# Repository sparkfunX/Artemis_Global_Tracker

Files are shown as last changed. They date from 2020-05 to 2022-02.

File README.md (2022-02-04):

# Artemis Global Tracker

An open source global satellite tracker utilising the [SparkFun Artemis module](https://www.sparkfun.com/products/15484),
[Iridium 9603N satellite transceiver](https://www.iridium.com/products/iridium-9603/) and [u-blox ZOE-M8Q GNSS](https://www.u-blox.com/en/product/zoe-m8-series).

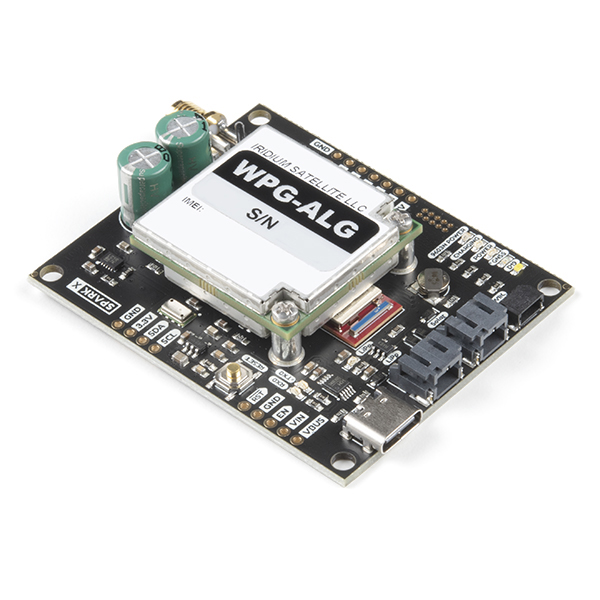
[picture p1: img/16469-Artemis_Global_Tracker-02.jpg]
SparkX Artemis Global Tracker (SPX-16469) (https://www.sparkfun.com/products/16469)


[*SparkX Artemis Global Tracker (SPX-16469)*](https://www.sparkfun.com/products/16469)

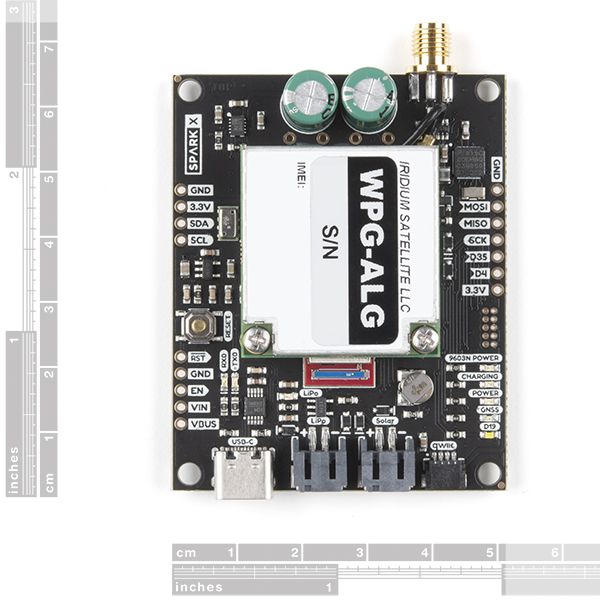
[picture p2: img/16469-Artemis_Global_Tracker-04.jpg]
SparkX Artemis Global Tracker (SPX-16469) (https://www.sparkfun.com/products/16469)


[*SparkX Artemis Global Tracker (SPX-16469)*](https://www.sparkfun.com/products/16469)

## Retired Product

The SparkX Artemis Global Tracker (SPX-16469) has been replaced by the [SparkFun Artemis Global Tracker (WRL-18712)](https://www.sparkfun.com/products/18712).

## Repository Contents

- **/Documentation** - Documentation for the hardware and the full GlobalTracker example
- **/Hardware** - Eagle PCB, SCH and LBR design files
- **/Software** - Arduino examples
- **/Tools** - Tools to help: configure the full GlobalTracker example via USB or remotely via Iridium messaging; and track and map its position
- **/binaries** - binary files for the examples which you can upload using the [Artemis Firmware Upload GUI](https://github.com/sparkfun/Artemis-Firmware-Upload-GUI) instead of the Arduino IDE
- **LICENSE.md** contains the licence information

## Documentation

- [Hardware overview](Documentation/Hardware_Overview/README.md): an overview of the hardware
- The Artemis pin allocation is summarised [here](Documentation/Hardware_Overview/ARTEMIS_PINS.md)
- [Message Format](Documentation/Message_Format/README.md): a definition of the message format and fields (both binary and text) for the full GlobalTracker example
- [GlobalTracker FAQs](Documentation/GlobalTracker_FAQs/README.md): information to help you operate and configure the AGT

## License Information

This product is _**open source**_!

Please review the LICENSE.md file for license information.

If you have any questions or concerns on licensing, please contact technical support on our [SparkFun forums](https://forum.sparkfun.com/viewforum.php?f=123).

Distributed as-is; no warranty is given.

- Your friends at SparkFun.

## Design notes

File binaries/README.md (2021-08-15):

# Artemis Global Tracker: Binaries

This folder contains the binary files for some of the AGT examples.

You can upload these to the AGT using the [Artemis Firmware Upload GUI](https://github.com/sparkfun/Artemis-Firmware-Upload-GUI) instead of the Arduino IDE.
Which is handy if you want to quickly update the firmware in the field, or are not familiar with the IDE.

To use:

* Download and extract the [AGT repo ZIP](https://github.com/sparkfun/Artemis_Global_Tracker/archive/main.zip)
* Download and extract the [AFU repo ZIP](https://github.com/sparkfun/Artemis-Firmware-Upload-GUI/archive/master.zip)
* Run the AFU artemis_firmware_uploader_gui executable for your platform
  * **/Windows** contains the Windows .exe
  * **/OSX** contains an executable for macOS X
  * **/Linux** contains an executable built on Ubuntu
  * **/Raspberry_Pi__Debian** contains an executable for Raspberry Pi 4 (Debian Buster)
* Select the AGT firmware file you'd like to upload (should end in *.bin*)
  * **Example1 - Blink** powers up the tracker and blinks the white LED (connected to D19).
  * **Example14 - Simple Tracker** is a simple tracker which: wakes up every INTERVAL minutes; gets a GNSS fix; reads the PHT sensor; and sends all the data in a SBD message.
  * **Example15 - Better Tracker** is a better tracker where the INTERVAL, RBDESTINATION and RBSOURCE are stored in 'EEPROM' (Flash) and can be configured via Iridium SBD messages.
  * **Example16 - Global Tracker** is the full Global Tracker. All of the settings can be configured via USB-C or remotely via an Iridium SBD message using the [Artemis Global Tracker Configuration Tool (AGTCT)](../Tools).
  * **Example19 - Serial Terminal** allows the AGT to be operated via a simple Serial Terminal interface. Open the Serial Monitor or a Terminal Emulator at 115200 baud to see the menu.
* Attach the AGT target board using USB
* Select the COM port (hit Refresh to refresh the list of USB devices)
* Press Upload

The GUI does take a few seconds to load and run. _**Don't Panic**_ if the GUI does not start right away.

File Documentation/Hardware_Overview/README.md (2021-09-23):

# Artemis Global Tracker: Hardware Overview

The Artemis Global Tracker is an open source satellite tracker utilising the [SparkFun Artemis module](https://www.sparkfun.com/products/15484),
[Iridium 9603N satellite transceiver](https://www.iridium.com/products/iridium-9603/) and [u-blox ZOE-M8Q GNSS
](https://www.u-blox.com/en/product/zoe-m8-series).

The hardware design is based extensively on the:
- [SparkFun Artemis module](https://www.sparkfun.com/products/15484)
- [SparkFun Thing Plus - Artemis](https://www.sparkfun.com/products/15574) battery charging circuit and USB-C interface
- [SparkFun Qwiic Iridium 9603N](https://www.sparkfun.com/products/16394) Iridium 9603N, LTC3225 supercapacitor charger and ADM4210 inrush current circuit
- [SparkFun GPS Breakout - ZOE-M8Q](https://www.sparkfun.com/products/15193) ZOE connections and backup battery circuit

The design also makes use of the:
- [Skyworks AS179-92LF GaAs RF Switch](https://www.skyworksinc.com/products/switches/as179-92lf)
- [Maxtena M1600HCT-P-SMA antenna](https://www.maxtena.com/products/f-gps/m1600hct-p-sma/) which is tuned for Iridium, GPS and GLONASS
  - [Available from SparkFun](https://www.sparkfun.com/products/16838)
- [TE / MEAS Switzerland MS8607](https://www.te.com/usa-en/product-CAT-BLPS0018.html) combined pressure, humidity and temperature sensor

The full schematic for the tracker can be found [here](../../Hardware/Schematic.pdf)

Additional information can be found in the [FAQs](../GlobalTracker_FAQs/README.md)

## The Artemis Module

The heart of the tracker is, of course, the most excellent Artemis module from SparkFun. The pad allocation is defined [here](../Hardware_Overview/ARTEMIS_PINS.md).

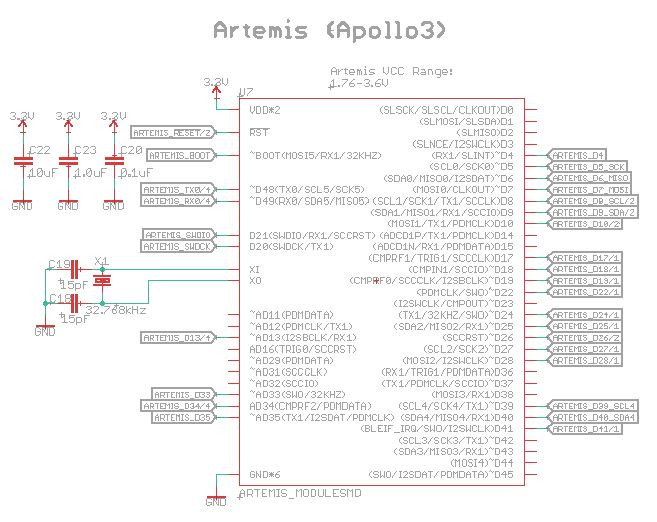
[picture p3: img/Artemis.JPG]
Artemis


## Power Options

The tracker can be powered from:
- the USB-C interface
- a LiPo battery (recharged via the USB-C interface)
- an external solar panel or battery pack (6V maximum)

3 x Energizer&trade; Ultimate Lithium AA or AAA cells are recommended as they will work down to -40C

Low-forward-voltage diodes isolate the power sources from each other. You can have the USB, LiPo and external cells connected simultaneously, it will do no harm.
The tracker will preferentially draw power from USB if it is connected.

If the USB is disconnected, the tracker will preferentially draw power from the external cells. If you have the external cells connected, you may as well disconnect the LiPo.

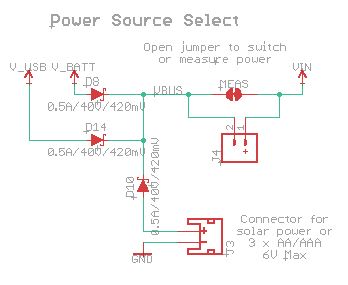
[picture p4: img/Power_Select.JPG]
Power_Select


J4 (VBUS -> VIN) can be used to measure the current draw or to connect a power switch after you open the MEAS split pad.

## USB Interface

The USB interface is taken directly from the [SparkFun Thing Plus - Artemis](https://www.sparkfun.com/products/15574).

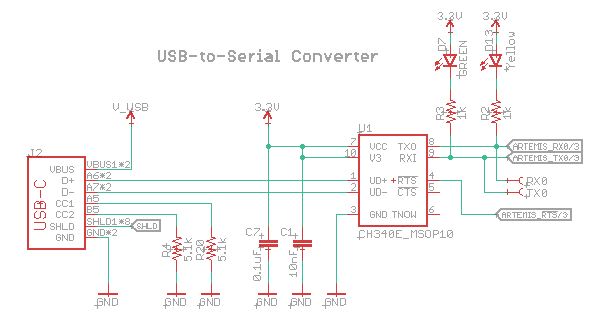
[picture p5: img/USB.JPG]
USB


## LiPo Charger

The LiPo charger circuit is taken directly from the [SparkFun Thing Plus - Artemis](https://www.sparkfun.com/products/15574).

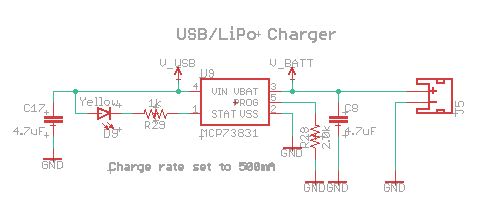
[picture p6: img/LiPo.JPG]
LiPo


## 3.3V Regulator

3.3V power for the tracker is regulated by an AP2112K regulator. Its 50uA quiescent current draw means it can be powered continuously without
depleting the batteries during sleep.

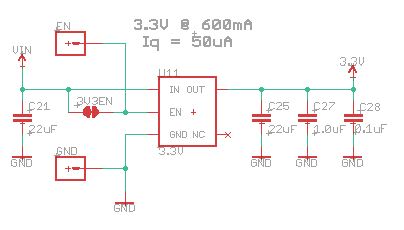
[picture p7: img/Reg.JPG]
Reg


If you want to completely disable the regulator to minimise the current draw, you can do so by opening the 3.3V_EN split pad. The EN pin can then be used to enable/disable the regulator.
Pull EN low to disable the regulator, pull it up to VIN to enable it. EN could also be driven by a logic signal from an external timer circuit.

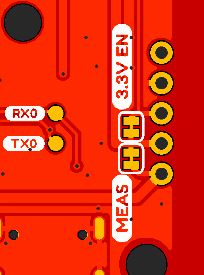
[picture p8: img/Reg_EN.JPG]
Reg_EN


## ZOE-M8Q

GNSS data is provided by the u-blox ZOE-M8Q as used on the [SparkFun GPS Breakout - ZOE-M8Q](https://www.sparkfun.com/products/15193).

Connection to the Artemis is via I2C port 1. The serial and safeboot pins are available on test pads to allow the ZOE firmware to be updated.

Geofence alerts from the ZOE can be produced on PIO14, which is connected to Artemis pin D10.

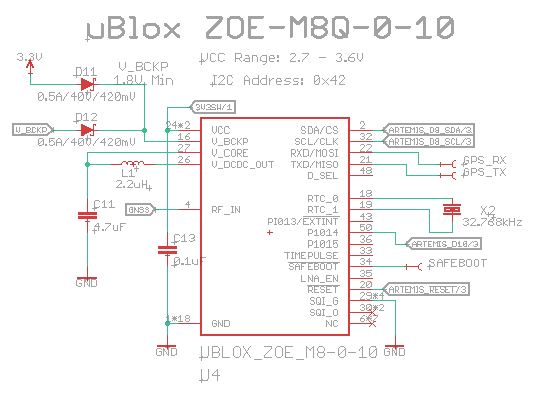
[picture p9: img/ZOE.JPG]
ZOE


Back-up power for the ZOE is drawn preferentially from the 3.3V rail, but there is a small back-up battery too to keep the ZOE's clock running
when all other power sources have been disconnected. The battery recharges only when USB power is connected (to help minimise the 3.3V current
draw during sleep).

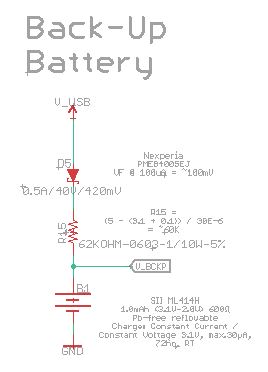
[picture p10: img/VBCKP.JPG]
VBCKP


3.3V power for the ZOE is switched via a FET. The same switched power also feeds the antenna switch when the GNSS is in use.

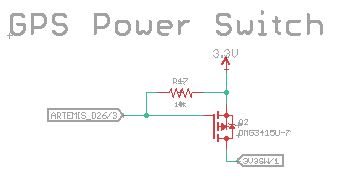
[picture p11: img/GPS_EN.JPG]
GPS_EN


## Iridium 9603N

The tracker uses the same Iridium 9603N transceiver as the [SparkFun Qwiic Iridium 9603N](https://www.sparkfun.com/products/16394).

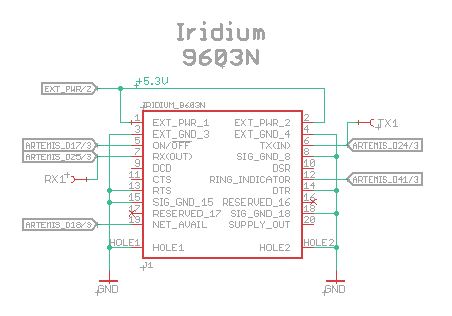
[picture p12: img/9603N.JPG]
9603N


Power for the 9603N is provided by the same LTC3225 supercapacitor charger and ADM4210 in-rush current limit circuit as used by the Qwiic Iridium.

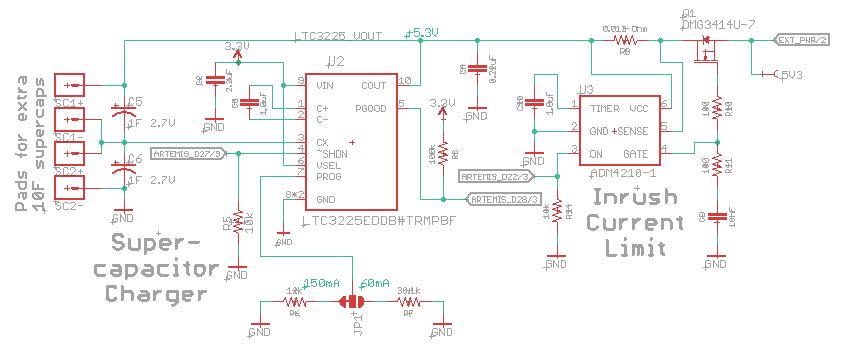
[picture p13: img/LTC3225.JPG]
LTC3225


The LTC3225 charge current is adjustable up to a maximum of 150mA. When set to the full 150mA, the LTC3225 can match the 145mA average current
drawn by the 9603N during transmit. This means that 1 Farad supercapacitors are adequate as they only need to hold enough charge to meet the
9603N's 1.3A peak current draw during the very brief (8.3ms) transmit bursts.

If you want to power the Global Tracker from a low current source, e.g. solar panels, the charge current can be reduced to 60mA by
changing the **Charge Current** jumper link. The 60mA charge current is enough to offset the 9603N's 39mA average current draw during receive,
but bigger supercapacitors are needed to deliver the average current draw during a complete receive/transmit cycle.
So, if you do change the charge current to 60mA, you will also need to solder additional 10 Farad supercapacitors on to
the rear of the PCB using the solder pads provided.

## Antenna Switch

The ZOE and Iridium 9603N share the antenna via a [Skyworks AS179-92LF GaAs RF Switch](https://www.skyworksinc.com/products/switches/as179-92lf).

Care needs to be taken that the 3.3V GNSS and 5.3V 9603N are not powered up simultaneously as _bad things might happen to the AS179_.

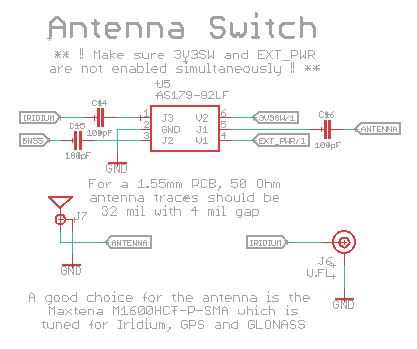
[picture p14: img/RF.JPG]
RF


## Pressure, Humidity and Temperature Sensor

Pressure, humidity and temperature readings are provided by a [TE / MEAS Switzerland MS8607](https://www.te.com/usa-en/product-CAT-BLPS0018.html) combined sensor.
The MS8607 shares I2C port 1 with the ZOE.

The sensor will provide pressure readings as low as 10mbar which is equivalent to an altitude of approximately 31,000m.

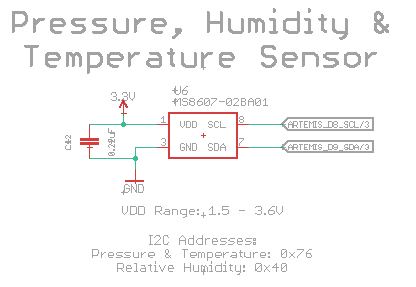
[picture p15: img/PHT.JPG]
PHT


## I/O Pins

The Artemis' SPI and I2C (port 1) pins are broken out on pin headers so the user can connect external peripherals.

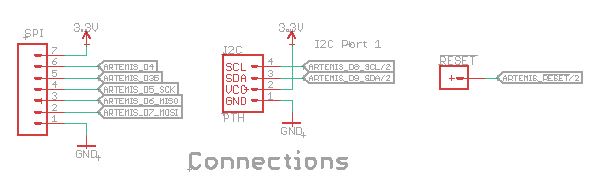
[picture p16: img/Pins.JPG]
Pins


I2C port 4 is broken out on a standard SparkFun Qwiic connector.

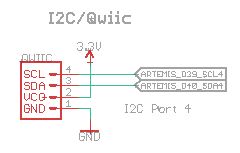
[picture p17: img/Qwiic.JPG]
Qwiic


## Bus Voltage

The bus voltage (from the USB, LiPo or external cells) can be measured via the Artemis pin AD13. A simple two resistor divider divides the bus voltage by three.
Power to the resistor divider is switched by an N-FET so the power draw can be minimised during sleep.

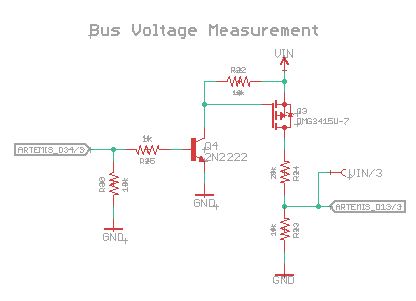
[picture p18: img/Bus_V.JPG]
Bus_V


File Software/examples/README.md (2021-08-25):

# Artemis Global Tracker Examples

These examples demonstrate how to use the Artemis Global Tracker. There are examples showing: how to communicate with the MS8607 PHT sensor;
how to get a fix from the ZOE-M8Q GNSS; how to set up a geofence and how to wake up the Artemis when the geofence status changes;
how to send Iridium Short Burst Data (SBD) messages and monitor the ring channel for new messages. Example16 contains the code
for the full GlobalTracker.

If you don't want to use the Arduino IDE, you can upload the examples using the [Artemis Firmware Upload GUI](https://github.com/sparkfun/Artemis-Firmware-Upload-GUI) instead.
You will find the binary files in the [binaries folder](../../binaries).

**Example1 - Blink** powers up the tracker and blinks the white LED (connected to D19).

**Example2 - Bus Voltage** demonstrates how to read: the battery (bus) voltage; the internal VCC voltage; the Artemis internal temperature; the VSS (ground) voltage.

**Example3 - PHT** demonstrates how to read the pressure, humidity and temperature from the on-board MS8607 sensor.

**Example4 - External PHT** demonstrates how to read the pressure, humidity and temperature from an [external MS8607 sensor](https://www.sparkfun.com/products/16298) connected to the Qwiic port.

**Example5 - GNSS** demonstrates how to read the tracker's position from the ZOE-M8Q GNSS.

**Example6 - Geofence** demonstrates how to set four geofences around the tracker's current position. The white LED will go out if the tracker is moved outside the largest geofenced area.

**Example7 - Get IMEI** demonstrates how to read the IMEI identifier from the Iridium 9603N modem. You do not need message credits to run this example.

**Example8 - Check CSQ** demonstrates how to read the signal quality from the Iridium 9603N modem. You do not need message credits to run this example.

**Example9 - Get Time** demonstrates how to read the time from the Iridium network. You do not need message credits to run this example.

**Example10 - Basic Send** demonstrates how to send a simple "Hello, world!" message via Iridium. This example will use one message credit each time you run it.

**Example11 - Ring** demonstrates how to monitor the Iridium ring channel and download new messages sent to the tracker. This example will use one or more credits each time
a message is downloaded (depending on the length of the message).

**Example12 - Test Low Power** demonstrates how to put the Artemis into deep sleep and wake it up again every INTERVAL seconds.

**Example13 - Geofence Alert** demonstrates how to set a geofence around the tracker's current position. The Artemis will then go into deep sleep and will be woken up again by the ZOE-M8Q
if the geofence status changes. The ZOE is put into power save mode to help reduce the current draw (to approximately 9mA).

**Example14 - Simple Tracker** is a simple tracker which: wakes up every INTERVAL minutes; gets a GNSS fix; reads the PHT sensor; and sends all the data in a SBD message.
The message is transmitted as text and has the format:
- DateTime,Latitude,Longitude,Altitude,Speed,Course,PDOP,Satellites,Pressure,Temperature,Battery,Count

This example will use two message credits each time a message is sent due to the length of the message.

**Example15 - Better Tracker** is a better tracker where the INTERVAL, RBDESTINATION and RBSOURCE are stored in 'EEPROM' (Flash) and can be configured via Iridium SBD messages.

The message transmit interval can be configured by sending a plain text message to the tracker via the RockBLOCK Gateway using the format _[INTERVAL=nnn]_
where _nnn_ is the new message interval in _minutes_. The interval will be updated the next time the beacon wakes up for a transmit cycle.

If you want to enable message forwarding via the RockBLOCK Gateway, you can do this by including the text _[RBDESTINATION=nnnnn]_ in the message
where _nnnnn_ is the RockBLOCK serial number of the tracker or RockBLOCK you want the messages to be forwarded to. You can disable message forwarding
again by sending a message containing _[RBDESTINATION=0]_. You can change the source serial number which is included in the messages by including the text
_[RBSOURCE=nnnnn]_ in the RockBLOCK message where _nnnnn_ is the serial number of the RockBLOCK 9603N on the tracker. You can concatenate the configuration messages.
Send the following to set all three settings in one go: _[INTERVAL=5][RBDESTINATION=12345][RBSOURCE=54321]_

If message forwarding is enabled, the message format will be (using the above example):
- RB0012345,DateTime,Latitude,Longitude,Altitude,Speed,Course,PDOP,Satellites,Pressure,Temperature,Battery,Count,RB0054321

If message forwarding is enabled, you will be charged twice for each message: once to send it, and once to receive it.

**Example16 - Global Tracker** is the full Global Tracker which has many settings that can be configured and stored in EEPROM. The GlobalTracker can be configured to transmit:
on a GeoFence alert; or when Pressure, Temperature or Humidity limits are exceeded; or if the battery voltage is low. All of the settings can be configured via USB-C
or remotely via a binary format Iridium SBD message.

Messages can be sent in text format (human-readable) or binary format (to save messages credits). You can configure which message fields are included in the message so you only send the data you need.
The [Artemis Global Tracker Configuration Tool (AGTCT)](../../Tools) will generate the configuration messages for you.

You can trigger user-defined functions e.g. to operate an [external relay](https://www.sparkfun.com/products/15093).

You can also include readings from additional external sensors.

You can have the Iridium 9603N monitor the ring channel continuously for new Mobile Terminated messages so it can respond to them immediately,
but this will increase the current draw considerably. This is not recommended for battery-powered applications.

Please refer to the [GlobalTracker FAQs](../../Documentation/GlobalTracker_FAQs/README.md) for more information.

**Example17 - Production Test** is code used to test the Artemis Global Tracker during production. You will need an AGT Test Header to allow this code to run.

**Example18 - Production Test 2** is code used to test the Artemis Global Tracker during production. You will need an AGT Test Header to allow this code to run.

**Example19 - Serial Terminal** allows the AGT to be operated via a simple Serial Terminal interface. Open the Serial Monitor or a Terminal Emulator at 115200 baud to see the menu. You can:
- Read the temperature and pressure from the MS8607
- Read position, velocity and time data from the ZOE-M8Q GNSS
- Check for new Iridium messages
- Send and receive text and binary Iridium messages
- Flush the Iridium Mobile Terminated message queue

**Example20 - GNSS Module Info** reads the module information from the ZOE-M8Q GNSS, allowing you to see what software version it is running

**Example21 - Iridium Serial and Power Test** tests the work-around for v2.1 of the Apollo3 core (where the Iridium modem pulling the Serial1 RX pin low can cause the Artemis to hang)

<br/>

To run the examples, you will need to install **v2.1.0** of the SparkFun Apollo3 core and then set the board to the "**RedBoard Artemis ATP**":
- At the time of writing, v2.1.1 of the core contains a feature which makes communication with the u-blox GNSS problematic. Be sure to use **v2.1.0**
- https://learn.sparkfun.com/tutorials/artemis-development-with-the-arduino-ide
 
You will need to install [this version of the Iridium SBD library](https://github.com/sparkfun/SparkFun_IridiumSBD_I2C_Arduino_Library)
- (Available through the Arduino Library Manager: search for IridiumSBDi2c)

You will also need to install the [Qwiic_PHT_MS8607_Library](https://github.com/sparkfun/SparkFun_PHT_MS8607_Arduino_Library)
- (Available through the Arduino Library Manager: search for SparkFun MS8607)

You also need the [SparkFun u-blox GNSS library](https://github.com/sparkfun/SparkFun_u-blox_GNSS_Arduino_Library)
- (Available through the Arduino Library Manager: search for SparkFun u-blox GNSS)

Basic information on how to install an Arduino library is available [here](https://learn.sparkfun.com/tutorials/installing-an-arduino-library)

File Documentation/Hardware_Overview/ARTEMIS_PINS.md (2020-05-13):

# Artemis Global Tracker: Artemis Pad Allocation

| Module Pad No. | Name | Pin | Allocation |
|---|---|---|---|
| 1 | GND | | Power Ground |
| 2 | GPIO20 | SWDCK | JTAG single wire clock |
| 3 | GPIO49 | RX0 | Bootload RX pin for serial bootloading |
| 4 | GPIO39 | ~D39 | Qwiic SCL |
| 5 | GPIO40 | D40 | Qwiic SDA |
| 6 | GPIO9 | D9 | ZOE-M8Q SDA |
| 7 | BOOT | | Bootload. Hold pin high during reset to initiate bootloader |
| 8 | GPIO10 | D10 | ZOE-M8Q PIO14 (Geofence Alert) |
| 9 | GPIO48 | TX0 | Bootload TX pin for serial bootloading |
| 10 | GPIO21 | SWDIO | JTAG single wire I/O |
| 11 | GPIO8 | D8 | ZOE-M8Q SCL |
| 12 | GPIO5 | ~D5 | SPI SCK or GPIO |
| 13 | GPIO7 | ~D7 | SPI MOSI or GPIO |
| 14 | GPIO35 | ~AD35 | SPI CS(1) or GPIO |
| 15 | GPIO4 | ~D4 | SPI CS(2) or GPIO |
| 16 | GPIO24 | ~D24 | Iridium 9603N TX(In) |
| 17 | GPIO22 | ~D22 | AD4210 ON |
| 18 | GPIO23 | ~D23 | N/C |
| 19 | GPIO27 | ~D27 | LTC3225 SHDN |
| 20 | GPIO14 | D14 | N/C |
| 21 | GPIO28 | ~D28 | LTC3225 PGOOD |
| 22 | GND | | Power |
| 23 | GPIO6 | ~D6 | SPI MISO or GPIO |
| 24 | GPIO32 | ~AD32 | N/C |
| 25 | GPIO25 | ~D25 | Iridium 9603N RX(Out) |
| 26 | GPIO12 | ~AD12 | N/C |
| 27 | GPIO26 | ~D26 | GPS_EN |
| 28 | GPIO13 | ~AD13 | Bus Voltage Measure |
| 29 | GPIO15 | D15 | N/C |
| 30 | GPIO33 | ~AD33/SWO | JTAG SWO |
| 31 | GPIO34 | AD34 | Bus Voltage Measure Enable |
| 32 | GPIO11 | ~AD11 | N/C |
| 33 | GPIO29 | ~AD29 | N/C |
| 34 | XO | | 32kHz Xtal Connection for external 32.768kHz RTC crystal |
| 35 | XI | | 32kHz Xtal Connection for external 32.768kHz RTC crystal |
| 36 | VDD | | Power |
| 37 | VDD | | Power |
| 38 | GND | | Power |
| 39 | GND | | Power |
| 40 | GPIO19 | ~D19 | White LED |
| 41 | GPIO18 | ~D18 | Iridium 9603N Network Available |
| 42 | GPIO16 | AD16 | N/C |
| 43 | GPIO17 | D17 | Iridium 9603N ON/OFF |
| 44 | GPIO31 | ~AD31 | N/C |
| 45 | GPIO41 | D41 | Iridium 9603N Ring Indicator |
| 46 | GPIO45 | ~D45 | N/C |
| 47 | GND | | Power |
| 48 | GPIO2 | D2 | N/C |
| 49 | GPIO1 | D1 | N/C |
| 50 | nRESET | | System Reset Pull pin low to reset system |
| 51 | GPIO0 | D0 | N/C |
| 52 | GPIO43 | ~D43 | N/C |
| 53 | GPIO42 | ~D42 | N/C |
| 54 | GPIO3 | D3 | N/C |
| 55 | GPIO36 | D36 | N/C |
| 56 | GPIO38 | D38 | N/C |
| 57 | GPIO37 | ~D37 | N/C |
| 58 | GPIO44 | ~D44 | N/C |
| 59 | GND | | Power |

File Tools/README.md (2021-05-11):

# Artemis Global Tracker: Tools

Tools to help: configure the full GlobalTracker example via USB or remotely via Iridium messaging; and track and map its position

## /Artemis_Global_Tracker_Configuration_Tool

A Python3 PyQt5 tool to configure the full GlobalTracker example via USB or remotely via Iridium messaging.

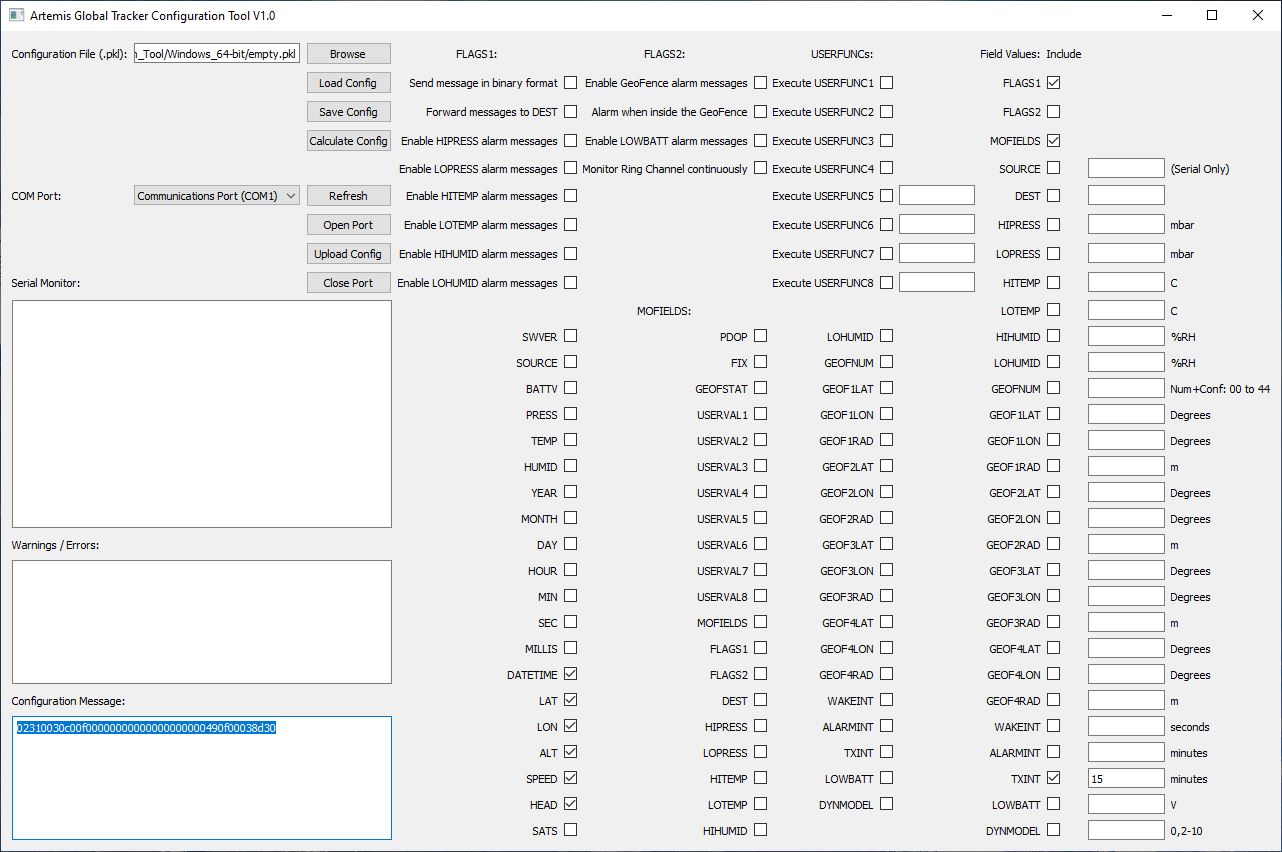
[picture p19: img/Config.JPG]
Config


Please refer to the [GlobalTracker FAQs](../Documentation/GlobalTracker_FAQs/README.md) for full instructions.

### Quickstart:

First select the message fields (MOFIELDS) that you want the tracker to send. If you are going to use the Mapper (see below)
to track the tracker, you need to select **DATETIME**, **LAT**, **LON**, **ALT**, **SPEED** and **HEAD**. Tick the _Include_ checkbox for **MOFIELDS** too
otherwise the settings will not be updated. The Mapper expects text messages, while the Message Translator can translate binary messages.
Depending on which program you want to use, either tick the FLAGS1 _Send message in binary format_ box or ensure it is not ticked.
Tick the **FLAGS1** _Include_ checkbox too to make sure FLAGS1 is updated. Click _Calculate Config_ to generate the configuration message.

You can upload the configuration to a tracker locally by:
  - Connecting the tracker via a USB-C cable
  - Click the _Refresh_ button and select the COM port
  - Click _Open Port_ and you should see a welcome message from the tracker
  - Click _Upload Config_ to send the configuration message to the tracker
  - Check the _Serial Terminal_ to see if the configuration worked
  - Click _Close Port_ and then disconnect the tracker

You can update a tracker remotely by:
  - Right-clicking in the _Configuration Message_ window and select _Select All_
  - Right-click again and select _Copy_
  - Log in to [Rock7 Operations](https://rockblock.rock7.com/Operations)
  - Click on the _Send a Message_ tab
  - Select _Mode Hex_ and paste the configuration message into the _Hex String_ window
  - Tick the RockBLOCK serial number for the tracker(s) you want to update and click _Send Message_
  - The tracker settings will be updated and stored the next time the tracker sends a message

## /Artemis_Global_Tracker_Mapping_Tools

A set of Python tools which will allow you to: download messages from the tracker via a GMail account; stitch the messages together into a single .csv file;
convert the .csv file into .kml files for Google Earth; and display the real-time paths and locations of up to eight trackers using the Google Maps Static API.

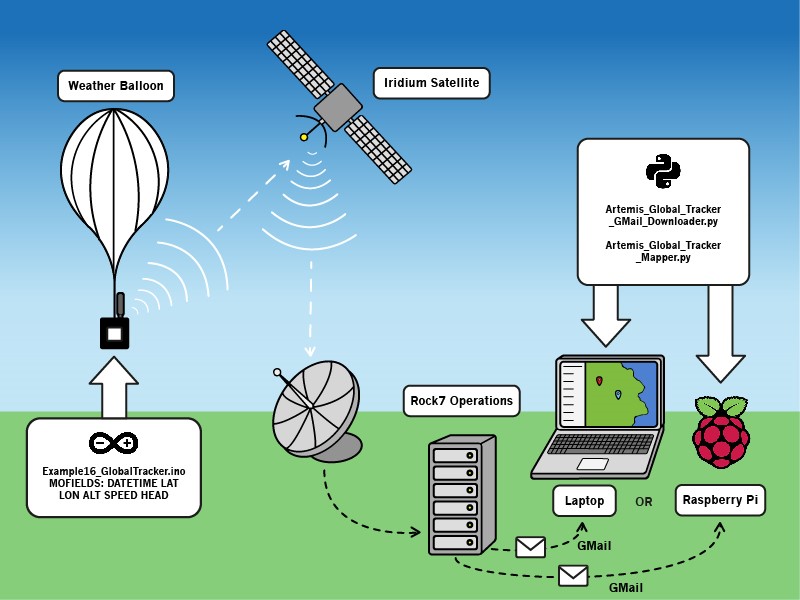
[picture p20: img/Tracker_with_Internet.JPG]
Tracker with Internet


The tools are:
- **Artemis_Global_Tracker_GMail_Downloader.py:** a Python3 tool which uses the GMail API to download messages from the tracker from your GMail account.
- **Artemis_Global_Tracker_Message_Translator.py:** a Python 3 tool to translate binary SBD messages. It can read messages from local files or an IMAP server and optionally create a GPX file from all read messages.
- **Artemis_Global_Tracker_Mapper.py:** a Python3 PyQt5 tool which will read the tracker messages downloaded by the Downloader and display the location and routes of up to eight trackers on Google Maps Static images.
- **Artemis_Global_Tracker_Stitcher.py:** this tool will stitch the individual tracker messages downloaded by the Downloader together into combined .csv files. Each tracker gets its own .csv file.
- **Artemis_Global_Tracker_CSV_DateTime.py:** this tool will convert the first column of the stitched .csv files from YYYYMMDDHHMMSS DateTime format into a more friendly DD/MM/YY,HH:MM:SS format.
- **Artemis_Global_Tracker_DateTime_CSV_to_KML.py:** this tool will convert the .csv files produced by the CSV_DateTime tool into .kml files that can be viewed in Google Earth. The path of the tracker can be shown as: a 2D (course over ground) or 3D (course and altitude) linestring; points (labelled with message sequence numbers); and arrows (indicating the heading of the tracker).
- **Flight_Simulator.py:** this tool generates simulated messages from up to eight virtual trackers. These messages can be used to test the other tools, including the Mapper.

### Artemis_Global_Tracker_GMail_Downloader.py:

Artemis_Global_Tracker_GMail_Downloader.py is a Python3 tool which uses the GMail API to download messages from the tracker from your GMail account.

Create yourself a GMail account. You can then add that email address to the _Delivery Group_ for your tracker in [Rock7 Operations](https://rockblock.rock7.com/Operations). Choose _EMAIL_ROCKBLOCK_ as the message format.

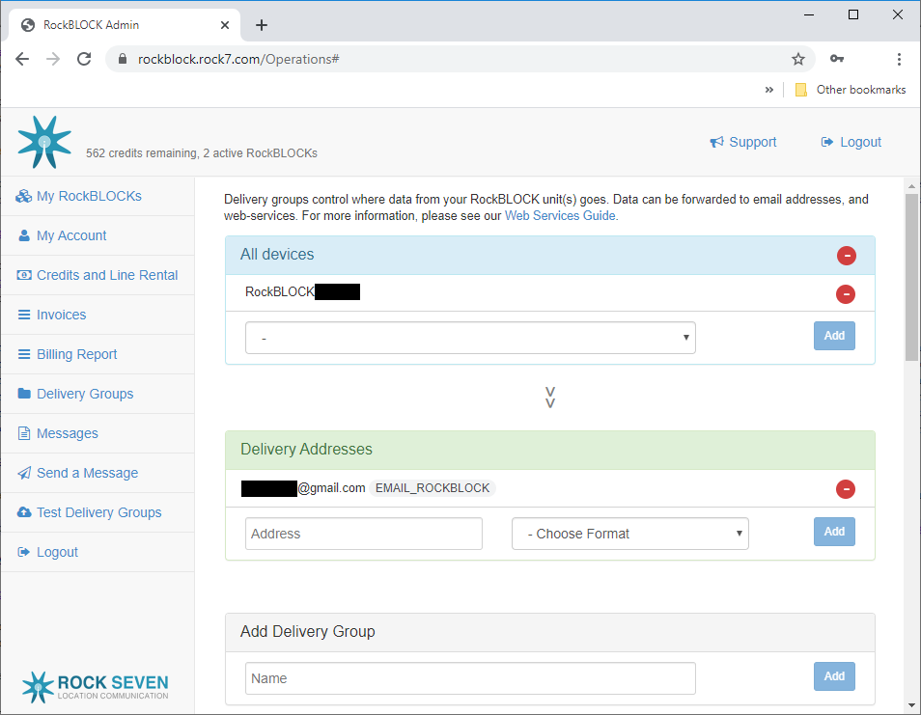
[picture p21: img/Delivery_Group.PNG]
Delivery Group


Log in to your GMail account in a web browser and create a 'label' (folder) called _SBD_. You can do this by: selecting an email in your inbox; then click on the _Move to_ icon
(the folder icon with the right arrow); select _Create new_; enter _SBD_ as the new label name; leave the Nest box empty; click _Create_. Your tracker messages will be automatically
moved to this label by the Downloader to avoid clogging up your inbox.

The Downloader requires access to your GMail credentials. Follow [these instructions](https://developers.google.com/gmail/api/quickstart/python)
to create your credentials and enable access for Python. After you have run the quickstart.py you will need to delete your token.pickle file as the
Downloader needs _modify_ permissions and quickstart.py only requests _readonly_ permissions. A new token.pickle will be created when you run the
Downloader.

You may see a warning message in your browser when you log in to authenticate the new token.pickle. This is normal. Follow the _Advanced_ link; then _Go to Quickstart (unsafe)_;
then click _Allow_; then click _Allow_ again. If the credentials were created successfully, you should see the message _The authentication flow has completed. You may close this window._

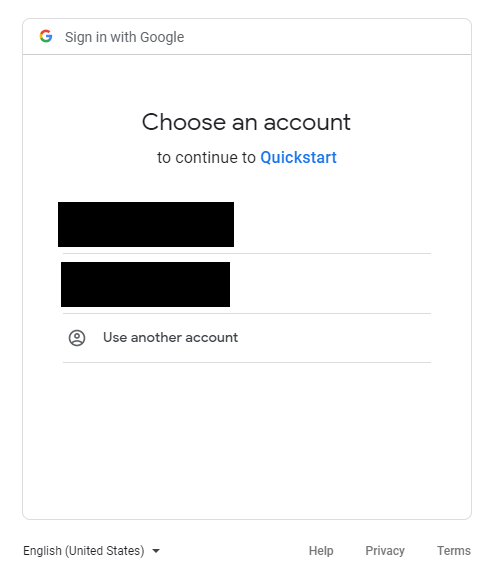
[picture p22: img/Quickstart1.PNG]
Quickstart1

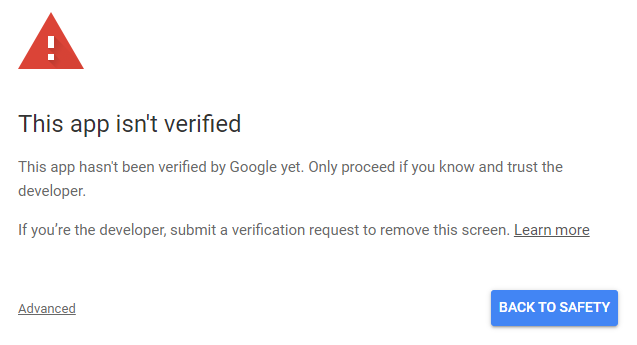
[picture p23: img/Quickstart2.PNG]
Quickstart2

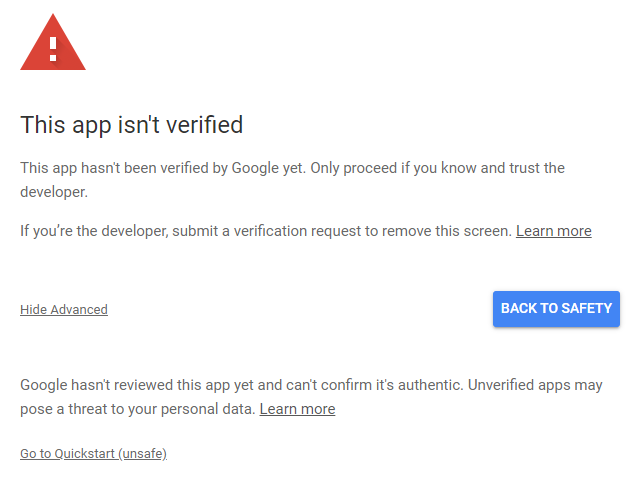
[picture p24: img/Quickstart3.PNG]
Quickstart3

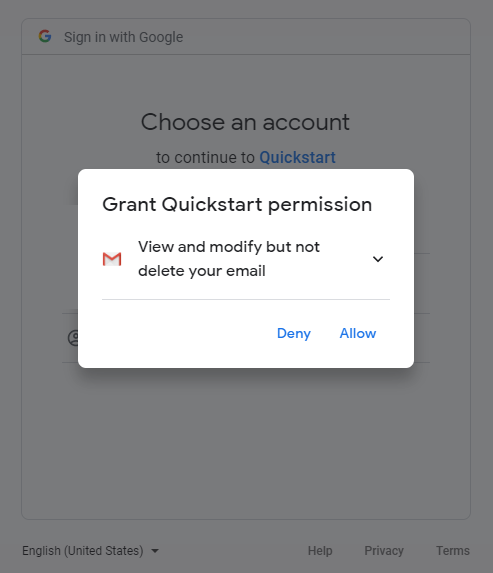
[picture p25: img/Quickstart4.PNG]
Quickstart4

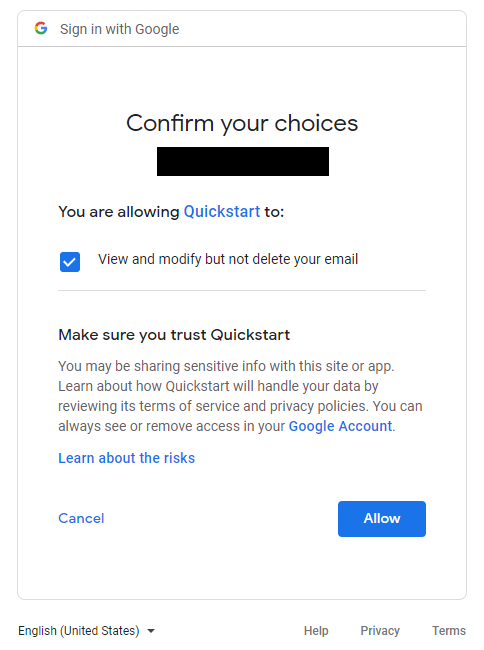
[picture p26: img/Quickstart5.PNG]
Quickstart5


When you run the Downloader, it will automatically check your GMail inbox every 15 seconds for new tracker messages. When it finds one, it will download the SBD .bin attachment to to your computer,
mark the message as seen (read) and 'move' it to a folder called SBD by changing the message labels. This avoids clogging up your inbox. All of the messages are in SBD if you need to download the
attachments again.

### Artemis_Global_Tracker_Message_Translator.py:

A command-line script to translate binary SBD messages. Give the files to translate as argument, e.g. `*.bin`. To write coordinates into a GPX track, use the `-o` option combined with an output filename.
Example:
```
python3 Artemis_Global_Tracker_Message_Translator.py *.bin -o track.gpx
```

Alternatively, messages can be read from email attachments from an IMAP server with the `-i` option. In this case, give the name of an ini file with the server details as argument. The ini file should
look as follows:
```
[email]
host = imap.mymailserver.com
user = myusername
password = mypassword
from = 300123456789012@rockblock.rock7.com
```
Adjust the entries according to your configuration. The `from` entry filters messages according to sender and is handy to select messages from a specific device. Write just `@rockblock.rock7.com`
to process all messages from RockBLOCK. By default, the script only retrieves new messages. Use the `-a` option to retrieve all messages. Example for invoking the script:
```
python3 Artemis_Global_Tracker_Message_Translator.py -i imap_settings.ini -a -o track.gpx
```

### Artemis_Global_Tracker_Mapper.py:

Mapper

Artemis_Global_Tracker_Mapper.py uses the Google Maps Static API to display the location and paths of up to eight trackers. The code will check
for the arrival of new .bin SBD messages, downloaded by the Downloader, every 15 seconds. When it finds one, it will display the location and path
of the tracker on a Google Maps Static API image.

If you are going to use the _Mapper_, run that first and tell it to ignore any existing .bin messages (if you want to).
Then start the _Downloader_. The downloader will download any new messages received by your GMail account from Rock7.
The Mapper will then pick them up and display your tracker's location.

You can find more details about the Maps Static API [here](https://developers.google.com/maps/documentation/maps-static/intro). Sadly, the API is not free.
You can find details of the pricing and plans [here](https://developers.google.com/maps/documentation/maps-static/usage-and-billing).

Follow [these instructions](https://developers.google.com/maps/documentation/maps-static/get-api-key)
to get your own key and copy and paste it into a file called _Google_Static_Maps_API_Key.txt_ so the mapper can read it.

You will need to download _map_image_blank.png_ too. This is displayed until a .bin file is processed or whenever the GUI isn't able to download map images from the API.

The displayed map is automatically centered on the position of a new tracker. The center position can be changed by left-clicking in the image. The zoom level defaults to '15'
but can be changed using the zoom buttons.

Each tracker gets its own colored button which matches the color of its map icon. Clicking on a tracker button will center the map on its location.

Each tracker's path is displayed as a coloured line on the map. The Maps Static API can only accept requests up to 8K bytes in length. When tracking multiple trackers it is
easy to exceed this and so the start of each tracker's route is automatically truncated if required.

You can change the Mapper's _Update Interval_ using the drop down menu. Selecting a longer interval will reduce the number of Maps Static API requests.

The GUI uses 640x480 pixel map images. Higher resolution images are available if you have a premium plan with Google.

### Artemis_Global_Tracker_Stitcher.py:

Artemis_Global_Tracker_Stitcher.py will stitch the .bin SBD attachments downloaded by Artemis_Global_Tracker_GMail_Downloader.py together into a single .csv (Comma Separated Value)
file which can be opened by (e.g.) Microsoft Excel or LibreOffice Calc. Each tracker gets its own .csv file.

### Artemis_Global_Tracker_CSV_DateTime.py:

Artemis_Global_Tracker_CSV_DateTime.py will convert the first column of the stitched .csv file from YYYYMMDDHHMMSS format into DD/MM/YY,HH:MM:SS format, making the message
timing easier to interpret using Excel or Calc.

### Artemis_Global_Tracker_DateTime_CSV_to_KML.py:

Artemis_Global_Tracker_DateTime_CSV_to_KML.py will convert the .csv file produced by Artemis_Global_Tracker_CSV_DateTime.py into .kml files which can be opened in Google Earth.
The complete path of the tracker can be shown as: a 2D (course over ground) or 3D (course and altitude) linestring; points (labelled with message sequence numbers);
and arrows (indicating the heading of the tracker).

You will need to install simplekml to allow the code to run:
- pip install simplekml

### Flight_Simulator.py:

Also included is a _Flight Simulator_ tool which will generate fake .bin SBD messages for eight virtual trackers travelling from
St. James' Park (Newcastle, UK) to The Stadium of Light (Sunderland, UK) and reaching an altitude of 30km along the way.
You can use this tool to test both the Mapper and the Stitcher / CSV / KML converters.

Google_Earth

You can edit the code to create your own UK flight paths. The code uses Hannah Fry's Latitude and Longitude to OSGB coordinate converter.

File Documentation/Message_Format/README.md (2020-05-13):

# Artemis Global Tracker: Message Format and Fields

This document defines the message format used by the full GlobalTracker example.

The Iridium 9603N and the RockBLOCK Gateway support messaging in both text and binary format. Text is human-readable; binary is more compact and will use fewer message credits.

- Mobile Originated (MO) messages are messages sent _by_ the tracker.
- The maximum MO message length is **340** bytes.

- Mobile Terminated (MT) messages are messages sent _to_ the tracker.
- The maximum MT message length is **270** bytes.

Messages can be sent in both formats in both directions. However, for the Artemis Tracker we define that:

- MO messages can be sent in binary or text format.
- MT messages are only used to configure the tracker (remotely) and so should be sent in binary format only.

The [Tools](../../Tools) folder contains a tool which will generate a configuration message in ASCII-encoded Hex format,
which you can then send to the tracker via the _Send a Message_ function in Rock7 Operations. You can of course configure the tracker via USB-C too.

## The message formats:

### Text

This section defines the format of MO _text_ messages sent by the tracker.

The general format is:

| Header | , | Field 1 | , | Field 2 | , | ... | , | Field n |
|---|---|---|---|---|---|---|---|---|

- Gateway Header: **OPTIONAL** - 9 characters - [see below](#gateway-header) - followed by a comma (to make it easy to split the message string)
- Message Fields: sent as ASCII text in Comma Separated Value (CSV) format

MOFIELDS defines which message fields are to be or are being sent. The fields are sent in ascending ID order.

The length of each field will vary depending on the value it contains.

---
### Binary

This section defines the format of MO and MT _binary_ messages sent by or to the tracker.

The general format is:

| Header | STX | ID 1 | Data | ID 2 | Data | ... | ID n | Data | ETX | CS_A | CS_B
|---|---|---|---|---|---|---|---|---|---|---|---|

- Gateway Header: **OPTIONAL** - 5 bytes - [see below](#gateway-header)
- STX: 0x02
- Message fields: sent as a single unsigned byte (uint8_t) field ID followed by the correct number of data bytes for that field
- ETX: 0x03
- Checksum A: a single unsigned byte (uint8_t) containing the modulo-256 checksum of all bytes between the STX and ETX bytes (STX and ETX are included in the checksum but the gateway header is excluded)
- Checksum B: a single unsigned byte (uint8_t) modulo-256 cumulative sum of the checksum bytes

The checksum bytes are as defined in the 8-Bit Fletcher Algorithm, used by the TCP standard (RFC 1145), and are the same as those used by u-blox UBX format messages.

```
CS_A = 0, CS_B = 0
For(I=0;I<N;I++)
{
  CS_A = CS_A + Buffer[I]
  CS_B = CS_B + CS_A
}
```

---
### Gateway Header:

The Rock7 RockBLOCK Gateway allows you to automatically forward messages from one RockBLOCK (Iridium transceiver) to another, so long as they are
both registered to the same account. This is a powerful feature as it means you can send messages between trackers, anywhere, without needing an internet connection.

For text messages: the message is prefixed by the letters "RB" plus the RockBLOCK serial number of the destination transceiver padded out to seven digits. E.g. if
the RockBLOCK serial number of the transceiver you want to send the message to is _12345_ then the message would be prefixed with _RB0012345_

For binary messages: the message is still prefixed with ASCII "RB" (0x5242 in Hex) but the serial number is converted to unsigned 24-bit (3-byte) **big-endian** format.
Using the same example, 12345 is 0x003039 in Hex so the message would be prefixed by _0x5242003039_

Please follow [this link](https://docs.rockblock.rock7.com/docs/messaging-between-rockblocks) for further details.

---
### Message Fields

This table defines the Artemis Global Tracker message fields:
- ID: is the _uint8_t_ ID code for the message field
- Abv.: the abreviated field name
- Type: is the data type used to store the field in the tracker code
- Bin_Len: is the length of the data when sent as a binary message (excluding the preceding ID byte)
- Txt_Len: is the _maximum_ field length when sent as a text message (excluding the trailing comma)
- MO: can this field be sent in a Mobile Originated message?
- MT: can this field be set remotely by a Mobile Terminated message?
- USB: can this field be configured via the USB-C serial interface?
- EEPROM: is the data for this field stored in EEPROM?
- Desc.: a brief description of this field

Follow the ID links for a full definition and examples for each field.

If the number of IDs is expanded beyond 0x5f, MOFIELDS will need to be redefined accordingly.

| ID | Abv. | Type | Bin_Len | Txt_Len | MO | MT | USB | EEPROM | Desc. |
|---|---|---|---|---|---|---|---|---|---|
| 0x00 | RESV | | | | | | | | **Reserved - do not use** |
| 0x01 | RESV | | | | | | | | **Reserved - do not use** |
| [0x02](#stx-0x02) | STX | | | | | | | Yes | ASCII STX - used to indicate the start of a binary message |
| [0x03](#etx-0x03) | ETX | | | | | | | Yes | ASCII ETX - used to indicate the end of a binary message |
| [0x04](#swver-0x04) | SWVER | byte | 1 | 5 | Yes | No | No | Yes | The tracker software version |
| 0x05 | RESV | | | | | | | | **Reserved - do not use** |
| 0x06 | RESV | | | | | | | | **Reserved - do not use** |
| 0x07 | RESV | | | | | | | | **Reserved - do not use** |
| [0x08](#source-0x08) | SOURCE | uint32_t | 4 | 7 | Yes | No | Yes | Yes | The source address = the tracker's RockBLOCK serial number |
| [0x09](#battv-0x09) | BATTV | uint16_t | 2 | 4 | Yes | No | No | No | The battery voltage (actually the bus voltage) |
| [0x0a](#press-0x0a) | PRESS | uint16_t | 2 | 4 | Yes | No | No | No | The atmospheric pressure in mbar |
| [0x0b](#temp-0x0b) | TEMP | int16_t | 2 | 6 | Yes | No | No | No | The atmospheric temperature in Centigrade |
| [0x0c](#humid-0x0c) | HUMID | uint16_t | 2 | 6 | Yes | No | No | No | The atmospheric humidity in %RH |
| [0x0d](#year-0x0d) | YEAR | uint16_t | 2 | 4 | Yes | No | No | No | UTC year |
| [0x0e](#month-0x0e) | MONTH | byte | 1 | 2 | Yes | No | No | No | UTC month |
| [0x0f](#day-0x0f) | DAY | byte | 1 | 2 | Yes | No | No | No | UTC day |
| [0x10](#hour-0x10) | HOUR | byte | 1 | 2 | Yes | No | No | No | UTC hour |
| [0x11](#min-0x11) | MIN | byte | 1 | 2 | Yes | No | No | No | UTC minute |
| [0x12](#sec-0x12) | SEC | byte | 1 | 2 | Yes | No | No | No | UTC second |
| [0x13](#millis-0x13) | MILLIS | uint16_t | 2 | 3 | Yes | No | No | No | UTC milliseconds |
| [0x14](#datetime-0x14) | DATETIME | | 7 | 14 | Yes | No | No | No | Concatenated UTC Date & Time |
| [0x15](#lat-0x15) | LAT | int32_t | 4 | 11 | Yes | No | No | No | The latitude in degrees |
| [0x16](#lon-0x16) | LON | int32_t | 4 | 12 | Yes | No | No | No | The longitude in degrees |
| [0x17](#alt-0x17) | ALT | int32_t | 4 | 9 | Yes | No | No | No | The altitude above MSL |
| [0x18](#speed-0x18) | SPEED | int32_t | 4 | 7 | Yes | No | No | No | The ground speed |
| [0x19](#head-0x19) | HEAD | int32_t | 4 | 6 | Yes | No | No | No | The course (heading) in degrees |
| [0x1a](#sats-0x1a) | SATS | byte | 1 | 2 | Yes | No | No | No | The number of satellites (space vehicles) used in the solution |
| [0x1b](#pdop-0x1b) | PDOP | uint16_t | 2 | 6 | Yes | No | No | No | The positional dilution of precision |
| [0x1c](#fix-0x1c) | FIX | byte | 1 | 1 | Yes | No | No | No | The GNSS fix type |
| [0x1d](#geofstat-0x1d) | GEOFSTAT | 3 x byte | 3 | 6 | Yes | No | No | No | The geofence status |
| 0x1e - 0x1f | | | | | | | | | **Currently undefined - do not use** |
| [0x20](#userval1-0x20) | USERVAL1 | byte | 1 | 3 | Yes | No | No | No | User value 1 (e.g. from an external sensor) |
| [0x21](#userval2-0x21) | USERVAL2 | byte | 1 | 3 |Yes | No | No | No | User value 2 |
| [0x22](#userval3-0x22) | USERVAL3 | uint16_t | 2 | 5 |Yes | No | No | No | User value 3 |
| [0x23](#userval4-0x23) | USERVAL4 | uint16_t | 2 | 5 |Yes | No | No | No | User value 4 |
| [0x24](#userval5-0x24) | USERVAL5 | uint32_t | 4 | 10 |Yes | No | No | No | User value 5 |
| [0x25](#userval6-0x25) | USERVAL6 | uint32_t | 4 | 10 |Yes | No | No | No | User value 6 |
| [0x26](#userval7-0x26) | USERVAL7 | float | 4 | 14 |Yes | No | No | No | User value 7 |
| [0x27](#userval8-0x27) | USERVAL8 | float | 4 | 14 |Yes | No | No | No | User value 8 |
| 0x28 - 0x2f | | | | | | | | | **Currently undefined - do not use** |
| [0x30](#mofields-0x30) | MOFIELDS | 3 x uint32_t | 12 | 24 | Yes | Yes | Yes | Yes | Defines which fields are included in MO messages |
| [0x31](#flags1-0x31) | FLAGS1 | byte | 1 | 2 | Yes | Yes | Yes | Yes | Defines various message options - see below for the full definition |
| [0x32](#flags2-0x32) | FLAGS2 | byte | 1 | 2 | Yes | Yes | Yes | Yes | Defines various message options - see below for the full definition |
| [0x33](#dest-0x33) | DEST | uint32_t | 4 | 7 | Yes | Yes | Yes | Yes | The destination RockBLOCK serial number for message forwarding |
| [0x34](#hipress-0x34) | HIPRESS | uint16_t | 2 | 4 | Yes | Yes | Yes | Yes | The high pressure alarm limit |
| [0x35](#lopress-0x35) | LOPRESS | uint16_t | 2 | 4 | Yes | Yes | Yes | Yes | The low pressure alarm limit |
| [0x36](#hitemp-0x36) | HITEMP | int16_t | 2 | 6 | Yes | Yes | Yes | Yes | The high temperature alarm limit |
| [0x37](#lotemp-0x37) | LOTEMP | int16_t | 2 | 6 | Yes | Yes | Yes | Yes | The low temperature alarm limit |
| [0x38](#hihumid-0x38) | HIHUMID | uint16_t | 2 | 6 | Yes | Yes | Yes | Yes | The high humidity alarm limit |
| [0x39](#lohumid-0x39) | LOHUMID | uint16_t | 2 | 6 | Yes | Yes | Yes | Yes | The low humidity alarm limit |
| [0x3a](#geofnum-0x3a) | GEOFNUM | byte | 1 | 2 | Yes | Yes | Yes | Yes | The number of geofences (0-4) and confidence level (0-4) |
| [0x3b](#geof1lat-0x3b) | GEOF1LAT | int32_t | 4 | 11 | Yes | Yes | Yes | Yes | The latitude of the center of geofence circle 1 |
| [0x3c](#geof1lon-0x3c) | GEOF1LON | int32_t | 4 | 12 | Yes | Yes | Yes | Yes | The longitude of the center of geofence circle 1 |
| [0x3d](#geof1rad-0x3d) | GEOF1RAD | uint32_t | 4 | 9 | Yes | Yes | Yes | Yes | The radius of geofence circle 1 |
| [0x3e](#geof2lat-0x3e) | GEOF2LAT | int32_t | 4 | 11 | Yes | Yes | Yes | Yes | The latitude of the center of geofence circle 2 |
| [0x3f](#geof2lon-0x3f) | GEOF2LON | int32_t | 4 | 12 | Yes | Yes | Yes | Yes | The longitude of the center of geofence circle 2 |
| [0x40](#geof2rad-0x40) | GEOF2RAD | uint32_t | 4 | 9 | Yes | Yes | Yes | Yes | The radius of geofence circle 2 |
| [0x41](#geof3lat-0x41) | GEOF3LAT | int32_t | 4 | 11 | Yes | Yes | Yes | Yes | The latitude of the center of geofence circle 3 |
| [0x42](#geof3lon-0x42) | GEOF3LON | int32_t | 4 | 12 | Yes | Yes | Yes | Yes | The longitude of the center of geofence circle 3 |
| [0x43](#geof3rad-0x43) | GEOF3RAD | uint32_t | 4 | 9 | Yes | Yes | Yes | Yes | The radius of geofence circle 3 |
| [0x44](#geof4lat-0x44) | GEOF4LAT | int32_t | 4 | 11 | Yes | Yes | Yes | Yes | The latitude of the center of geofence circle 4 |
| [0x45](#geof4lon-0x45) | GEOF4LON | int32_t | 4 | 12 | Yes | Yes | Yes | Yes | The longitude of the center of geofence circle 4 |
| [0x46](#geof4rad-0x46) | GEOF4RAD | uint32_t | 4 | 9 | Yes | Yes | Yes | Yes | The radius of geofence circle 4 |
| [0x47](#wakeint-0x47) | WAKEINT | uint32_t | 4 | 5 | Yes | Yes | Yes | Yes | Defines the tracker's wake-up interval (seconds)  |
| [0x48](#alarmint-0x48) | ALARMINT | uint16_t | 2 | 4 | Yes | Yes | Yes | Yes | Defines the tracker's transmission interval during an alarm (minutes)  |
| [0x49](#txint-0x49) | TXINT | uint16_t | 2 | 4 | Yes | Yes | Yes | Yes | Defines the tracker's normal transmission interval (minutes)  |
| [0x4a](#lowbatt-0x4a) | LOWBATT | uint16_t | 2 | 4 | Yes | Yes | Yes | Yes | The low battery limit |
| [0x4b](#dynmodel-0x4b) | DYNMODEL | byte | 1 | 2 | Yes | Yes | Yes | Yes | The GNSS dynamic platform model |
| 0x4c - 0x51 | | | | | | | | | **Currently undefined - do not use** |
| 0x52 | RBHEAD | | 4 | | | | | | **ASCII "R" - Reserved for the RockBLOCK gateway header (message forwarding)** |
| 0x53 - 0x57 | | | | | | | | | **Currently undefined - do not use** |
| [0x58](#userfunc1-0x58) | USERFUNC1 | N/A | 0 | N/A | No | Yes | Yes | N/A | Instructs the tracker to execute user function 1 |
| [0x59](#userfunc2-0x59) | USERFUNC2 | N/A | 0 | N/A | No | Yes | Yes | N/A | Instructs the tracker to execute user function 2 |
| [0x5a](#userfunc3-0x5a) | USERFUNC3 | N/A | 0 | N/A | No | Yes | Yes | N/A | Instructs the tracker to execute user function 3 |
| [0x5b](#userfunc4-0x5b) | USERFUNC4 | N/A | 0 | N/A | No | Yes | Yes | N/A | Instructs the tracker to execute user function 4 |
| [0x5c](#userfunc5-0x5c) | USERFUNC5 | uint16_t | 2 | N/A | No | Yes | Yes | N/A | Instructs the tracker to execute user function 5 |
| [0x5d](#userfunc6-0x5d) | USERFUNC6 | uint16_t | 2 | N/A | No | Yes | Yes | N/A | Instructs the tracker to execute user function 6 |
| [0x5e](#userfunc7-0x5e) | USERFUNC7 | uint32_t | 4 | N/A | No | Yes | Yes | N/A | Instructs the tracker to execute user function 7 |
| [0x5f](#userfunc8-0x5f) | USERFUNC8 | uint32_t | 4 | N/A | No | Yes | Yes | N/A | Instructs the tracker to execute user function 8 |

---
### Field Definition

The uint16_t, uint32_t and float examples are calculated using:
- https://www.binaryconvert.com/convert_signed_short.html
- https://www.binaryconvert.com/convert_signed_int.html
- https://www.binaryconvert.com/convert_float.html

---
STX (0x02)
---

| Description: | ASCII STX - used to indicate the start of a binary message (not used in text messages) |
|---|---|

---
ETX (0x03)
---

| Description: | ASCII ETX - used to indicate the end of a binary message (not used in text messages) |
|---|---|

---
SWVER (0x04)
---

| []() | |
|---|---|
| Description: | The tracker software version. |
| Binary: | byte, the 4 most significant bits indicate the major software version, the 4 least significant bits indicate the minor software version. |
| Text: | Sent in the format m.m in the range 0.0 to 15.15 |
| Example value: | Major version 1, minor version 3 |
| Binary example: | 0x0413 |
| Text example: | 1.3 |

---
SOURCE (0x08)
---

| []() | |
|---|---|
| Description: | The source address = the tracker's RockBLOCK serial number. |
| Binary: | uint32_t, 4 bytes, little endian. |
| Text: | Sent in the format nnnnn in the range 0 to 9999999 |
| Example value: | 12345 |
| Binary example: | 0x0839300000 (12345 is 0x00003039) |
| Text example: | 12345 |

---
BATTV (0x09)
---

| []() | |
|---|---|
| Description: | The battery voltage (actually the bus voltage; the battery voltage minus a small diode voltage drop). |
| Binary: | uint16_t, 2 bytes, little endian, in Volts * 10^-2. |
| Text: | Sent in the format v.v with 1 or 2 decimal places in the range 0.0 to 9.99 |
| Example value: | 3.60V |
| Binary example: | 0x096801 (360 is 0x0168) |
| Text example: | 3.6 |

---
PRESS (0x0a)
---

| []() | |
|---|---|
| Description: | The atmospheric pressure in mbar. |
| Binary: | uint16_t, 2 bytes, little endian, in mbar. |
| Text: | Sent in the format nnnn in the range 0 to 1084 (approx.) |
| Example value: | 998 |
| Binary example: | 0x0ae603 (998 is 0x03e6) |
| Text example: | 998 |

---
TEMP (0x0b)
---

| []() | |
|---|---|
| Description: | The atmospheric temperature in Centigrade. |
| Binary: | int16_t (signed), 2 bytes, little endian, in Centigrade * 10^-2. |
| Text: | Sent in the format n.n with 1 or 2 decimal places, signed, in the range -40.0 to 85.0 (approx.) |
| Example value: | -12.34C |
| Binary example: | 0x0b2efb (-1234 is 0xfb2e) |
| Text example: | -12.34 |

---
HUMID (0x0c)
---

| []() | |
|---|---|
| Description: | The atmospheric humidity in %RH. |
| Binary: | uint16_t, 2 bytes, little endian, in %RH * 10^-2. |
| Text: | Sent in the format n.n with 1 or 2 decimal places in the range 0.0 to 100.0 (approx.) |
| Example value: | 12.34%RH |
| Binary example: | 0x0cd204 (1234 is 0x04d2) |
| Text example: | 12.34 |

---
YEAR (0x0d)
---

| []() | |
|---|---|
| Description: | UTC year. |
| Binary: | uint16_t, 2 bytes, little endian. |
| Text: | Sent in the format YYYY |
| Example value: | 2019 |
| Binary example: | 0x0de307 (2019 is 0x07e3) |
| Text example: | 2019 |

---
MONTH (0x0e)
---

| []() | |
|---|---|
| Description: | UTC month. |
| Binary: | byte. |
| Text: | Sent in the format MM _without a preceding zero_ |
| Example value: | 7 |
| Binary example: | 0x0e07 (7 is 0x07) |
| Text example: | 7 |

---
DAY (0x0f)
---

| []() | |
|---|---|
| Description: | UTC day. |
| Binary: | byte. |
| Text: | Sent in the format DD _without a preceding zero_ |
| Example value: | 16 |
| Binary example: | 0x0f10 (16 is 0x10) |
| Text example: | 16 |

---
HOUR (0x10)
---

| []() | |
|---|---|
| Description: | UTC hour. |
| Binary: | byte. |
| Text: | Sent in 24 hour format HH _without a preceding zero_ |
| Example value: | 23 |
| Binary example: | 0x1017 (23 is 0x17) |
| Text example: | 23 |

---
MIN (0x11)
---

| []() | |
|---|---|
| Description: | UTC minute. |
| Binary: | byte. |
| Text: | Sent in the format MM _without a preceding zero_ |
| Example value: | 7 |
| Binary example: | 0x1107 (7 is 0x07) |
| Text example: | 7 |

---
SEC (0x12)
---

| []() | |
|---|---|
| Description: | UTC seconds. |
| Binary: | byte. |
| Text: | Sent in the format SS _without a preceding zero_ |
| Example value: | 23 |
| Binary example: | 0x1217 (23 is 0x17) |
| Text example: | 23 |

---
MILLIS (0x13)
---

| []() | |
|---|---|
| Description: | UTC milliseconds. |
| Binary: | uint16_t, 2 bytes, little endian. |
| Text: | Sent in the format MMM _without preceding zeroes_ |
| Example value: | 470 |
| Binary example: | 0x13d601 (470 is 0x01d6) |
| Text example: | 470 |

---
DATETIME (0x14)
---

| []() | |
|---|---|
| Description: | Concatenated UTC date and time. |
| Binary: | 7 bytes, YYMDHMS, year is little endian. |
| Text: | Sent in the format YYYYMMDDHHMMSS **with preceding zeroes as required** |
| Example value: | 2019/7/16 23:07:23 |
| Binary example: | 0x14e3070710170717 |
| Text example: | 20190716230723 |

---
LAT (0x15)
---

| []() | |
|---|---|
| Description: | The latitude in degrees. |
| Binary: | int32_t (signed), 4 bytes, little endian, in degrees * 10^-7. |
| Text: | Sent in the format -d.d with up to 7 decimal places in the range -90.0 to 90.0 _without preceding or trailing zeroes_ |
| Example value: | 40 degrees South |
| Binary example: | 0x15007c28e8 (-400000000 is 0xe8287c00) |
| Text example: | -40.0 |

---
LON (0x16)
---

| []() | |
|---|---|
| Description: | The longitude in degrees. |
| Binary: | int32_t (signed), 4 bytes, little endian, in degrees * 10^-7. |
| Text: | Sent in the format -d.d with up to 7 decimal places in the range -180.0 to 179.9999999 _without preceding or trailing zeroes_ |
| Example value: | 170 degrees West |
| Binary example: | 0x16000fac9a (-1700000000 is 0x9aac0f00) |
| Text example: | -170.0 |

---
ALT (0x17)
---

| []() | |
|---|---|
| Description: | The altitude above MSL. |
| Binary: | int32_t (signed), 4 bytes, little endian, in **mm** above MSL. |
| Text: | Sent as **m** above MSL, with mm resolution, in the format -m.m with up to 3 decimal places in the range -420.0 to 50000.0 _without preceding or trailing zeroes_ |
| Example value: | 123m above MSL |
| Binary example: | 0x1778e00100 (123000 is 0x0001e078) |
| Text example: | 123.0 |

---
SPEED (0x18)
---

| []() | |
|---|---|
| Description: | The ground speed. |
| Binary: | int32_t (signed), 4 bytes, little endian, in **mm/s**. |
| Text: | Sent as **m/s**, with mm/s resolution, in the format s.s with up to 3 decimal places in the range 0.0 to 500.0 _without preceding or trailing zeroes_ |
| Example value: | 10 m/s |
| Binary example: | 0x1810270000 (10000 is 0x00002710) |
| Text example: | 10.0 |

---
HEAD (0x19)
---

| []() | |
|---|---|
| Description: | The heading in degrees. |
| Binary: | int32_t (signed), 4 bytes, little endian, in degrees * 10^-7. |
| Text: | Sent in the format -d.d with **1** decimal place _without preceding zeroes_ |
| Example value: | 45 degrees |
| Binary example: | 0x198074d21a (450000000 is 0x1ad27480) |
| Text example: | 45.0 |

---
SATS (0x1a)
---

| []() | |
|---|---|
| Description: | The number of satellites (space vehicles) used in the position solution. |
| Binary: | byte. |
| Text: | Sent in the format nn _without a preceding zero_ |
| Example value: | 14 |
| Binary example: | 0x1a0e (14 is 0x0e) |
| Text example: | 14 |

---
PDOP (0x1b)
---

| []() | |
|---|---|
| Description: | The positional dilution of precision. |
| Binary: | uint16_t, 2 bytes, little endian, in **cm**. |
| Text: | Sent as **m**, with cm resolution, in the format m.m with 1 or 2 decimal places _without preceding or trailing zeroes_ |
| Example value: | 1.02m |
| Binary example: | 0x1b6600 (102 is 0x0066) |
| Text example: | 1.02 |

---
FIX (0x1c)
---

| []() | |
|---|---|
| Description: | The GNSS fix type as defined in the u-blox PVT message: 0=no fix, 1=dead reckoning, 2=2D, 3=3D, 4=GNSS, 5=Time fix |
| Binary: | byte. |
| Text: | Sent in the format n in the range 0 to 5 |
| Example value: | 3 |
| Binary example: | 0x1c03 (3 is 0x03) |
| Text example: | 3 |

---
GEOFSTAT (0x1d)
---

| []() | |
|---|---|
| Description: | The geofence status as defined in the u-blox UBX-NAV-GEOFENCE message |
| Binary: | 3 x byte: |
| | Byte 0 Bits 7-4: status: 0x0 - Geofencing not available or not reliable; 0x1 - Geofencing active |
| | Byte 0 Bits 3-0: combState: combined (logical OR) state of all geofences: 0x0 - Unknown; 0x1 - Inside; 0x2 - Outside |
| | Byte 1 Bits 7-4: geofence 1 state: 0x0 - Unknown; 0x1 - Inside; 0x2 - Outside |
| | Byte 1 Bits 3-0: geofence 2 state: 0x0 - Unknown; 0x1 - Inside; 0x2 - Outside |
| | Byte 2 Bits 7-4: geofence 3 state: 0x0 - Unknown; 0x1 - Inside; 0x2 - Outside |
| | Byte 2 Bits 3-0: geofence 4 state: 0x0 - Unknown; 0x1 - Inside; 0x2 - Outside |
| Text: | Sent as six ASCII digits: 000000 to 122222 |
| Example value: | Geofencing is active and the tracker is inside all four geofences |
| Binary example: | 0x1d111111 |
| Text example: | 111111 |

---
USERVAL1 (0x20)
---

| []() | |
|---|---|
| Description: | A value defined by the user (e.g. the reading from an external sensor) |
| Binary: | byte. |
| Text: | Sent in the format n in the range 0 to 255 |
| Example value: | 3 |
| Binary example: | 0x2003 (3 is 0x03) |
| Text example: | 3 |

---
USERVAL2 (0x21)
---

See USERVAL1

---
USERVAL3 (0x22)
---

| []() | |
|---|---|
| Description: | A value defined by the user (e.g. the reading from an external sensor) |
| Binary: | uint16_t, 2 bytes, little endian. |
| Text: | Sent in the format n in the range 0 to 65535 |
| Example value: | 3 |
| Binary example: | 0x220300 (3 is 0x0003) |
| Text example: | 3 |

---
USERVAL4 (0x23)
---

See USERVAL3

---
USERVAL5 (0x24)
---

| []() | |
|---|---|
| Description: | A value defined by the user (e.g. the reading from an external sensor) |
| Binary: | uint32_t, 4 bytes, little endian. |
| Text: | Sent in the format n in the range 0 to 4294967295 |
| Example value: | 3 |
| Binary example: | 0x2403000000 (3 is 0x00000003) |
| Text example: | 3 |

---
USERVAL6 (0x25)
---

See USERVAL5

---
USERVAL7 (0x26)
---

| []() | |
|---|---|
| Description: | A value defined by the user (e.g. the reading from an external sensor) |
| Binary: | float, 4 bytes, little endian. |
| Text: | Sent in the format n in the range 3.4028235E+38 to -3.4028235E+38 |
| Example value: | 3.0 |
| Binary example: | 0x2600004040 (3.0 is 0x40400000 (3.0E0)) |
| Text example: | 3.0 |

---
USERVAL8 (0x27)
---

See USERVAL7

---
MOFIELDS (0x30)
---

| []() | |
|---|---|
| Description: | Defines or shows which fields are included in MO messages. |
| Binary: | 3 x uint32_t, **little endian**. The most significant bit of the first uint32_t defines if the field 0x00 will be sent. The least significant bit of the third uint32_t defines if field 0x5f will be sent. |
| Text: | Sent as ASCII-encoded Hex (**little endian**) in the range 000000000000000000000000 to ffffffffffffffffffffffff |
| Example value: | To send (only) DATETIME (0x14), LAT (0x15), LON (0x16) and ALT (0x17) |
| Binary example: | 0x30000f00000000000000000000 |
| Text example: | 000f00000000000000000000 |
| Default value: | 0x000f00000000000000000000 |

**Notes:**

Although MOFIELDS has a bit for every field ID, some are of course reserved / undefined or invalid for MO messages. Each field will only be included if valid for MO messages.

---
FLAGS1 (0x31)
---

| []() | |
|---|---|
| Description: | Defines various message options. |
| Binary: | byte. |
| []() | |
| Bit 7 (MSB): | Set to 1 if binary messages are to be sent / are being sent. Set to 0 for text messages (default). |
| Bit 6: | When set to 1, message forwarding via the RockBLOCK gateway is enabled. Message will be forwarded automatically to RB DEST. |
| Bit 5: | When set to 1, a message will be sent when PRESS > HIPRESS. PRESS is checked every WAKEINT seconds. Messages will be sent every ALARMINT minutes until PRESS is < HIPRESS. |
| Bit 4: | When set to 1, a message will be sent when PRESS < LOPRESS. PRESS is checked every WAKEINT seconds. Messages will be sent every ALARMINT minutes until PRESS is > LOPRESS. |
| Bit 3: | When set to 1, a message will be sent when TEMP > HITEMP. TEMP is checked every WAKEINT seconds. Messages will be sent every ALARMINT minutes until TEMP is < HITEMP. |
| Bit 2: | When set to 1, a message will be sent when TEMP < LOTEMP. TEMP is checked every WAKEINT seconds. Messages will be sent every ALARMINT minutes until TEMP is > LOTEMP. |
| Bit 1: | When set to 1, a message will be sent when HUMID > HIHUMID. HUMID is checked every WAKEINT seconds. Messages will be sent every ALARMINT minutes until HUMID is < HIHUMID. |
| Bit 0 (LSB): | When set to 1, a message will be sent when HUMID < LOHUMID. HUMID is checked every WAKEINT seconds. Messages will be sent every ALARMINT minutes until HUMID is > LOHUMID. |
| []() | |
| Text: | Sent as ASCII-encoded Hex in the range 00 to ff |
| Example value: | To send binary messages, without forwarding, and alarm when TEMP is > HITEMP |
| Binary example: | 0x3188 (B10001000 is 0x88) |
| Text example: | 88 |
| Default value: | 0x00 |

---
FLAGS2 (0x32)
---

| []() | |
|---|---|
| Description: | Defines various message options. |
| Binary: | byte. |
| []() | |
| Bit 7 (MSB): | When set to 1, geofence alerts are enabled. |
| Bit 6: | When set to 1, geofence alerts will be sent every ALARMINT minutes when the tracker _is inside_ a geofenced area. When clear, geofence alerts will be sent when the tracker _is outside_ all geofenced areas (default). |
| Bit 5: | When set to 1, messages will be sent every ALARMINT minutes when the battery (bus) voltage falls below LOWBATT. |
| Bit 4: | When set to 1, the tracker will stay powered up and will monitor the Iridium ring channel continuously for new MT messages. |
| Bit 3: | Undefined. |
| Bit 2: | Undefined. |
| Bit 1: | Undefined. |
| Bit 0 (LSB): | Undefined. |
| []() | |
| Text: | Sent as ASCII-encoded Hex in the range 00 to ff |
| Example value: | To enable geofence alerts when the tracker leaves the geofenced area(s) |
| Binary example: | 0x3280 (B10000000 is 0x80) |
| Text example: | 80 |
| Default value: | 0x00 |

**Notes:**

The geofence alert is generated by the ZOE-M8Q. It will automatically wake the tracker so an alert message can be sent.
Battery consumption will increase when geofence alerts are enabled as the ZOE-M8Q will be powered continuously.
WAKEINT should be set to the same interval as ALARMINT if geofence alerts are enabled.

Power consumption will increase dramatically if the tracker is configured to monitor the Iridium ring channel. This is not recommended for battery-powered applications.
WAKEINT should be set to the same interval as ALARMINT and TXINT if the ring channel is being monitored.

---
DEST (0x33)
---

| []() | |
|---|---|
| Description: | The destination RockBLOCK serial number for message forwarding. |
| Binary: | uint32_t, 4 bytes, little endian. |
| Text: | Sent in the format nnnnn in the range 0 to 9999999 |
| Example value: | 12345 |
| Binary example: | 0x3339300000 (12345 is 0x00003039) |
| Text example: | 12345 |
| Default value: | 0 |

---
HIPRESS (0x34)
---

| []() | |
|---|---|
| Description: | The high atmospheric pressure alarm limit. |
| Binary: | uint16_t, 2 bytes, little endian, in mbar. |
| Text: | Sent in the format nnnn in the range 0 to 1084 (approx.) |
| Example value: | 998 |
| Binary example: | 0x34e603 (998 is 0x03e6) |
| Text example: | 998 |
| Default value: | 1084 |

---
LOPRESS (0x35)
---

| []() | |
|---|---|
| Description: | The low atmospheric pressure alarm limit. |
| Binary: | uint16_t, 2 bytes, little endian, in mbar. |
| Text: | Sent in the format nnnn in the range 0 to 1084 (approx.) |
| Example value: | 998 |
| Binary example: | 0x34e603 (998 is 0x03e6) |
| Text example: | 998 |
| Default value: | 0 |

---
HITEMP (0x36)
---

| []() | |
|---|---|
| Description: | The high atmospheric temperature alarm limit. |
| Binary: | int16_t (signed), 2 bytes, little endian, in Centigrade * 10^-2. |
| Text: | Sent in the format n.n with 1 or 2 decimal places, signed, in the range -40.0 to 85.0 (approx.) |
| Example value: | -12.34C |
| Binary example: | 0x362efb (-1234 is 0xfb2e) |
| Text example: | -12.34 |
| Default value: | 85 |

---
LOTEMP (0x37)
---

| []() | |
|---|---|
| Description: | The low atmospheric temperature alarm limit. |
| Binary: | int16_t (signed), 2 bytes, little endian, in Centigrade * 10^-2. |
| Text: | Sent in the format n.n with 1 or 2 decimal places, signed, in the range -40.0 to 85.0 (approx.) |
| Example value: | -12.34C |
| Binary example: | 0x372efb (-1234 is 0xfb2e) |
| Text example: | -12.34 |
| Default value: | -40 |

---
HIHUMID (0x38)
---

| []() | |
|---|---|
| Description: | The high atmospheric humidity alarm limit. |
| Binary: | uint16_t, 2 bytes, little endian, in %RH * 10^-2. |
| Text: | Sent in the format n.n with 1 or 2 decimal places in the range 0.0 to 100.0 (approx.) |
| Example value: | 12.34%RH |
| Binary example: | 0x38d204 (1234 is 0x04d2) |
| Text example: | 12.34 |
| Default value: | 100 |

---
LOHUMID (0x39)
---

| []() | |
|---|---|
| Description: | The low atmospheric humidity alarm limit. |
| Binary: | uint16_t, 2 bytes, little endian, in %RH * 10^-2. |
| Text: | Sent in the format n.n with 1 or 2 decimal places in the range 0.0 to 100.0 (approx.) |
| Example value: | 12.34%RH |
| Binary example: | 0x39d204 (1234 is 0x04d2) |
| Text example: | 12.34 |
| Default value: | 0 |

---
GEOFNUM (0x3a)
---

| []() | |
|---|---|
| Description: | The number of geofences in use (0-4) and the confidence level: 0 = no confidence, 1 = 68%, 2 = 95%, 3 = 99.7%, 4 = 99.99%. |
| Binary: | byte, the 4 most significant bits indicate the number of geofences in use, the 4 least significant bits indicate the confidence level. |
| Text: | Sent in the format n.c in the range 0.0 to 4.4 |
| Example value: | 1 geofence, 99.7% confidence (level 3) |
| Binary example: | 0x3a13 |
| Text example: | 1.3 |
| Default value: | 00 |

---
GEOF1LAT (0x3b)
---

| []() | |
|---|---|
| Description: | The latitude of the center of geofence circle 1. |
| Binary: | int32_t (signed), 4 bytes, little endian, in degrees * 10^-7. |
| Text: | Sent in the format -d.d with up to 7 decimal places in the range -90.0 to 90.0 _without preceding or trailing zeroes_ |
| Example value: | 40 degrees South |
| Binary example: | 0x3b007c28e8 (-400000000 is 0xe8287c00) |
| Text example: | -40.0 |
| Default value: | 0.0 |

---
GEOF1LON (0x3c)
---

| []() | |
|---|---|
| Description: | The longitude of the center of geofence circle 1. |
| Binary: | int32_t (signed), 4 bytes, little endian, in degrees * 10^-7. |
| Text: | Sent in the format -d.d with up to 7 decimal places in the range -180.0 to 179.9999999 _without preceding or trailing zeroes_ |
| Example value: | 170 degrees West |
| Binary example: | 0x3c000fac9a (-1700000000 is 0x9aac0f00) |
| Text example: | -170.0 |
| Default value: | 0.0 |

---
GEOF1RAD (0x3d)
---

| []() | |
|---|---|
| Description: | The longitude of the center of geofence circle 1. |
| Binary: | uint32_t, 4 bytes, little endian, in **cm**. |
| Text: | Sent as **m**, with cm resolution, in the format m.m with 1 or 2 decimal places _without preceding or trailing zeroes_ |
| Example value: | 100m |
| Binary example: | 0x3d10270000 (10000 is 0x00002710) |
| Text example: | 100.0 |
| Default value: | 0.0 |

---
GEOF2LAT (0x3e)
---

See GEOF1LAT

---
GEOF2LON (0x3f)
---

See GEOF1LON

---
GEOF2RAD (0x40)
---

See GEOF1RAD

---
GEOF3LAT (0x41)
---

See GEOF1LAT

---
GEOF3LON (0x42)
---

See GEOF1LON

---
GEOF3RAD (0x43)
---

See GEOF1RAD

---
GEOF4LAT (0x44)
---

See GEOF1LAT

---
GEOF4LON (0x45)
---

See GEOF1LON

---
GEOF4RAD (0x46)
---

See GEOF1RAD

---
WAKEINT (0x47)
---

| []() | |
|---|---|
| Description: | The tracker's wake-up interval (seconds). The tracker will wake up every WAKEINT seconds and check the PHT values. |
| Binary: | uint32_t, 4 bytes, little endian, in seconds. |
| Text: | Sent in the format nnnnn _without preceding zeroes_ |
| Example value: | 10 seconds |
| Binary example: | 0x470a000000 (10 is 0x0000000a) |
| Text example: | 10 |
| Default value: | 60 |

**Notes:**

The maximum value is 86400 seconds (= 24 hours)

---
ALARMINT (0x48)
---

| []() | |
|---|---|
| Description: | The tracker's alarm interval (minutes). The tracker will send a message every ALARMINT minutes while an alarm is present. |
| Binary: | uint16_t, 2 bytes, little endian, in minutes. |
| Text: | Sent in the format nnnn _without preceding zeroes_ |
| Example value: | 10 minutes |
| Binary example: | 0x480a00 (10 is 0x000a) |
| Text example: | 10 |
| Default value: | 5 |

**Notes:**

The maximum value is 1440 minutes (= 24 hours)

---
TXINT (0x49)
---

| []() | |
|---|---|
| Description: | The tracker's transmission interval (minutes). The tracker will send a routine message every TXINT minutes. |
| Binary: | uint16_t, 2 bytes, little endian, in minutes. |
| Text: | Sent in the format nnnn _without preceding zeroes_ |
| Example value: | 10 minutes |
| Binary example: | 0x490a00 (10 is 0x000a) |
| Text example: | 10 |
| Default value: | 5 |

**Notes:**

The maximum value is 1440 minutes (= 24 hours)

---
LOWBATT (0x4a)
---

| []() | |
|---|---|
| Description: | The low battery limit. |
| Binary: | uint16_t, 2 bytes, little endian, in Volts * 10^-2. |
| Text: | Sent in the format v.v with 1 or 2 decimal places in the range 0.0 to 9.99 |
| Example value: | 3.60V |
| Binary example: | 0x096801 (360 is 0x0168) |
| Text example: | 3.6 |
| Default value: | 3.2 |

---
DYNMODEL (0x4b)
---

| []() | |
|---|---|
| Description: | The GNSS dynamic platform model: |
| |	0 = PORTABLE : Applications with low acceleration, e.g. portable devices. Suitable for most situations. |
| |	2 = STATIONARY : Used in timing applications (antenna must be stationary) or other stationary applications. Velocity restricted to 0 m/s. Zero dynamics assumed. |
| | 3 = PEDESTRIAN : Applications with low acceleration and speed, e.g. how a pedestrian would move. Low acceleration assumed. |
| |	4 = AUTOMOTIVE : Used for applications with equivalent dynamics to those of a passenger car. Low vertical acceleration assumed. |
| |	5 = SEA : Recommended for applications at sea, with zero vertical velocity. Zero vertical velocity assumed. Sea level assumed. |
| |	6 = AIRBORNE1g : Airborne <1g acceleration. Used for applications with a higher dynamic range and greater vertical acceleration than a passenger car. No 2D position fixes supported. |
| |	7 = AIRBORNE2g : Airborne <2g acceleration. Recommended for typical airborne environments. No 2D position fixes supported. |
| |	8 = AIRBORNE4g: Airborne <4g acceleration. Only recommended for extremely dynamic environments. No 2D position fixes supported. |
| |	9 = WRIST : Not supported in protocol versions less than 18. Only recommended for wrist worn applications. Receiver will filter out arm motion. |
| |	10 = BIKE : Supported in protocol versions 19.2 |
| Binary: | byte. |
| Text: | Sent in the format n in the range 0 to 10 |
| Example value: | 3 |
| Binary example: | 0x4b03 (3 is 0x03) |
| Text example: | 3 |
| Default value: | 0 |

---
USERFUNC1 (0x58)
---

Upon receiving this field in an MT message, the tracker will execute user function 1 at the end of the SBD message cycle.

This could trigger a Qwiic-connected relay for example.

The field ID is followed by _zero_ data bytes.

---
USERFUNC2 (0x59)
---

See USERFUNC1

---
USERFUNC3 (0x5a)
---

See USERFUNC1

---
USERFUNC4 (0x5b)
---

See USERFUNC1

---
USERFUNC5 (0x5c)
---

Upon receiving this field in an MT message, the tracker will execute user function 5 at the end of the SBD message cycle.

The field ID is followed by _two_ data bytes (uint16_t, little endian). The uint16_t is passed as a parameter to the user function.

---
USERFUNC6 (0x5d)
---

See USERFUNC5

---
USERFUNC7 (0x5e)
---

Upon receiving this field in an MT message, the tracker will execute user function 7 at the end of the SBD message cycle.

The field ID is followed by _four_ data bytes (uint32_t, little endian). The uint32_t is passed as a parameter to the user function.

---
USERFUNC8 (0x5f)
---

See USERFUNC7

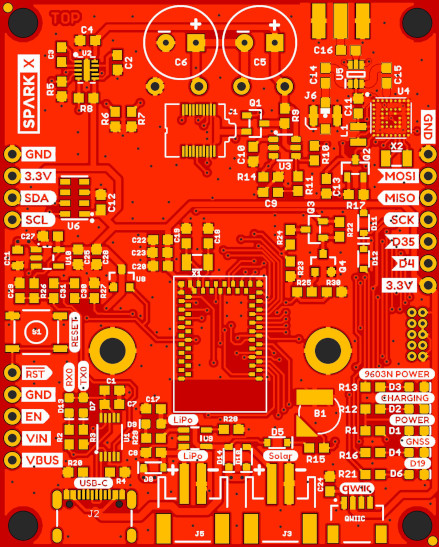
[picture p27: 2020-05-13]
img/Top.JPG

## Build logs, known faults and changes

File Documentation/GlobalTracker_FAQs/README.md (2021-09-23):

# Artemis Global Tracker: GlobalTracker FAQs

These FAQs assume you are running the [full Global Tracker (Example16)](../../Software/examples/Example16_GlobalTracker)

## Contents:
- [Do I need the extra 10F supercapacitors?](#Do-I-need-the-extra-10F-supercapacitors)
- [What voltage does the AGT need?](#What-voltage-does-the-AGT-need)
- [How much current does the AGT draw?](#How-much-current-does-the-AGT-draw)
- [Which antenna should I use?](#Which-antenna-should-I-use)
- [Can I use an active antenna?](#Can-I-use-an-active-antenna)
- [How do I configure the messages sent by the tracker?](#How-do-I-configure-the-messages-sent-by-the-tracker)
- [How do I send binary messages?](#How-do-I-send-binary-messages)
- [How do I enable RockBLOCK message forwarding?](#How-do-I-enable-RockBLOCK-message-forwarding)
- [How do I enable Pressure, Humidity and Temperature alarms?](#How-do-I-enable-Pressure-Humidity-and-Temperature-alarms)
- [How do I enable Geofence alarms?](#How-do-I-enable-Geofence-alarms)
- [How do I monitor the ring channel continuously for new MT messages?](#How-do-I-monitor-the-ring-channel-continuously-for-new-MT-messages)
- [How do I define and trigger a user function?](#How-do-I-define-and-trigger-a-user-function)
- [How do I send a user value?](#How-do-I-send-a-user-value)
- [How can I see the location of my trackers on a map?](#How-can-I-see-the-location-of-my-trackers-on-a-map)

## Do I need the extra 10F supercapacitors?

The AGT comes with 1F supercapacitors installed. You only need to add the additional 10F capacitors on the bottom of the board if you decide to
change the supercapacitor charge current from 150mA to 60mA.

Background:

The LTC3225 supercapacitor charger charge current is adjustable up to a maximum of 150mA. When set to the full 150mA, the LTC3225 can match the 145mA average current
drawn by the 9603N during transmit. This means that 1 Farad supercapacitors are adequate as they only need to hold enough charge to meet the
9603N's 1.3A peak current draw during the very brief (8.3ms) transmit bursts.

If you want to power the Global Tracker from a low current source, e.g. solar panels, the charge current can be reduced to 60mA by
changing the **Charge Current** jumper link. The 60mA charge current is enough to offset the 9603N's 39mA average current draw during receive,
but bigger supercapacitors are needed to deliver the average current draw during a complete receive/transmit cycle.
So, if you do change the charge current to 60mA, you will also need to solder additional 10 Farad supercapacitors on to
the rear of the PCB using the solder pads provided.

## What voltage does the AGT need?

Please refer to the [Power Options](../Hardware_Overview#power-options) in the Hardware Overview.

**Important Note:** We recommend that you power the AGT using the USB, Lipo battery and/or "Solar" power connectors.
If you choose to power the AGT via the VBUS breakout pin, there will be no reverse-polarity protection and _bad things could happen_
when connecting another power source.

Via the VBUS breakout pin:
- Maximum: 6.0V
- Recommended Minimum: 3.4V
  - The AP2112K 3.3V regulator has a dropout voltage of 100mV at 250mA at 25°C
- Actual Minimum: 3.2V (Approx.)
  - The LTC3225 supercapacitor charger requires a minimum of 2.8V and is powered by the AP2112K
  - The Artemis and ZOE GNSS have lower minimum voltages

Via the USB, Lipo battery or "Solar" (external power) connectors:
- Maximum: 6.0V
- Minimum: add approximately 350mV to the above figures
  - The PMEG4005 reverse-protection diode has a forward voltage of approx. 350mV at 300mA at 25°C

## How much current does the AGT draw?

In deep sleep, with the Power LED disconnected, the AGT draws a current of approximately 220µA.

The maximum current draw is dictated by the LTC3225 supercapacitor charge current:
- The LTC3225 has an efficiency of approximately 80% at 3.3V V<sub>IN</sub> at 100mA charge current
- Using the maximum charge current of 150mA, the LTC3225 will draw approximately 200mA
- The typical total current draw during supercapacitor charging is 250mA

## Which antenna should I use?

We recommend [this one](https://www.sparkfun.com/products/16838). It is optimized for Iridium and GNSS (GPS and GLONASS).

## Can I use an active antenna?

No. Two reasons:
- The [antenna switch circuit](../Hardware_Overview#antenna-switch) includes a DC-blocking capacitor
- The Iridium transmit would almost certainly damage an active preamplifier

## How do I configure the messages sent by the tracker?

The messages sent by the Global Tracker contain one or more **MOFIELDS** (Mobile Originated message FIELDS).

By default, Example16_GlobalTracker sends a _text_ message, every 5 minutes, containing the following MOFIELDS:
- **DATETIME** : the GNSS date and time in _YYYYMMDDHHMMSS_ format
- **LAT** : the GNSS latitude in degrees
- **LON** : the GNSS longitude in degrees
- **ALT** : the GNSS altitude above mean sea level in meters

For a full definition of the message fields, please see the [message format documentation](../Message_Format).

Let's say you also want to include the **SPEED** (ground speed) and **HEAD** (heading) MOFIELDS:

You will find the Configuration Tool in the [Tools folder](../../Tools/Artemis_Global_Tracker_Configuration_Tool).
If you are familiar with Python and are able to install PyQt5 and all the other required modules, you can run _AGTCT.py_.
If you are less familiar with Python, you will find a 64-bit Windows executable (.exe) version in [this folder](../../Tools/Artemis_Global_Tracker_Configuration_Tool/Windows_64-bit).

When you run the configuration tool, the [PyQt5 user interface](#AGTCT1) will appear.
If you are using the 64-bit Windows executable (.exe) version: don't panic! It takes a few seconds for the user interface to appear.

It just so happens that **DATETIME** + **LAT** + **LON** + **ALT** + **SPEED** + **HEAD** are the MOFIELDS expected by the [Mapper](../../Tools/Artemis_Global_Tracker_Mapping_Tools)
and there is a pickle (.pkl) file containing those settings that you can load:
- Click on the _Browse_ button
- Click on _mapper.pkl_ and then click _Open_
- Click on the _Load Config_ button

The user interface should now look like [this](#AGTCT2). You will notice that:
- The **DATETIME**, **LAT**, **LON**, **ALT**, **SPEED** and **HEAD** MOFIELDS checkboxes are ticked. This tells the tracker to send (only) these MOFIELDS.
- The **MOFIELDS** _Include_ checkbox is ticked. This must be ticked otherwise the MOFIELDS will not be included in the configuration message. You will get a warning message if you forget.
- None of the _FLAGS1_ checkboxes are ticked. This ensures the message is sent in _text_ format, not _binary_.
- The **FLAGS1** _Include_ checkbox is ticked. This must be ticked otherwise FLAGS1 will not be included in the configuration message.
- The **TXINT** _Include_ checkbox is ticked and the value box contains _15_. This will change the message transmit interval to 15 minutes. The default is 5 minutes.

Now click on the _Calculate Config_ button and you should see the [configuration message](#AGTCT3)
_02310030c00f00000000000000000000490f00038d30_ in the _Configuration Message_ window.

You now have a choice to make. You can either update the tracker settings [via a USB cable](#Updating-the-configuration-via-USB),
or remotely [via an Iridium message](#Updating-the-configuration-via-Iridium).

If you want to restore the default settings, you can repeat the tracker configuration using the _default.pkl_ pickle file.

Loading the _empty.pkl_ is a quick way to clear all of the checkboxes and values.

### Updating the configuration via USB
- Connect the tracker to your computer using a standard USB-C cable. If you are using Windows, you should hear the usual bing-bong connection sound.
- Click on the _Refresh_ button and select the tracker's COM port from the drop-down box.
- Click on _Open Port_ and you should see a [welcome message from the tracker](#AGTCT4) in the _Serial Monitor_ window.
- Click on _Upload Config_ and you should see [these messages in the _Serial Monitor_](#AGTCT5):

```
*** Tracker Configuration ***
Waiting for data...
Data received! Checking if it is valid...
Data is valid! Parsing it...
Parsing complete. Updating values in EEPROM.
Done!
```

You can now disconnect the tracker and close the configuration tool. The tracker will use the new settings from now on.

### Updating the configuration via Iridium
- Right-click in the _Configuration Message_ window and click on _Select All_.
- Right-click in the _Configuration Message_ window again and click on _Copy_.
- Log in to [Rock7 Operations](https://rockblock.rock7.com/Operations).
- Click on the _Send a Message_ tab.
- Tick the RockBLOCK serial number of the tracker you want to update.
- Select _Hex_ from the Mode drop-down.
- Right-click in the _Hex String_ window and click _Paste_.
- Click _Send Message_ to send the configuration message.

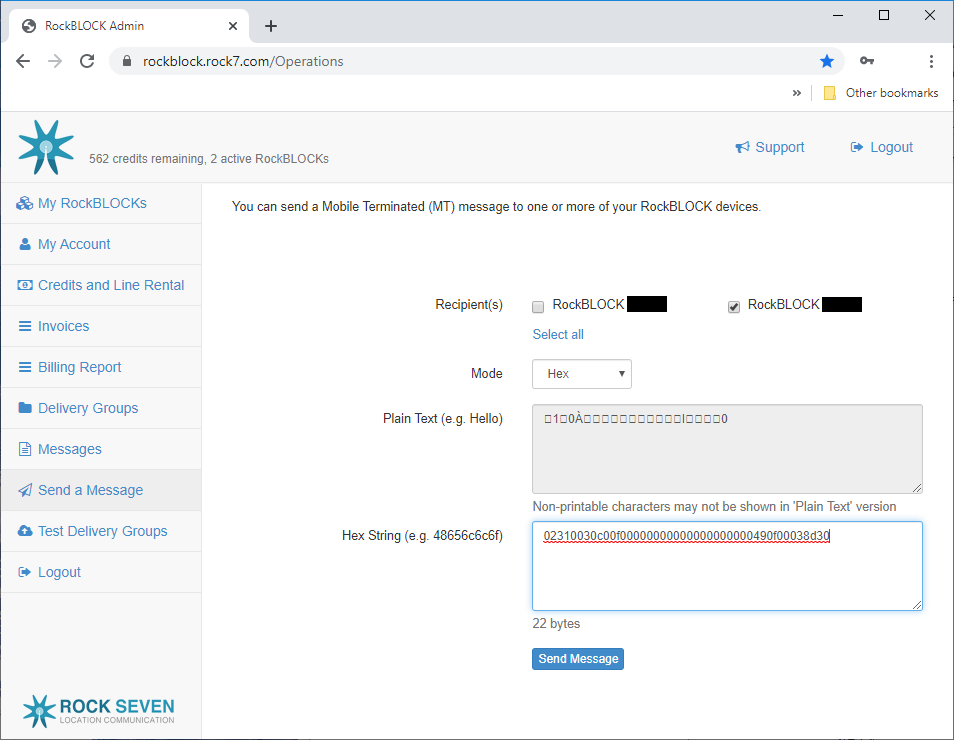
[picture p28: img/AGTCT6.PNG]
AGTCT6


The tracker settings will be updated the next time the tracker transmits.

## How do I send binary messages?

Sending messages in _binary_ format is a good way to save message credits. The message length will be approximately half compared to text, and you are charged one message
credit for every 50 bytes sent (or part thereof). The only downside is that binary messages are not human-readable.

- Open the configuration tool as shown above.
- Make sure all of the checkboxes and values are clear. Loading _empty.pkl_ is a quick way to do this.
- Tick the **FLAGS1** _Send message in binary format_ checkbox.
- Tick the **FLAGS1** _Include_ checkbox.
- Click on _Calculate Config_.

The configuration tool should look like [this](#AGTCT7). Now update the tracker settings
as shown above.

If you want to change the MOFIELDS, you can do that in the [same message](#AGTCT8).

## How do I enable RockBLOCK message forwarding?

The Rock7 RockBLOCK gateway has a powerful feature that allows you to automatically forward messages from one RockBLOCK device to another.
See [this link](https://docs.rockblock.rock7.com/docs/messaging-between-rockblocks) for further details.

E.g.
- if the RockBLOCK serial number of your tracker is 54321
- and you want to forward messages to RockBLOCK 12345

Do the following:
- Open the configuration tool as shown above.
- Make sure all of the checkboxes and values are clear. Loading _empty.pkl_ is a quick way to do this.
- Tick the **FLAGS1** _Forward messages to DEST_ checkbox.
- Tick the **FLAGS1** _Include_ checkbox.
- Tick the **DEST** _Include_ checkbox.
- Enter _12345_ in the DEST value box.
- Tick the **SOURCE** _Include_ checkbox.
- Enter _54321_ in the SOURCE value box.
- Tick the MOFIELDS checkboxes for the message fields you want to send, including the **SOURCE** MOFIELD so the destination RockBLOCK knows which tracker sent the message
- Tick the **MOFIELDS** _Include_ checkbox.
- Click on _Calculate Config_.

The configuration tool should look like [this](#AGTCT9). Now update the tracker settings
as shown above.

Notes:
- Including the **SOURCE** MOFIELD is optional, but is useful as it lets the destination RockBLOCK know which tracker sent the message.
- The tracker's SOURCE serial number can only be changed via USB, to avoid it being changed accidentally. Remember to set this before you deploy your tracker.
- You will be charged twice for each message: once when the source sends it and again when the destination receives it.

## How do I enable Pressure, Humidity and Temperature alarms?

The tracker can be configured to wake up every **WAKEINT** _seconds_. When it wakes, it will check the pressure, humidity and temperature readings from the on-board MS8607 PHT sensor.
If pressure, temperature or humidity alarms are enabled, a message will be sent every **ALARMINT** _minutes_ if any of the limits are exceeded.

E.g.
- If you want to use the tracker to monitor the temperature and humidity in your greenhouse once per minute;
- you want to send alarm messages every 15 minutes if the temperature goes above 40C;
- or if the humidity falls below 30% RH.
- If things are normal, you want to send a message once per day.

You would do the following:
- Open the configuration tool as shown above.
- Make sure all of the checkboxes and values are clear. Loading _empty.pkl_ is a quick way to do this.
- Tick the **FLAGS1** _Enable HITEMP alarm messages_ and _Enable LOHUMID_ checkboxes.
- Tick the **FLAGS1** _Include_ checkbox.
- Tick the MOFIELDS checkboxes for the message fields you want to send, e.g. **PRESS**, **TEMP**, **HUMID** and **DATETIME**
- Tick the **MOFIELDS** _Include_ checkbox.
- Tick the **WAKEINT** _Include_ checkbox.
- Enter _60_ in the WAKEINT value box. This sets the wake interval to 60 seconds.
- Tick the **ALARMINT** _Include_ checkbox.
- Enter _15_ in the ALARMINT value box. This sets the alarm transmit interval to 15 minutes.
- Tick the **TXINT** _Include_ checkbox.
- Enter _1440_ in the TXINT value box. This sets the normal transmit interval to 1440 minutes (every 24 hours).
- Tick the **HITEMP** _Include_ checkbox.
- Enter _40.0_ in the HITEMP value box. This sets the high temperature alarm limit to 40.0C.
- Tick the **LOHUMID** _Include_ checkbox.
- Enter _30.0_ in the LOHUMID value box. This sets the low humidity alarm limit to 30.0% RH.
- Click on _Calculate Config_.

The configuration tool should look like [this](#AGTCT10). Now update the tracker settings
as shown above.

## How do I enable Geofence alarms?

The tracker can be configured to leave the ZOE-M8Q GNSS powered on continuously so it can generate geofence alarms.

**Note: enabling geofence alerts will substantially increase the current draw and shorten the battery life as the ZOE will be powered continuously.**

E.g.
- If you want to set a geofence around latitude 55.0 degrees north, longitude 1 degree west, with a radius of 100m.
- You want to use a position confidence level of 95%.
- You want alarm messages to be generated when the tracker leaves the geofenced area.
- You want to send alarm messages every 5 minutes.
- If things are normal, you want to send a message once per day.

You would do the following:
- Open the configuration tool as shown above.
- Make sure all of the checkboxes and values are clear. Loading _empty.pkl_ is a quick way to do this.
- Tick the **FLAGS2** _Enable GeoFence alarm messages_ checkbox.
- Tick the **FLAGS2** _Include_ checkbox.
- Tick the MOFIELDS checkboxes for the message fields you want to send, e.g. **LAT**, **LON**, **SPEED** and **HEAD**
- Tick the **MOFIELDS** _Include_ checkbox.
- Tick the **WAKEINT** _Include_ checkbox.
- Enter _300_ in the WAKEINT value box. This sets the wake interval to 300 seconds (5 minutes).
- Tick the **ALARMINT** _Include_ checkbox.
- Enter _5_ in the ALARMINT value box. This sets the alarm transmit interval to 5 minutes.
- Tick the **TXINT** _Include_ checkbox.
- Enter _1440_ in the TXINT value box. This sets the normal transmit interval to 1440 minutes (every 24 hours).
- Tick the **GEOFNUM** _Include_ checkbox.
- Enter _12_ in the GEOFNUM value box. This sets the number of geofences to 1 and the confidence level to 2 (95%). See the [GEOFNUM definition](../Message_Format#geofnum-0x3a) for more details.
- Tick the **GEOF1LAT** _Include_ checkbox.
- Enter _55.0_ in the GEOF1LAT value box. This sets the geofence latitude to 55 degrees north.
- Tick the **GEOF1LON** _Include_ checkbox.
- Enter _-1.0_ in the GEOF1LON value box. This sets the geofence longitude to 1 degree west (western longitudes are negative).
- Tick the **GEOF1RAD** _Include_ checkbox.
- Enter _100.0_ in the GEOF1RAD value box. This sets the geofence radius to 100m.
- Click on _Calculate Config_.

The configuration tool should look like [this](#AGTCT11). Now update the tracker settings
as shown above.

Notes:
- Enabling geofence alerts will substantially increase the current draw and shorten battery life as the ZOE will be powered continuously.
- WAKEINT and ALARMINT need to be set to the same value.
- If you want the alarm messages to be generated when entering a geofenced area, tick the **FLAGS2** _Alarm when inside the GeoFence_ checkbox.

## How do I monitor the ring channel continuously for new MT messages?

The tracker can be configured to leave the Iridium 9603N powered on continuously so it can monitor the ring channel and respond to new Mobile Terminated messages immediately.

**Note: monitoring the ring channel will substantially increase the current draw as the Iridium 9603N will be powered continuously.**
**This is not recommended for battery-powered applications.**

E.g.
- You want to monitor the ring channel continuously so you can respond quickly to new MT messages.
- If things are normal, you want to send a message once per day.

You would do the following:
- Open the configuration tool as shown above.
- Make sure all of the checkboxes and values are clear. Loading _empty.pkl_ is a quick way to do this.
- Tick the **FLAGS2** _Monitor Ring Channel continuously_ checkbox.
- Tick the **FLAGS2** _Include_ checkbox.
- Tick the **WAKEINT** _Include_ checkbox.
- Enter _86400_ in the WAKEINT value box. This sets the wake interval to 86400 seconds (24 hours).
- Tick the **ALARMINT** _Include_ checkbox.
- Enter _1440_ in the ALARMINT value box. This sets the alarm transmit interval to 1440 minutes (every 24 hours).
- Tick the **TXINT** _Include_ checkbox.
- Enter _1440_ in the TXINT value box. This sets the normal transmit interval to 1440 minutes (every 24 hours).
- Click on _Calculate Config_.

The configuration tool should look like [this](#AGTCT12). Now update the tracker settings
as shown above.

Notes:
- Monitoring the ring channel will substantially increase the current draw as the Iridium 9603N will be powered continuously. This is not recommended for battery-powered applications.
- WAKEINT should be set to the same value as ALARMINT and TXINT.
- Iridium ring alerts are only sent if the network knows your approximate location. You need to send at least one message per day in order to receive ring alerts.

## How do I define and trigger a user function?

The tracker supports eight different user functions. Each function is triggered when the corresponding field ID is received via a Mobile Terminated message.

The user functions are defined in [Tracker_User_Functions.ino](../../Software/examples/Example16_GlobalTracker/Tracker_User_Functions.ino).

E.g.
- You have a [Qwiic Relay](https://www.sparkfun.com/products/15093) connected to the tracker via the Qwiic connector.
- You want the relay to switch on when USERFUNC1 (field ID 0x58) is received.
- You want the relay to switch off again when USERFUNC2 (field ID 0x59) is received.

You will need to install the _SparkFun Qwiic Relay Arduino Library_ first, through the Arduino Library Manager. Search for _Qwiic Relay_.

Example code for the Qwiic (Single) Relay is available [here](https://github.com/sparkfun/SparkFun_Qwiic_Relay_Arduino_Library/blob/master/Examples/Example1_Single_Relay_Basics/Example1_Single_Relay_Basics.ino).

We need to add these lines to the start of Tracker_User_Functions.ino:

```
#include "SparkFun_Qwiic_Relay.h"
#define RELAY_ADDR 0x18 // Alternate address 0x19
Qwiic_Relay relay(RELAY_ADDR);
TwoWire myWire(4); //Will use Artemis pads 39/40
```

Then we need to add these lines to USER_FUNC_1:

```
  myWire.begin(); // Begin I2C communication to the relay
  if(relay.begin(myWire)) // Try to begin the relay
  {
    relay.turnRelayOn(); // If relay.begin was successful, turn the relay on
  }
  myWire.end(); // End I2C communication
```

And we need to add these lines to USER_FUNC_2:

```
  myWire.begin(); // Begin I2C communication to the relay
  if(relay.begin(myWire)) // Try to begin the relay
  {
    relay.turnRelayOff(); // If relay.begin was successful, turn the relay off
  }
  myWire.end(); // End I2C communication
```

The start of Tracker_User_Functions.ino should now look like this:

```
// Artemis Global Tracker: User Functions

// Add your own code to these functions to return USERVAL's or execute USERFUNC's

#include "SparkFun_Qwiic_Relay.h"
#define RELAY_ADDR 0x18 // Alternate address 0x19
Qwiic_Relay relay(RELAY_ADDR);
TwoWire myWire(4); //Will use Artemis pads 39/40

void USER_FUNC_1()
{
  debugPrintln("Executing USERFUNC1...");
  // Add your own code here - it will be executed when the Tracker receives a "USERFUNC1" (0x58) message field

  myWire.begin(); // Begin I2C communication to the relay
  if(relay.begin(myWire)) // Try to begin the relay
  {
    relay.turnRelayOn(); // If relay.begin was successful, turn the relay on
  }
  myWire.end(); // End I2C communication
}

void USER_FUNC_2()
{
  debugPrintln("Executing USERFUNC2...");
  // Add your own code here - it will be executed when the Tracker receives a "USERFUNC2" (0x59) message field

  myWire.begin(); // Begin I2C communication to the relay
  if(relay.begin(myWire)) // Try to begin the relay
  {
    relay.turnRelayOff(); // If relay.begin was successful, turn the relay off
  }
  myWire.end(); // End I2C communication
}
```

To trigger each user function, you need to send a configuration message to the tracker containing the appropriate field ID. E.g. to trigger USERFUNC1 you would do the following:
- Open the configuration tool as shown above.
- Make sure all of the checkboxes and values are clear. Loading _empty.pkl_ is a quick way to do this.
- Tick the **USERFUNCs** _Execute USERFUNC1_ checkbox.
- Click on _Calculate Config_.

The configuration tool should look like [this](#AGTCT13).
Now send the configuration message _0258035db9_ to the tracker through Rock7 Operations as shown above.

The configuration message for USERFUNC2 is _0259035ebb_

Notes:
- The Qwiic Relay will draw extra current while it is energised. This will shorten your battery life.
- USERFUNCs 5 and 6 allow a 16-bit uint16_t to be passed to the user function.
- USERFUNCs 7 and 8 allow a 32-bit uint32_t to be passed to the user function.

## How do I send a user value?

[Tracker_User_Functions.ino](../../Software/examples/Example16_GlobalTracker/Tracker_User_Functions.ino#L53-L114) also contains
eight functions which can be used to include user-defined data in the tracker messages.
- USER_VAL_1 and USER_VAL_2 allow _byte_ values to be included.
- USER_VAL_3 and USER_VAL_4 allow _uint16_t_ values to be included.
- USER_VAL_5 and USER_VAL_6 allow _uint32_t_ values to be included.
- USER_VAL_7 and USER_VAL_8 allow _float_ values to be included.

Let's say you have connected a sensor to the tracker which returns a _float_ reading. You would include the code to read your sensor inside USER_VAL7() or USER_VAL_8(); you would load
your sensor reading into _retVal_.

To include USERVAL7 in the messages from the tracker, you would:
- Open the configuration tool as shown above.
- Make sure all of the checkboxes and values are clear. Loading _empty.pkl_ is a quick way to do this.
- Tick the MOFIELDS checkboxes for any standard message fields you want to send, e.g. **DATETIME**.
- Tick the **USERVAL7** MOFIELDS checkbox.
- Tick the **MOFIELDS** _Include_ checkbox.
- Click on _Calculate Config_.

The configuration tool should look like [this](#AGTCT14). Now update the tracker settings
as shown above.

## How can I see the location of my trackers on a map?

The [Tools Folder](../../Tools#artemis_global_tracker_mapping_tools) contains a set of mapping tools which will display
the location and routes of up to eight trackers on a Google Maps Static image in a PyQt5 user interface. The tools have all been tried and tested on both Linux and Windows.
The tools are straight forward to use, but you do need to be familiar with Python3.

## AGTCT Screenshots

### AGTCT1
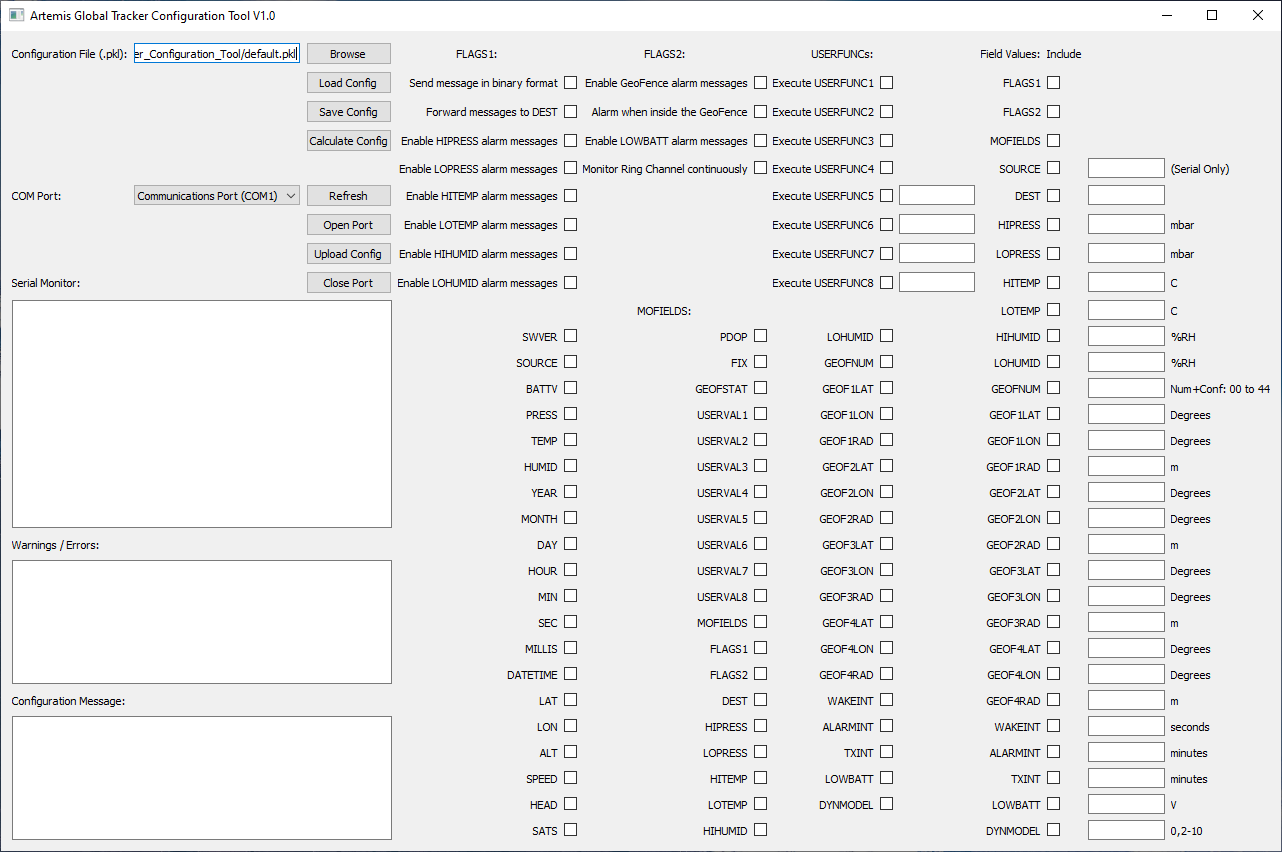
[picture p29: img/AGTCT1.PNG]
AGTCT1


[BACK](#How-do-I-configure-the-messages-sent-by-the-tracker)

### AGTCT2
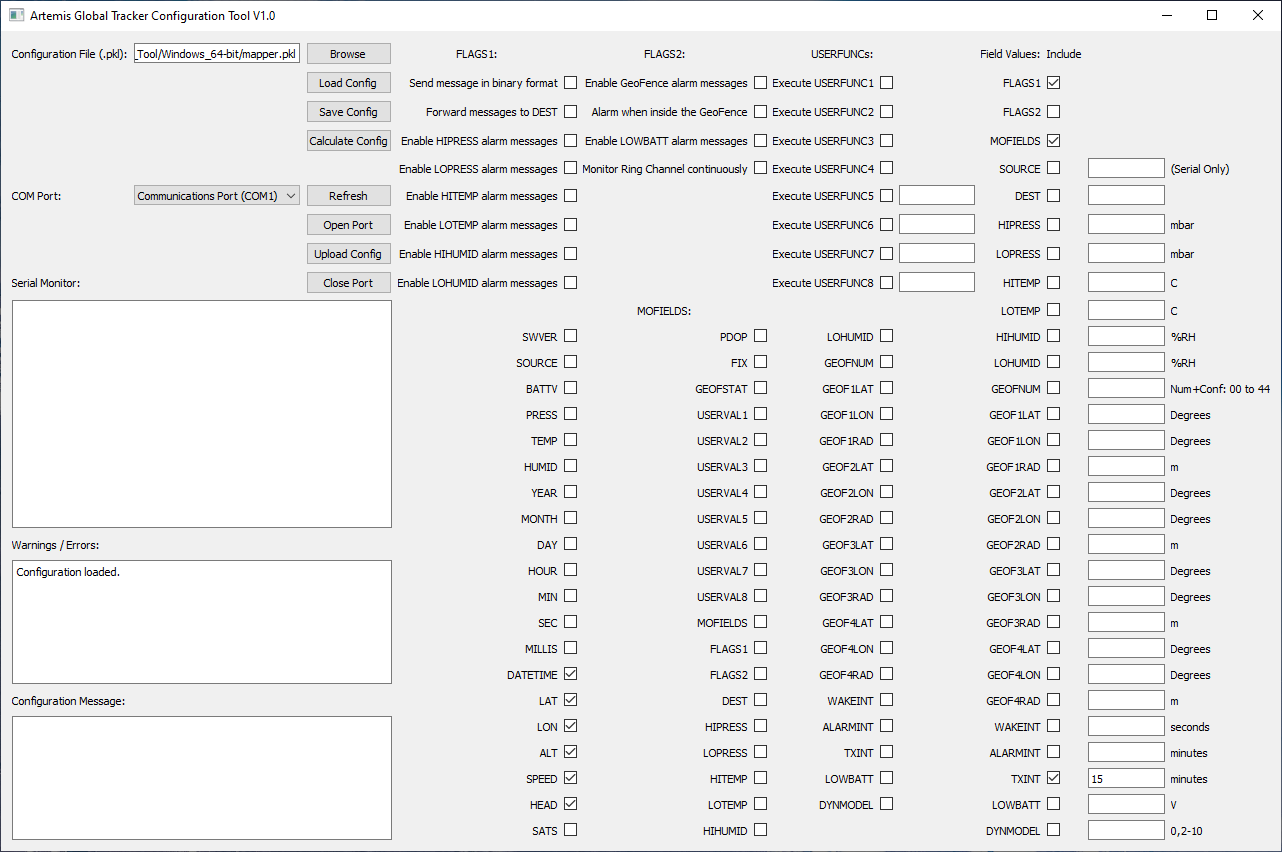
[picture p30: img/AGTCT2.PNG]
AGTCT2


[BACK](#How-do-I-configure-the-messages-sent-by-the-tracker)

### AGTCT3
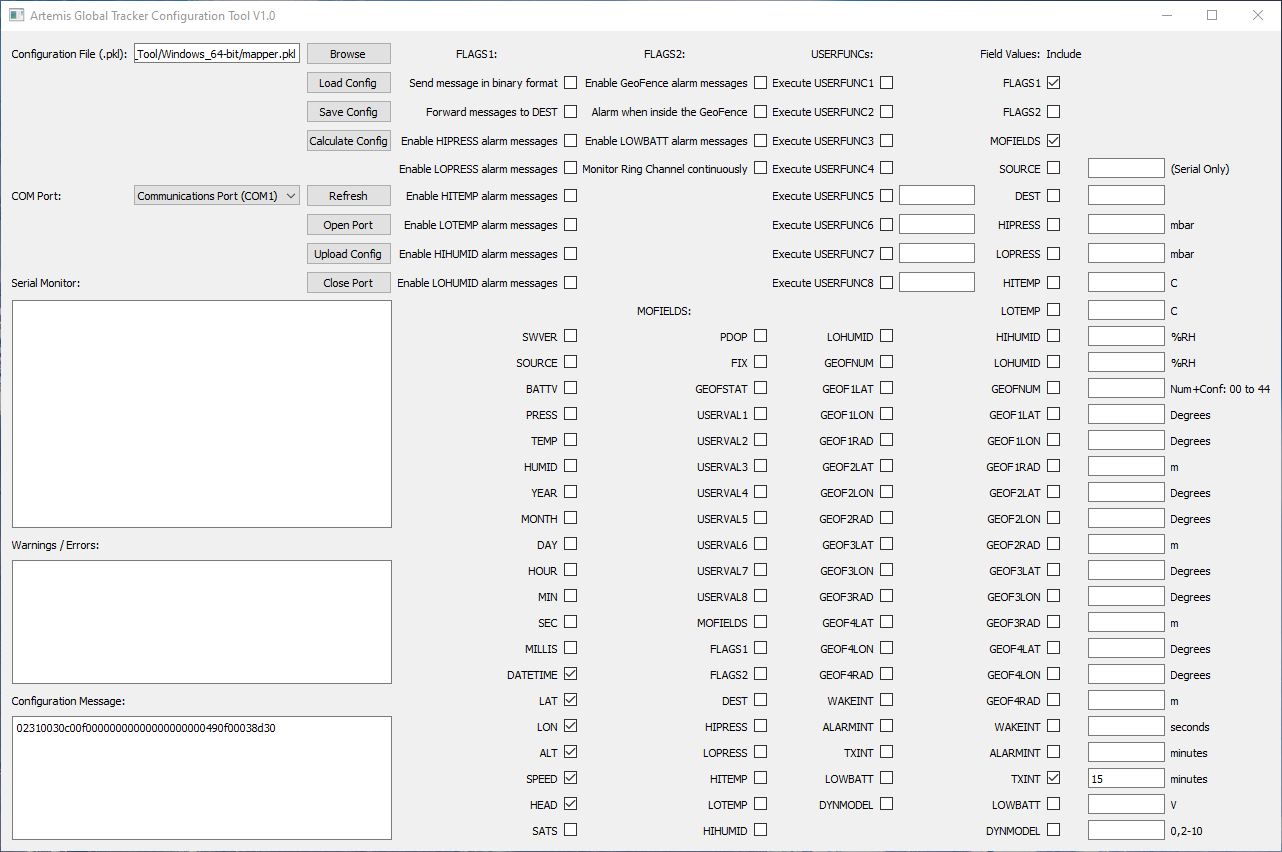
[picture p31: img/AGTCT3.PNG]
AGTCT3


[BACK](#How-do-I-configure-the-messages-sent-by-the-tracker)

### AGTCT4
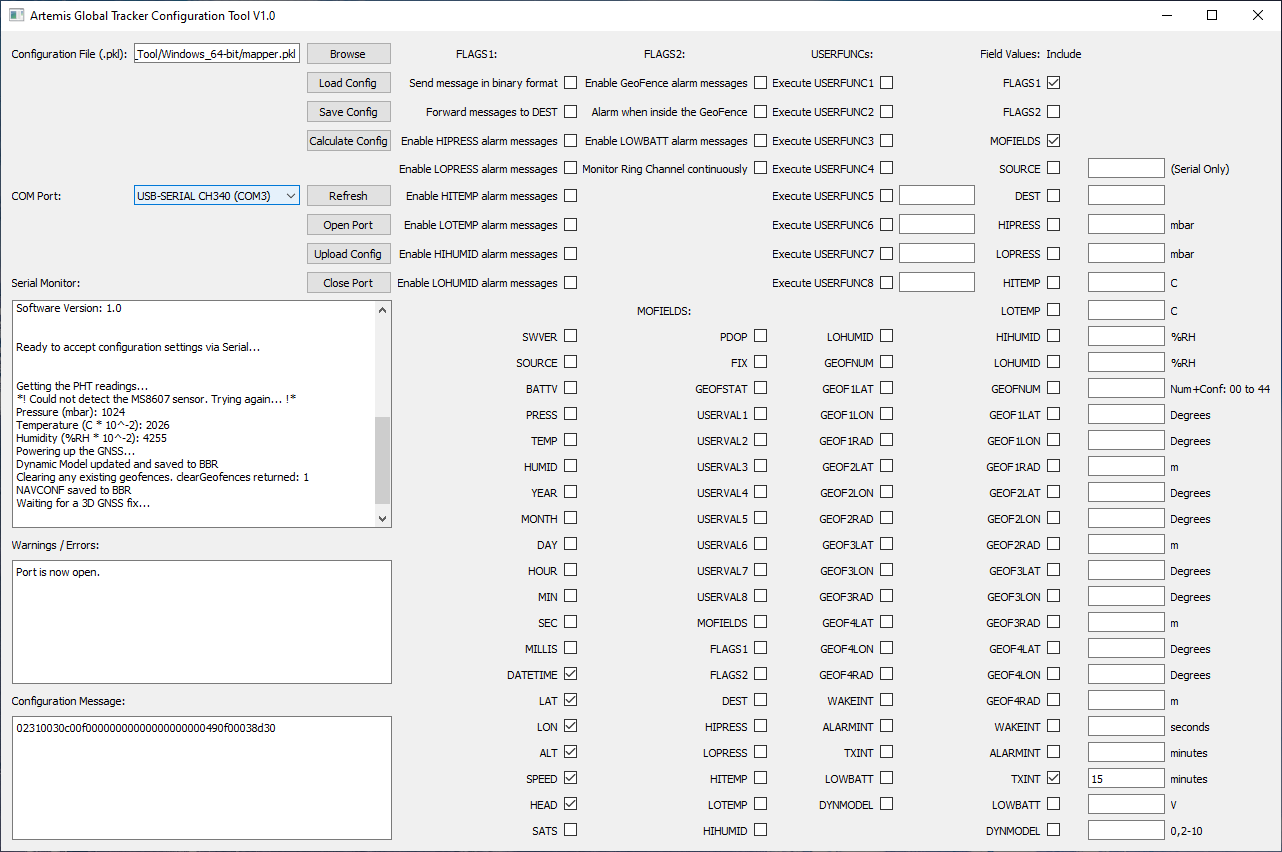
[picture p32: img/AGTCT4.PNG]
AGTCT4


[BACK](#Updating-the-configuration-via-USB)

### AGTCT5
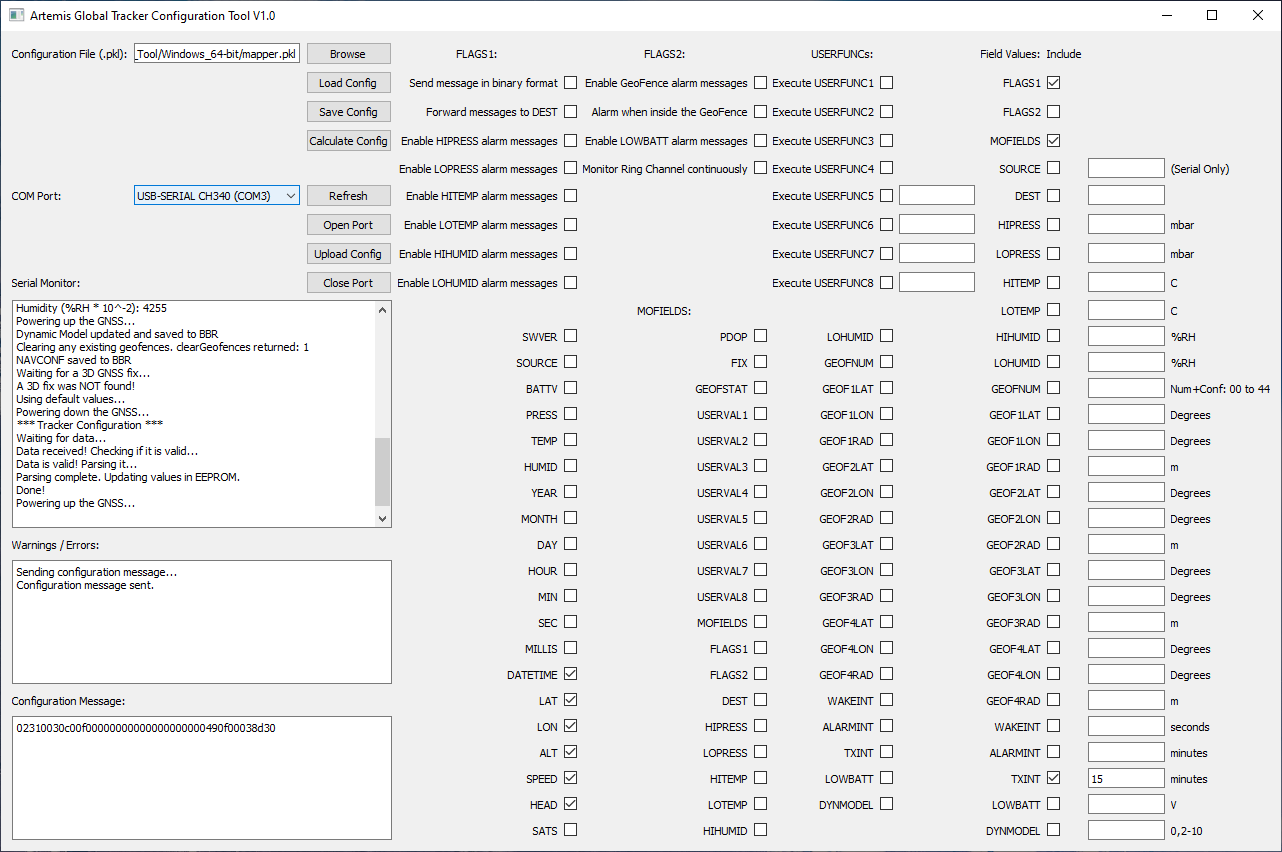
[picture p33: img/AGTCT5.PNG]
AGTCT5


[BACK](#Updating-the-configuration-via-USB)

### AGTCT6
AGTCT6

[BACK](#Updating-the-configuration-via-Iridium)

### AGTCT7
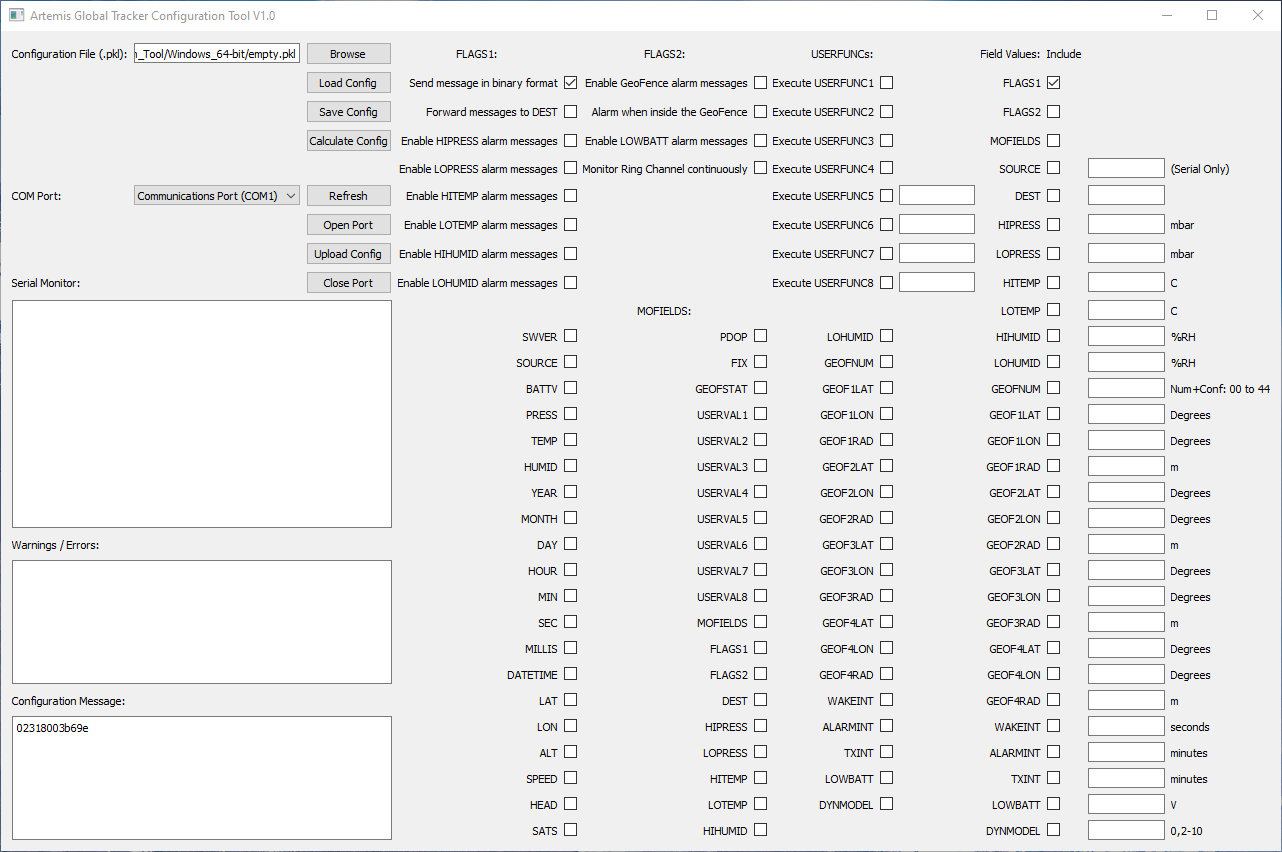
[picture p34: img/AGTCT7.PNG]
AGTCT7


[BACK](#How-do-I-send-binary-messages)

### AGTCT8
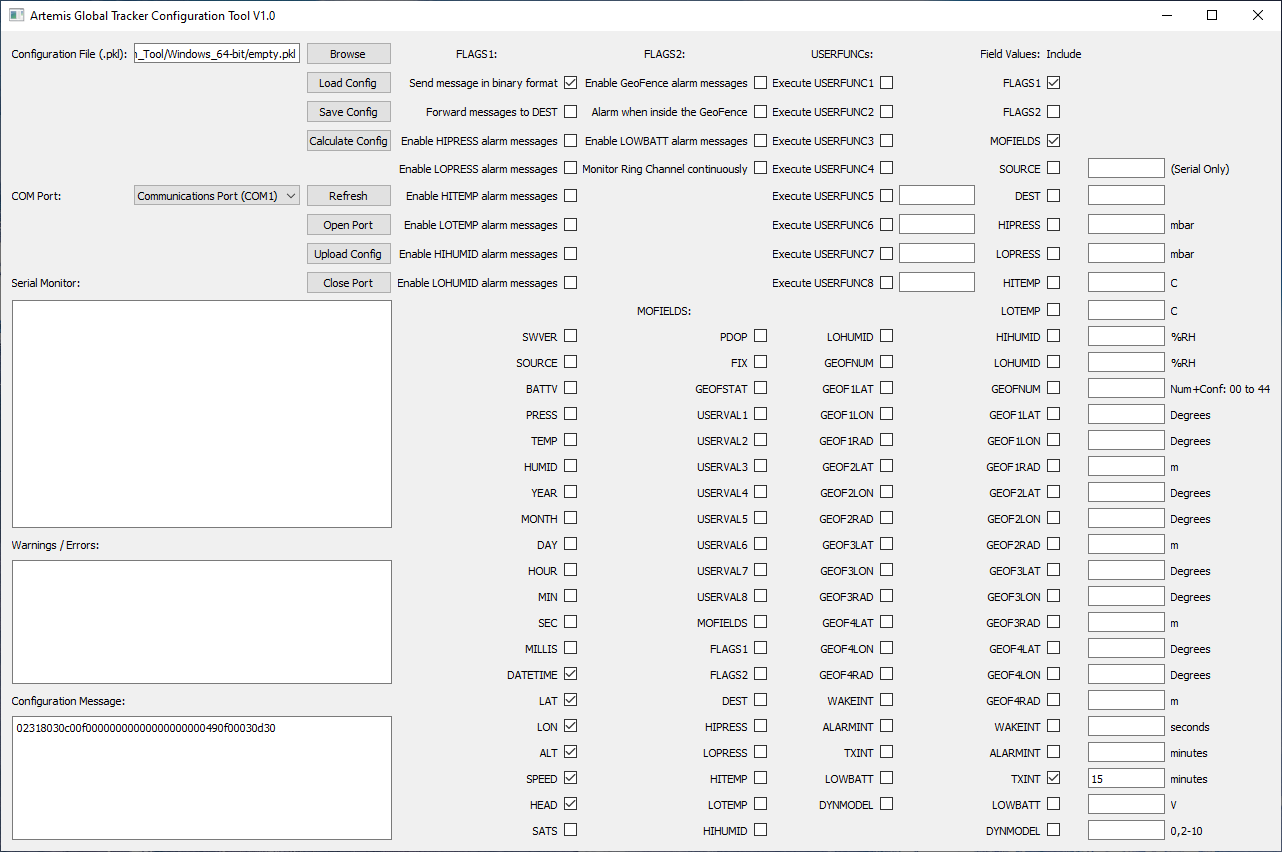
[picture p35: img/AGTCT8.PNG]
AGTCT8


[BACK](#How-do-I-send-binary-messages)

### AGTCT9
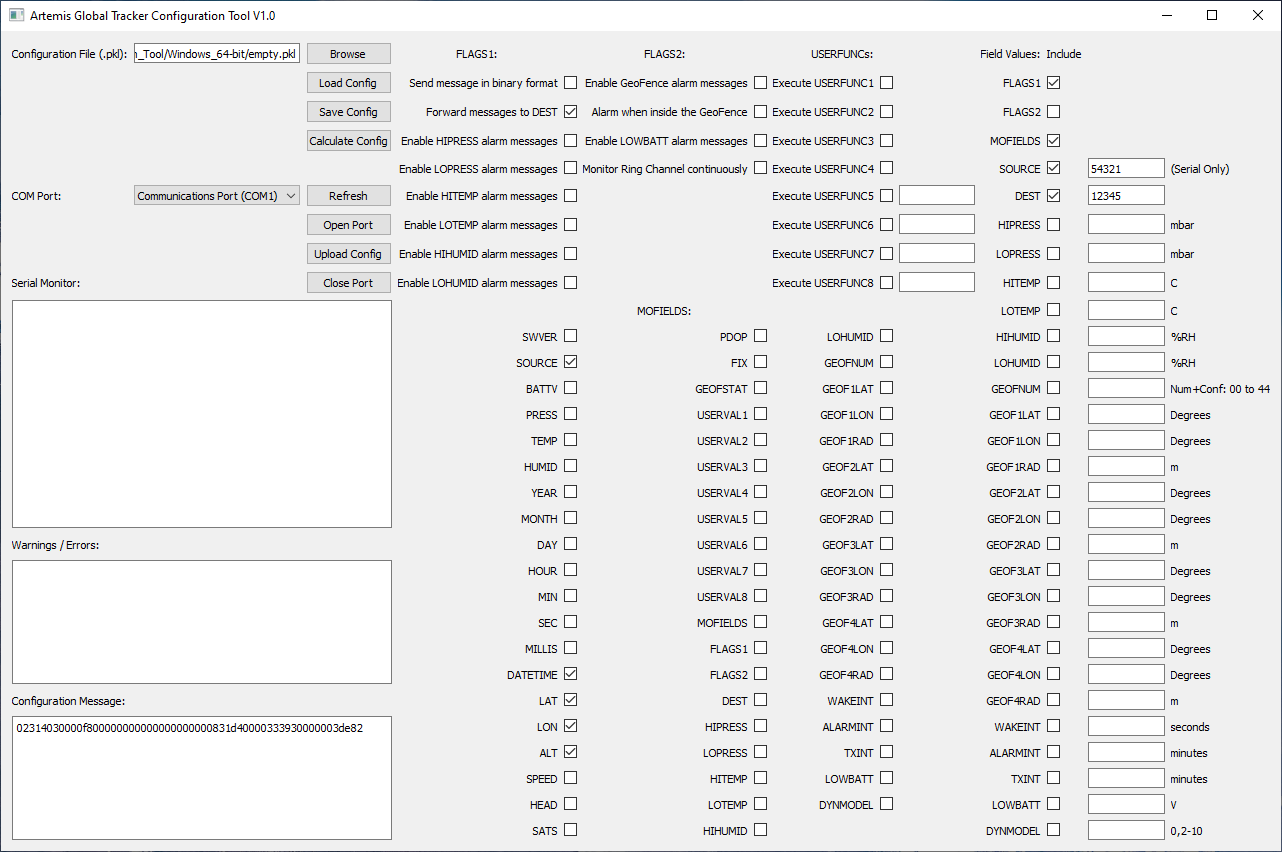
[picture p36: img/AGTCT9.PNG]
AGTCT9


[BACK](#How-do-I-enable-RockBLOCK-message-forwarding)

### AGTCT10
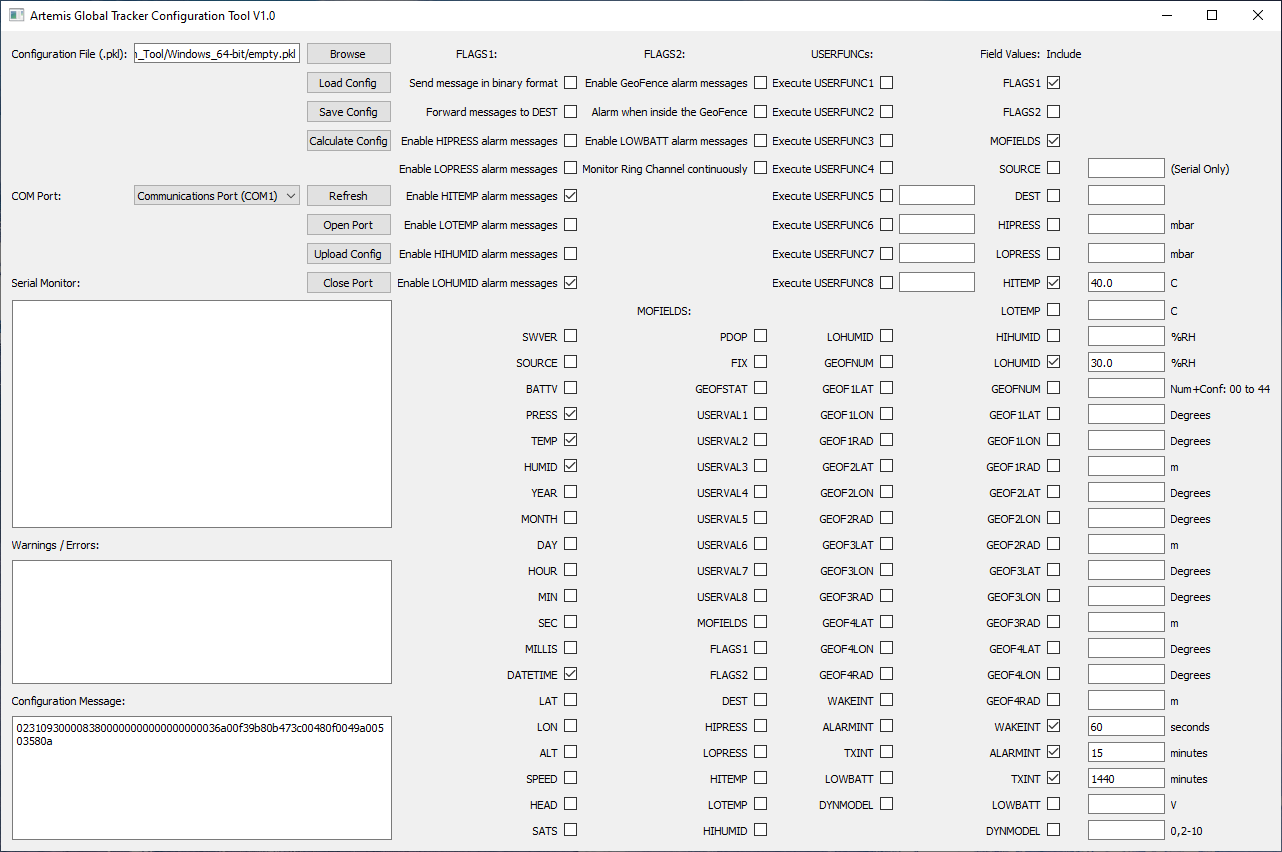
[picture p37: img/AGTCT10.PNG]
AGTCT10


[BACK](#How-do-I-enable-Pressure-Humidity-and-Temperature-alarms)

### AGTCT11
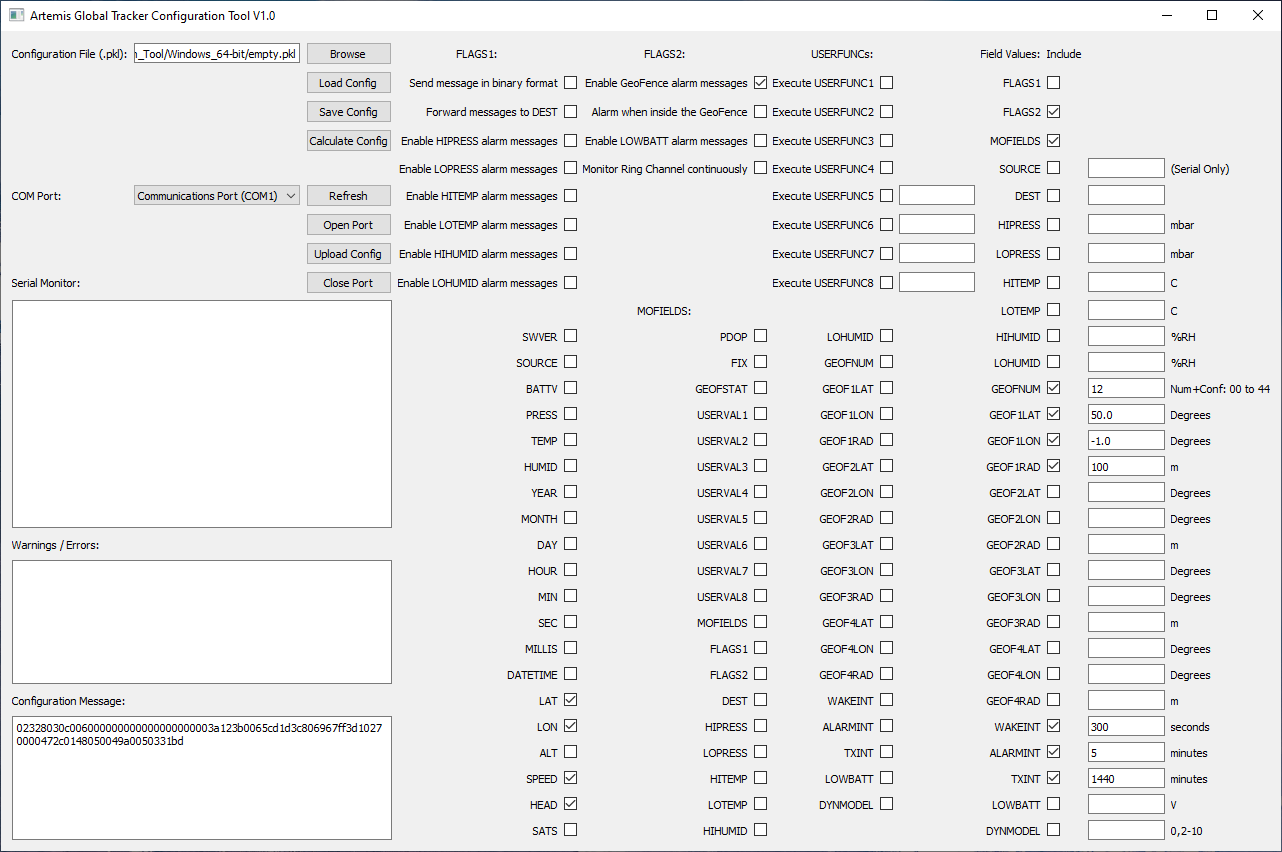
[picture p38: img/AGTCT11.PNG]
AGTCT11


[BACK](#How-do-I-enable-Geofence-alarms)

### AGTCT12
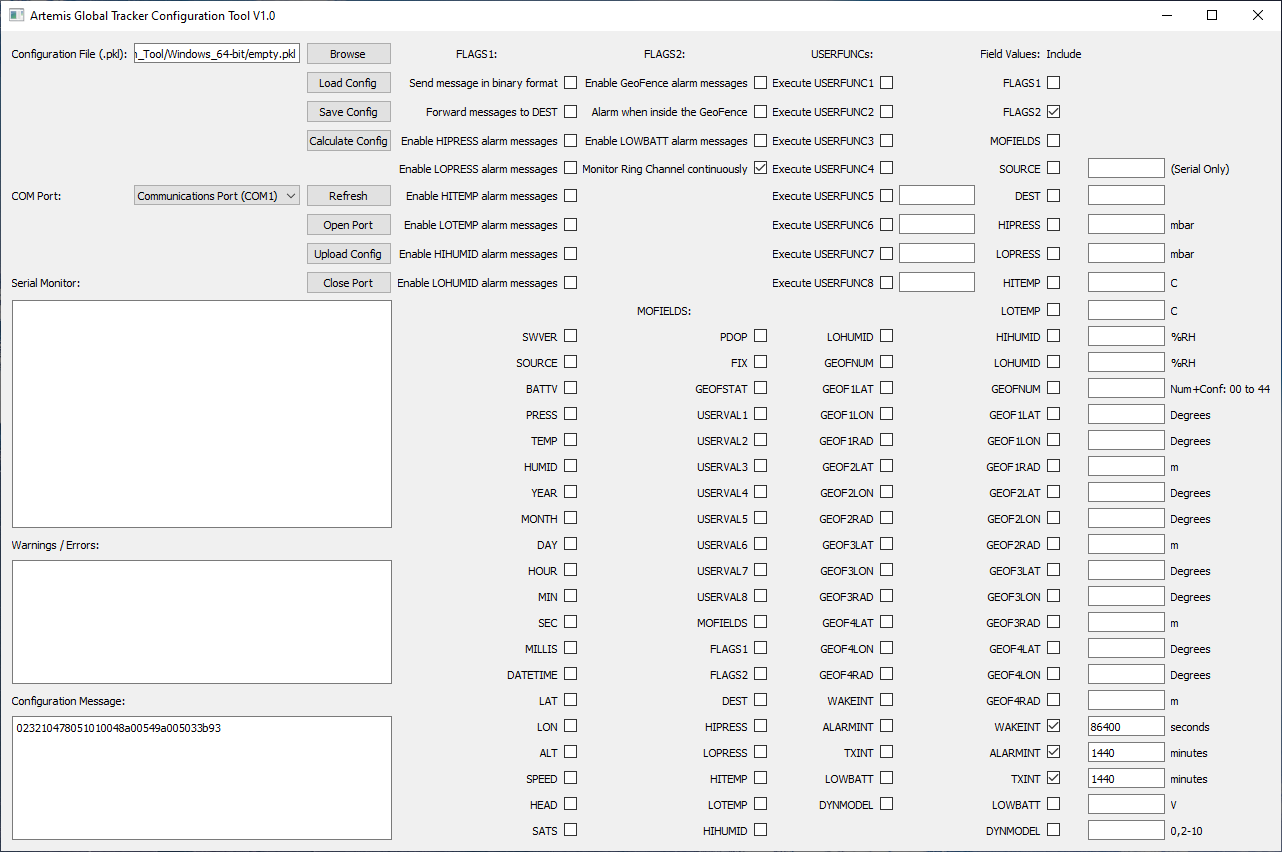
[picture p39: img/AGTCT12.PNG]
AGTCT12


[BACK](#How-do-I-monitor-the-ring-channel-continuously-for-new-MT-messages)

### AGTCT13
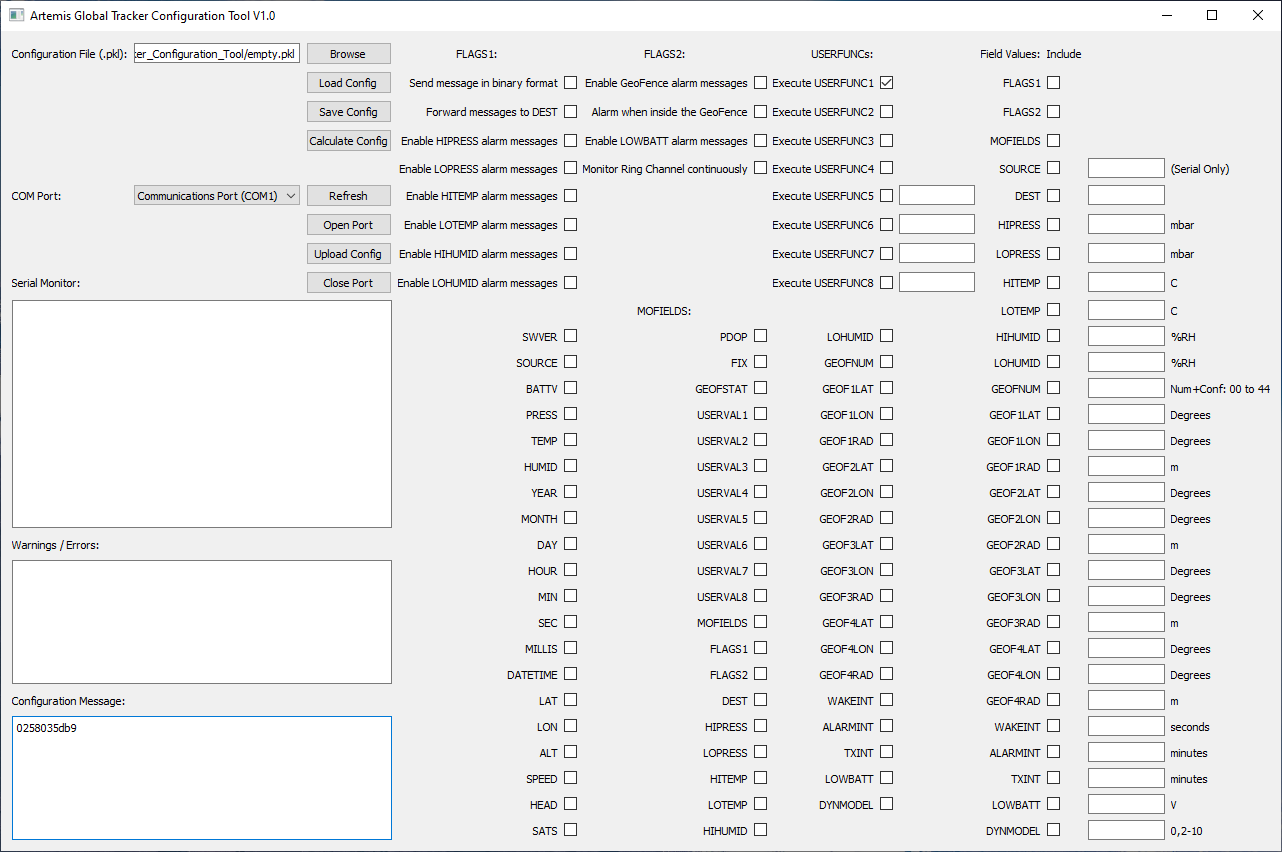
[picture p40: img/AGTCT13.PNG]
AGTCT13


[BACK](#How-do-I-define-and-trigger-a-user-function)

### AGTCT14
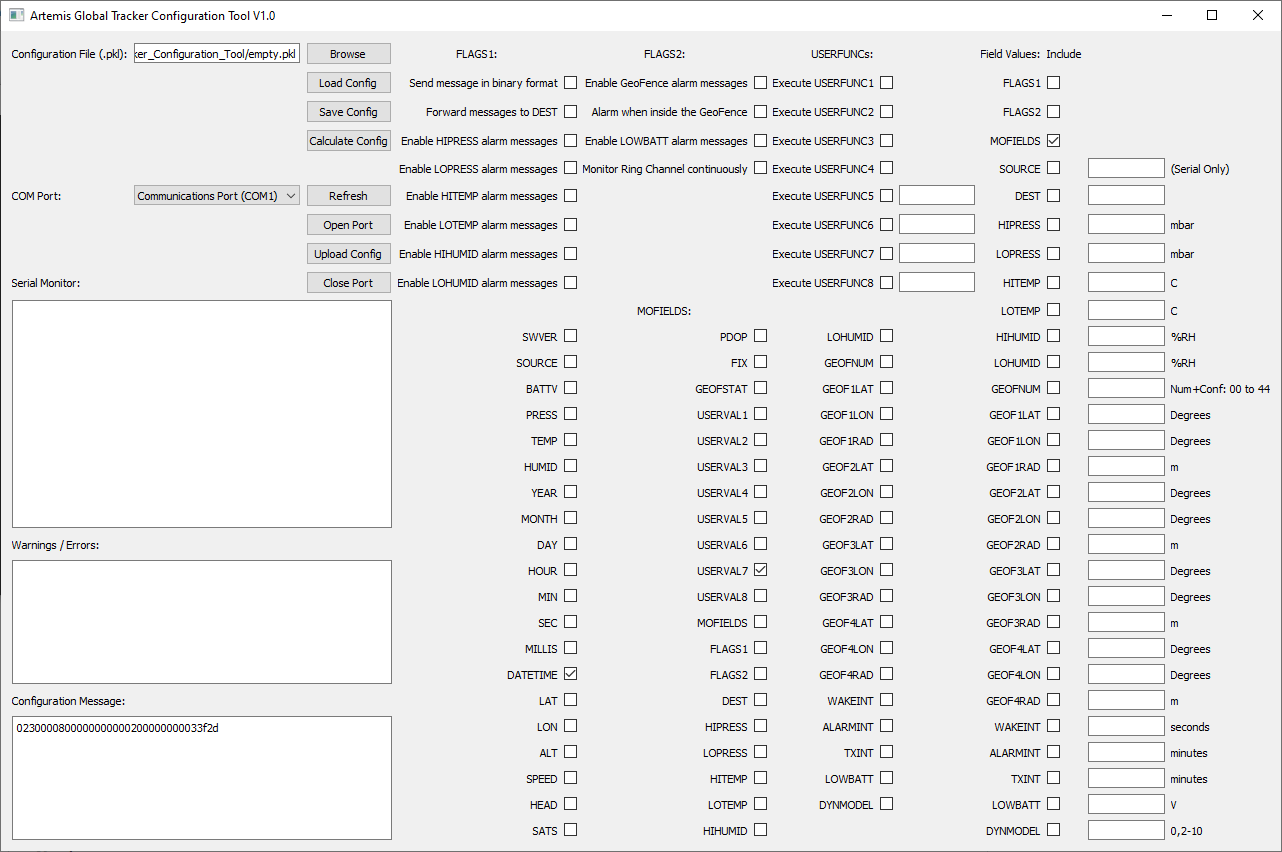
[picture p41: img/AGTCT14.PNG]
AGTCT14


[BACK](#How-do-I-send-a-user-value)

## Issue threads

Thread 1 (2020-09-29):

GNSS and iridium modem at the same time

eried, 2020-09-29:
If I cannot have both on without damaging the board (?):

Is it ok to be constantly switching them (i.e. every 5 minutes check the position) just to be always connected to receive Ring alerts? Has anyone tried this? (do Ring alerts actually repeat? so it is not that crucial to be offline for a while?)

PaulZC, 2020-09-29:
Hi Erwin (@eried),
You cannot have both GNSS and Iridium on at the same time as the antenna switch could be damaged. Iridium uses 5V and GNSS uses 3.3V. They could be connected through the antenna switch. Please do not try to enable both at the same time.
You will receive two ring alerts from Iridium, a few seconds apart, when there is a new message to be downloaded. But only two. They do not repeat again.
Please see Example11 for more details.
https://github.com/sparkfunX/Artemis_Global_Tracker/tree/master/Software/examples
I am closing this issue. If you need more help or suggestions, please ask in the SparkX Forum:
https://forum.sparkfun.com/viewforum.php?f=123
Best wishes,
Paul

Closed 2020-09-29.

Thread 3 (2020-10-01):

GPS and modem at the same time

eried, 2020-10-01:
I know is not possible, but is there is an easy hack to make this possible? (cutting some traces, adding an extra power regulator to that new rail? etc?)

Has anyone tried? This limitation is quite dumb i.e. if you want to constantly have ring alerts while checking the position with some logic on the artemis module.

PaulZC, 2020-10-02:
Hi Erwin (@eried ),
The only way to do this with the AGT would be to add a second GPS module, connected via Qwiic.
One of the design criteria for the AGT was to keep the mass as low as possible. Antenna sharing saves close to 15g.
Best wishes,
Paul

eried, 2020-10-02:
Thanks for the answer Paul, just to confirm as a rule of thumb I just should always call (in the examples) `gnssOFF()` before `digitalWrite(iridiumPwrEN, HIGH);` or `digitalWrite(iridiumPwrEN, LOW);` before `gnssON()` to be 100% on the safe side. Correct?

PaulZC, 2020-10-03:
Hi Erwin (@eried ),
To disable the Iridium modem, it is best to disable both the modem itself _and_ the supercapacitor charger:
https://github.com/sparkfunX/Artemis_Global_Tracker/blob/master/Software/examples/Example1_Blink/Example1_Blink.ino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
To disable the GNSS, yes, ```GNSSoff()``` will suffice:
https://github.com/sparkfunX/Artemis_Global_Tracker/blob/master/Software/examples/Example1_Blink/Example1_Blink.ino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
Good luck with your project!
Best wishes,
Paul

Closed 2020-10-02.

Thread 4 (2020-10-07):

Avoid reset when re-connecting via serial?

eried, 2020-10-07:
Hi, is there is any way to prevent the device from resetting if I close and open the serial port?

I see that the reset is:  ` resetResult.bEXTStat // Serial.println("External reset");`

PaulZC, 2020-10-07:
Hi Erwin,
We use the serial reset to put the Artemis into bootloader mode. It is possible to disable this but you would no longer be able to upload new code.
Best wishes,
Paul

eried, 2020-10-08:
Thanks for the answer, but there is no easy way to disable the reset in a temporal way and just require pressing the reset button when wanting to upload new code?

Since this is part of a global tracker, it would leave using the eeprom as the only option (i.e. to prevent losing messages received that reside on ram waiting to be downloaded via serial later)

PaulZC, 2020-10-08:
Hi Erwin,

I'm not sure what your end application is, but, yes, fair point, I can see why you would want to avoid the reset.

Message storage in EEPROM is certainly possible. The AGT settings are all stored in EEPROM in Example16.

Another way would be to connect a micro SD card via the SPI breakout pins. One of [these](https://www.sparkfun.com/products/544) should work nicely.

I really do not recommend it, and have never tried it, but you should be able to disable the reset by removing some of these components:
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

Regards,

Paul

Closed 2020-10-07.

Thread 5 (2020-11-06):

power consumption

jerabaul29, 2020-11-06:
Hi,

I see that you have a "low power" sketch and several mentions of "low power" uses, including recommending some batteries in the hardware overview.

Do you have some actual measurements of how much energy is typically used for transmitting / receiving a message, and the typical current draw of the uC in deep sleep as for example in the https://github.com/sparkfunX/Artemis_Global_Tracker/tree/master/Software/examples/Example12_TestLowPower sketch?

And / or said otherwise: if using 3 AA lithium batteries, and transmitting the GPS position once every 3 hours and doing nothing else (ie deep sleep for 3 hours, getting a GPS reading, sending it through Iridium), how long can I typically expect the module to work before the battery is empty?

PaulZC, 2020-11-07:
Hi JR (@jerabaul29),
Thanks for your interest in the Global Tracker.
I've just done a quick test and the sleep current is approximately 250uA. That's probably higher than usual as I haven't used this board for a while and the RTC battery will be charging. I'll leave it for a few hours and will check it again.
The second part of your question is more complex. It of course depends what batteries you are using and how often you are transmitting. The bulk of the power goes into charging the super capacitors for the Iridium transmit. I did use an earlier - less efficient - version of the tracker to track a balloon flight:
- Using three AA Energizer Ultimate Lithium
- During the flight the beacon was transmitting every 3 minutes and sent 140 messages
- The payload ended up in a tree and it was weeks before we could pick it up
- Transmitting twice per day for a month, it sent another 50 messages
- We then set it to transmit once per day and it sent another 17 messages before we finally collected it
- Battery voltage at the end was just under 4.0V. It was still quite happy.
- The flight ended up in a tree in Austria in March (2019). Daytime temperatures were around 0C. Heavy snow was the main thing from preventing us from collecting it.

The core design is very robust. We've had a lot of fun with it over the years.
There's a paper here that you might enjoy:
http://arxiv.org/abs/1904.04321
Best wishes,
Paul

jerabaul29, 2020-11-07:
That sounds excellent, many thanks for the technical details and the ArXiv link :) .

PaulZC, 2020-11-07:
Looks like the RTC battery is indeed charging. Current draw has dropped to around 220uA after ~1 hour.

PaulZC, 2020-11-07:
This is with the power LED disabled - of course! Open the split pad on the rear of the PCB to disable it.

PaulZC, 2020-11-09:
Hi JR (@jerabaul29) - I have checked the figures and have added more information here:
https://github.com/sparkfunX/Artemis_Global_Tracker/tree/master/Documentation/GlobalTracker_FAQs

jerabaul29, 2020-11-11:
Hi again!

I was thinking a bit about the power consumption while sleeping. It is quite a bit higher than the pure Apollo3 MCU. Do you see some ways to further reduce the deep sleep power consumption?

PaulZC, 2020-11-11:
Hi JR,
There are lots of very small current draws that add up to give the 220uA. The ~55uA quiescent current draw of the AP2112K regulator being just one. The ~30uA current draw of the Artemis being another. Beating the 220uA down below (say) 100uA would be a time-consuming project....
Best wishes,
Paul

Closed 2020-11-09.

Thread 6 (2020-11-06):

power in: minimum voltage

jerabaul29, 2020-11-06:
In the documentation:

https://github.com/sparkfunX/Artemis_Global_Tracker/tree/master/Documentation/Hardware_Overview

you mention that one can power the module with:

"an external solar panel or battery pack (6V maximum)".

There is not indication of the minimum voltage needed. I suppose it is min_voltage_in = 3.3V + loss_regulator ? What is the typical loss in the regulator that needs to be factored in in choosing the battery?

PaulZC, 2020-11-07:
Hi again JR (@jerabaul29),
It depends... At 200mA current draw, the AP2112K regulator has a drop-out of approx. 75mV. So, 3.375V is the official answer.
However, you can push it lower than that. Yes, the regulator will start to drop out, but the Artemis will be quite happy down to 1.8V. The super capacitor charger needs a minimum of 2.8V. The ZOE-M8Q is OK down to 2.7V.
The current draw does increase as the regulator goes into drop-out so you need to be aware of that.
Energizer Ultimate Lithium batteries will deliver around 1.1V per cell when very cold (around -40C).
The design includes a low voltage reset supervisor which helps - mostly for solar power where the voltage can rise very slowly at sunrise.
Best wishes,
Paul

jerabaul29, 2020-11-07:
Ok, many thanks for the technical details and the confirmation :) . I think for the Arctic and Antarctic (which I am interested in :) ). I would then use 4 LiTi batteries just to be on the safe side :) .

PaulZC, 2020-11-07:
Just make sure that they can deliver enough current. Some Lithium chemistries can only deliver a few mA continuous draw.
Saft LSH batteries are good - but don't go higher than 6.0V or bad things will happen...
A fresh Energizer Lithium AA or AAA will deliver around 1.8V. It soon droops, but you do need to be aware.

PaulZC, 2020-11-09:
Hi JR (@jerabaul29) - I have checked the figures and have added more information here:
https://github.com/sparkfunX/Artemis_Global_Tracker/tree/master/Documentation/GlobalTracker_FAQs

Closed 2020-11-09.

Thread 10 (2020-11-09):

bluetooth

jerabaul29, 2020-11-09:
If I understand well the Artemis uC has bluetooth abilities, right? :) So do you think a method of this kind:

https://learn.sparkfun.com/tutorials/artemis-development-with-the-arduino-ide/bluetooth-led

Could be used to start / parametrize the tracker? That would be especially attracting for applications where a fully sealed IP 68 or higher box is built, and you need to start it at the deployment time without the need to open it / fiddle with switches etc :) .

PaulZC, 2020-11-09:
Hi JR,
The AGT will support BLE - but not at the moment. Upgrading to v2 of the Apollo3 core is on the things-to-do list!
Best wishes,
Paul

jerabaul29, 2020-12-06:
Just being curious - this would mean shifting from an Arduino "main loop" programming paradigm to a "threaded RTOS" one, right? That would be interesting to follow :) .

razvandragomirescu, 2021-07-29:
Is Bluetooth going to "just work" after the upgrade to v2 of the Apollo3 core? I have not updated yet because the AGT Iridium examples stopped working when I tried that. Is there a particular version that supports both BLE and Iridium?

PaulZC, 2021-07-30:
Hi @razvandragomirescu ,
The upgrade to v2 of the Apollo3 core is still on the to-do list. We recently upgraded OpenLog Artemis to use v2.1.0 of the core and are now working on adding ways of accessing the sensor data over BLE. The AGT is next.
So, to answer your question, yes, the AGT will support both BLE and Iridium when the upgrade is complete. You will be able to use the standard ArduinoBLE library to advertise services and add characteristics etc..
Thank you for your patience,
Paul

PaulZC, 2021-07-30:
Hi @jerabaul29 ,

I would like to start a discussion about how the BLE functionality on the AGT should behave / perform. Please add your thoughts to Issue #34.

Many thanks,
Paul

jerabaul29, 2021-08-02:
Sounds good. Closing this in favor of 34 then :) .

PaulZC, 2021-08-02:
Thank you JR,
Best wishes,
Paul

Closed 2021-08-02.

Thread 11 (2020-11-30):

supercapacitor

jerabaul29, 2020-11-30:
Hi,

I just bought a couple of the module trackers from Sparkfun. However, it seems that they come without the supercapacitors. This is a bit sad, as these are not mentioned in the list of "essential components" (I will write to sparkfun to get this added to the list), I guess I will have to place an additional order...

One thing about these capacitors: it is written that these should be 10F, 2.7V. I cannot find supercapacitors with such speccing from Sparkfun, the closest I get is these, but I guess they will not like at all the 2.7V part of it :(

https://www.sparkfun.com/products/746

My question is then: which super capacitor did you use / where did you source it? :)

Cheers,

JR

PaulZC, 2020-11-30:
Hi JR (@jerabaul29 ),
The AGT comes equipped with 1F supercapacitors. You only need the extra 10F supercapacitors if you change the charge current to 60mA.
Please see the documentation here:
https://github.com/sparkfunX/Artemis_Global_Tracker/tree/master/Documentation/Hardware_Overview#iridium-9603n
Best wishes,
Paul

PaulZC, 2020-11-30:
Hi JR (@jerabaul29 ),
I've added this to the FAQs too:
https://github.com/sparkfunX/Artemis_Global_Tracker/tree/master/Documentation/GlobalTracker_FAQs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
Best wishes,
Paul

jerabaul29, 2020-11-30:
Ah, I had missed that, many thanks!

Closed 2020-11-30.

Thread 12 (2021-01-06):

using own power regulator, bypassing low dropout regulator

jerabaul29, 2021-01-06:
I would like to bypass the low drop power regulators that are present on the board and use some step up-step down converters instead due to the technology of batteries I want to use.

Would it be ok to use this regulator:

https://www.pololu.com/product/2561

"This 3.3 V boost (step-up) voltage regulator generates higher output voltages from input voltages as low as 0.5 V, and it also automatically switches to a linear down-regulation mode when the input voltage exceeds the output. This makes it great for powering 3.3 V electronics projects from 1 to 3 NiMH, NiCd, or alkaline cells or from a single lithium-ion cell."

And use it to directly feed to the 3.3V pin?

jerabaul29, 2021-01-06:
(i.e.:

- is it enough to only provide a well-regulated 3.3V input to the whole board?
- if providing a well-regulated 3.3V input to the board, where to feed it so that we bypass the regulators and avoid their power drops?

jerabaul29, 2021-01-06:
From reading the schematics at https://github.com/sparkfunX/Artemis_Global_Tracker/blob/master/Documentation/Hardware_Overview/README.md it looks like:

- USB, Solar and Lipo are all fed into the VBUS through diodes
- VBUS is fed (through a cuttable pad to measure power usage) to VIN
- VIN is used as input to the low dropout power generator, to generate the 3.3V supply used by everything on the board (except the USB interface of course).

That would speak in favor of simply feeding the output of the buck converter into the GND and 3.3V pins, for example the one on the side of the SDA / SCL pins. Can you confirm that? :)

jerabaul29, 2021-01-06:
One more thing: if this understanding is right, can you update a bit the "Power Options" section:

https://github.com/sparkfunX/Artemis_Global_Tracker/blob/master/Documentation/Hardware_Overview/README.md

saying that there is more info in the FAQ at https://github.com/sparkfunX/Artemis_Global_Tracker/blob/master/Documentation/GlobalTracker_FAQs/README.md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

And in the FAQ, can you make it clear that there are in addition to the recommended modes of powering 2 "unsafe / expert modes" ways to power: either 1) through the VBUS in which case the polarity protection is dropped but not the low dropout regulator (i.e. input should be 3.4V to 6.0V), or 2) directly through the 3.3V common power rail, in which case there will be no polarity nor voltage protection, and the only acceptable voltage is EXACTLY 3.3V, as provided for example by a step up / step down converter?

PaulZC, 2021-01-07:
Hi JR (@jerabaul29 ),
I hope your project is going well.
I've added the link to the FAQs from the Hardware Overview as requested.
Sorry, no, I won't be adding any notes about unsafe / expert modes for powering the board. You are welcome to try the buck/boost regulator and it will probably work fine, but it is at your own risk.
Best wishes,
Paul

jerabaul29, 2021-01-07:
Ok, no worries. Thanks for confirming it should work fine.

PaulZC, 2021-01-07:
"probably"
;-D

jerabaul29, 2021-01-07:
(btw, to give you some context: thanks again for your product, you came up with a great design. We had a very small scale test here at the Norwegian Meteorological Institute a few weeks ago and were happy with the results, so we just ordered a new batch of 10 of these for a small pilot study. We will deploy these as sea ice drifting trackers in the Arctic. We expect temperatures down to -40, and some preliminary tests showed that even Li batteries had a bit of trouble then, which is why we need to add a step up / step down regulator).

jerabaul29, 2021-02-11:
(fyi: this works fine in the cold, we are getting messages from our first instruments deployed 78N :) ). I mistakenly put some of the step-up / step-down on VBUS instead of 3.3V, but seems to work fine too.

Closed 2021-01-07.

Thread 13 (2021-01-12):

adding external 3-wires sensor

jerabaul29, 2021-01-12:
I want to add a 3-wire sensor in this kind: https://www.sparkfun.com/products/11050

Do you think it will be ok to interface it on the board pins D35 and / or D4? These are not used for anything else, right?

Btw, this is the only thing that is a bit sad: not having access to more of the MCU pins. Guess there is no way with the present board to access more pins, right? If there is a v2 some time, would be great with having more pins available for doing other stuff :) .

PaulZC, 2021-01-13:
Hi JR,

One of the design requirements for the AGT was to keep it as small and as light as possible. It is a very compact, congested PCB. Squeezing in extra Input/Output breakouts would be difficult...

Yes, you can use D35 or D4 to interface to that sensor. They are not used for anything else. If you are not using the SPI pins, then you can use those for I/O or one-wire too. They are D5, D6, D7:
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

If you need more I/O, there are I2C or SPI "port expanders" available:
https://www.sparkfun.com/products/17047

Best wishes,
Paul

Closed 2021-01-13.

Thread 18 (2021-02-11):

cannot start the GPS on the core v 2.0.5

jerabaul29, 2021-02-11:
I do not manage to turn on the GPS using the core v 2.0.5.

I noticed that you use ```Wire1``` and not ```Wire``` for talking to the GPS:

https://github.com/sparkfunX/Artemis_Global_Tracker/blob/5e40b4283dfdd46b7b90fed9639ad0af667707ea/Software/examples/Example14_SimpleTracker/Example14_SimpleTracker.i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

and in all the following.

However in the core v 2.0.5 I can only use ```Wire```. Is it that there are several I2C buses, and ```Wire``` vs ```Wire1``` are two different buses, or something in this kind? In this case, I suppose I would need that the ```Wire1``` gets added to the core v 2.0.5 for it to work, right? Or do you see another workaround?

PaulZC, 2021-02-11:
This example might help?
https://github.com/sparkfun/Arduino_Apollo3/blob/master/libraries/Apollo3/examples/I2C/I2C.ino

jerabaul29, 2021-02-11:
Ah yes you are right, thanks! So I should be able to do something in this kind then, right? :) Will look at it tonight or tomorrow.

https://github.com/sparkfun/Arduino_Apollo3/blob/fbb2eaca27245627bf22b59f43faa232635bcd01/libraries/Apollo3/examples/I2C/I2C.ino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

jerabaul29, 2021-02-12:
Mmmh, getting new issues.

From reading the schematics, I am thinking that the pins to use are D9 and D8. So I tried something like:

```cpp
#include <Wire.h> //Needed for I2C to GNSS

[...]

MbedI2C gps_wire(D9, D8);
```

But I get an error:

```
first start GPS I2C port

++ MbedOS Error Info ++
Error Status: 0x80010130 Code: 304 Module: 1
Error Message: pinmap not found for peripheral
Location: 0x25053
Error Value: 0xC
Current Thread: main Id: 0x10004BA8 Entry: 0x26975 StackSize: 0x1000 StackMem: 0x10006818 SP: 0x10007754
For more info, visit: https://mbed.com/s/error?error=0x80010130&tgt=SFE_ARTEMIS
-- MbedOS Error Info --
```

This is quite clear error message, so I also tried:

```cpp
MbedI2C gps_wire(D8, D9);
```

But same kind of error. Any idea how this should be done instead?

jerabaul29, 2021-02-12:
Ok, getting closer: the issue is in how the pins are described. The "D" should be removed, i.e., this works:

```cpp
MbedI2C gps_wire(9, 8);
```

jerabaul29, 2021-02-12:
Ok, back to being stuck... Now my code looks essentially like this (taking away a bit of the usual verbose serial enabling etc):

```cpp
#define gnssEN              26 // GNSS Enable: pull low to enable power for the GNSS (via Q2)

MbedI2C gps_wire(9, 8);
gps_wire.begin();
delay(10);

pinMode(gnssEN, OUTPUT); // Configure the pin which enables power for the ZOE-M8Q GNSS
digitalWrite(gnssEN, LOW); // Enable GNSS power (HIGH = disable; LOW = enable)
delay(2000);

    while (true){
        if (gps.begin(gps_wire)){
            Serial.println(F("GPS started"));
            break;
        }
        else{
            Serial.println(F("could not start the GPS"));
            delay(1000);
        }
    }
```

But I get locked in the ```Could not start the GPS``` thing.

- anything I do wrong?
- if not, anybody else who can reproduce the problem?

jerabaul29, 2021-02-12:
Unsuccessful so far after quite a few hours of trying to get this to work. This is my "least complexity example". Anything that looks wrong / are you able to reproduce the problem / any idea how to fix?

```cpp
#include <Wire.h> // Needed for I2C

// #include <SparkFun_Ublox_Arduino_Library.h> //http://librarymanager/All#SparkFun_Ublox_GPS
#include <SparkFun_u-blox_GNSS_Arduino_Library.h>
SFE_UBLOX_GNSS myGPS;

//--------------------------------------------------------------------------------
// from Example 14
// Artemis Tracker pin definitions
#define spiCS1              4  // D4 can be used as an SPI chip select or as a general purpose IO pin
#define geofencePin         10 // Input for the ZOE-M8Q's PIO14 (geofence) pin
#define busVoltagePin       13 // Bus voltage divided by 3 (Analog in)
#define iridiumSleep        17 // Iridium 9603N ON/OFF (sleep) pin: pull high to enable the 9603N
#define iridiumNA           18 // Input for the Iridium 9603N Network Available
#define LED                 19 // White LED
#define iridiumPwrEN        22 // ADM4210 ON: pull high to enable power for the Iridium 9603N
#define gnssEN              26 // GNSS Enable: pull low to enable power for the GNSS (via Q2)
#define superCapChgEN       27 // LTC3225 super capacitor charger: pull high to enable the super capacitor charger
#define superCapPGOOD       28 // Input for the LTC3225 super capacitor charger PGOOD signal
#define busVoltageMonEN     34 // Bus voltage monitor enable: pull high to enable bus voltage monitoring (via Q4 and Q3)
#define spiCS2              35 // D35 can be used as an SPI chip select or as a general purpose IO pin
#define iridiumRI           41 // Input for the Iridium 9603N Ring Indicator
// Make sure you do not have gnssEN and iridiumPwrEN enabled at the same time!
// If you do, bad things might happen to the AS179 RF switch!

void gnssON(void) // Enable power for the GNSS
{
  digitalWrite(gnssEN, LOW); // Disable GNSS power (HIGH = disable; LOW = enable)
  pinMode(gnssEN, OUTPUT); // Configure the pin which enables power for the ZOE-M8Q GNSS
}

void gnssOFF(void) // Disable power for the GNSS
{
  pinMode(gnssEN, INPUT_PULLUP); // Configure the pin which enables power for the ZOE-M8Q GNSS
  digitalWrite(gnssEN, HIGH); // Disable GNSS power (HIGH = disable; LOW = enable)
}
//--------------------------------------------------------------------------------

void setup(){
  //--------------------------------------------------------------------------------
  // from example 14
  // Let's begin by setting up the I/O pins

  pinMode(LED, OUTPUT); // Make the LED pin an output

  gnssOFF(); // Disable power for the GNSS
  pinMode(geofencePin, INPUT); // Configure the geofence pin as an input

  pinMode(iridiumPwrEN, OUTPUT); // Configure the Iridium Power Pin (connected to the ADM4210 ON pin)
  digitalWrite(iridiumPwrEN, LOW); // Disable Iridium Power (HIGH = enable; LOW = disable)
  pinMode(superCapChgEN, OUTPUT); // Configure the super capacitor charger enable pin (connected to LTC3225 !SHDN)
  digitalWrite(superCapChgEN, LOW); // Disable the super capacitor charger (HIGH = enable; LOW = disable)
  pinMode(iridiumSleep, OUTPUT); // Iridium 9603N On/Off (Sleep) pin
  digitalWrite(iridiumSleep, LOW); // Put the Iridium 9603N to sleep (HIGH = on; LOW = off/sleep)
  pinMode(iridiumRI, INPUT); // Configure the Iridium Ring Indicator as an input
  pinMode(iridiumNA, INPUT); // Configure the Iridium Network Available as an input
  pinMode(superCapPGOOD, INPUT); // Configure the super capacitor charger PGOOD input

  pinMode(busVoltageMonEN, OUTPUT); // Make the Bus Voltage Monitor Enable an output
  digitalWrite(busVoltageMonEN, LOW); // Set it low to disable the measurement to save power
  analogReadResolution(14); //Set resolution to 14 bit
  //--------------------------------------------------------------------------------

  Serial.begin(115200);
  delay(10);
  Serial.println(F("booted"));

  // on the new core, no Wire1, need to define which pins to use
  MbedI2C gps_wire(9, 8);
  gps_wire.setClock(100000);

  Serial.println(F("Powering up the GNSS..."));
  gps_wire.begin();
  gnssON();
  delay(2000); // Give it time to power up

  if (myGPS.begin(gps_wire) == false) //Connect to the Ublox module using Wire port
  {
    Serial.println(F("unable to start GPS"));
  }
  else{
    Serial.println(F("able to start GPS"));
  }

  Serial.println(F("done with setup"));
}

void loop(){
}
```

PaulZC, 2021-08-09:
Hi JR (@jerabaul29 ),

Thank you for your patience!
I am about to release version 2.0 of the AGT firmware / examples - updated and built using v2.1.0 of the Apollo3 core.
If you are going to re-use the examples, please use **v2.1.0** of the core - not v2.1.1. (v2.1.1 contains a new 'feature' which makes I2C communication with the ZOE-M8Q problematic).
As my American colleagues would say, please kick the tyres and let me know what you find.

Very best wishes,
Paul

Closed 2021-08-09.

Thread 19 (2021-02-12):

cannot start the Iridium modem on the core v 2.0.5

jerabaul29, 2021-02-12:
I cannot start the Iridium modem on the core v 2.0.5. Minimum example failing:

```cpp

//--------------------------------------------------------------------------------
// from example 14

// Artemis Tracker pin definitions
#define spiCS1              4  // D4 can be used as an SPI chip select or as a general purpose IO pin
#define geofencePin         10 // Input for the ZOE-M8Q's PIO14 (geofence) pin
#define busVoltagePin       13 // Bus voltage divided by 3 (Analog in)
#define iridiumSleep        17 // Iridium 9603N ON/OFF (sleep) pin: pull high to enable the 9603N
#define iridiumNA           18 // Input for the Iridium 9603N Network Available
#define LED                 19 // White LED
#define iridiumPwrEN        22 // ADM4210 ON: pull high to enable power for the Iridium 9603N
#define gnssEN              26 // GNSS Enable: pull low to enable power for the GNSS (via Q2)
#define superCapChgEN       27 // LTC3225 super capacitor charger: pull high to enable the super capacitor charger
#define superCapPGOOD       28 // Input for the LTC3225 super capacitor charger PGOOD signal
#define busVoltageMonEN     34 // Bus voltage monitor enable: pull high to enable bus voltage monitoring (via Q4 and Q3)
#define spiCS2              35 // D35 can be used as an SPI chip select or as a general purpose IO pin
#define iridiumRI           41 // Input for the Iridium 9603N Ring Indicator
// Make sure you do not have gnssEN and iridiumPwrEN enabled at the same time!
// If you do, bad things might happen to the AS179 RF switch!

void gnssON(void) // Enable power for the GNSS
{
  pinMode(gnssEN, OUTPUT); // Configure the pin which enables power for the ZOE-M8Q GNSS
  digitalWrite(gnssEN, LOW); // Disable GNSS power (HIGH = disable; LOW = enable)
}

void gnssOFF(void) // Disable power for the GNSS
{
  pinMode(gnssEN, INPUT_PULLUP); // Configure the pin which enables power for the ZOE-M8Q GNSS
  digitalWrite(gnssEN, HIGH); // Disable GNSS power (HIGH = disable; LOW = enable)
}

// Declares a Uart object called Serial using instance 1 of Apollo3 UART peripherals with RX on variant pin 25 and TX on pin 24
// (note, in this variant the pins map directly to pad, so pin === pad when talking about the pure Artemis module)
UART iridiumSerial(1, 25, 24);

#include <IridiumSBD.h> //http://librarymanager/All#IridiumSBDI2C
#define DIAGNOSTICS false // Change this to true to see IridiumSBD diagnostics
// Declare the IridiumSBD object (including the sleep (ON/OFF) and Ring Indicator pins)
IridiumSBD modem(iridiumSerial, iridiumSleep, iridiumRI);

void setup(){
  //--------------------------------------------------------------------------------
  // from example 14
  // Let's begin by setting up the I/O pins

  pinMode(LED, OUTPUT); // Make the LED pin an output

  gnssOFF(); // Disable power for the GNSS
  pinMode(geofencePin, INPUT); // Configure the geofence pin as an input

  pinMode(iridiumPwrEN, OUTPUT); // Configure the Iridium Power Pin (connected to the ADM4210 ON pin)
  digitalWrite(iridiumPwrEN, LOW); // Disable Iridium Power (HIGH = enable; LOW = disable)
  pinMode(superCapChgEN, OUTPUT); // Configure the super capacitor charger enable pin (connected to LTC3225 !SHDN)
  digitalWrite(superCapChgEN, LOW); // Disable the super capacitor charger (HIGH = enable; LOW = disable)
  pinMode(iridiumSleep, OUTPUT); // Iridium 9603N On/Off (Sleep) pin
  digitalWrite(iridiumSleep, LOW); // Put the Iridium 9603N to sleep (HIGH = on; LOW = off/sleep)
  pinMode(iridiumRI, INPUT); // Configure the Iridium Ring Indicator as an input
  pinMode(iridiumNA, INPUT); // Configure the Iridium Network Available as an input
  pinMode(superCapPGOOD, INPUT); // Configure the super capacitor charger PGOOD input

  pinMode(busVoltageMonEN, OUTPUT); // Make the Bus Voltage Monitor Enable an output
  digitalWrite(busVoltageMonEN, LOW); // Set it low to disable the measurement to save power
  analogReadResolution(14); //Set resolution to 14 bit
  //--------------------------------------------------------------------------------

  Serial.begin(115200);
  delay(10);
  Serial.println(F("booted"));
  delay(100);

  // Enable power for the 9603N
  Serial.println(F("Enabling 9603N power..."));
  digitalWrite(iridiumPwrEN, HIGH); // Enable Iridium Power
  delay(1000);

  // Enable the 9603N and start talking to it
  Serial.println(F("Beginning to talk to the 9603..."));

  // Start the serial port connected to the satellite modem
  iridiumSerial.begin(19200);
  delay(1000);

  // Relax timing constraints waiting for the supercap to recharge.
  modem.setPowerProfile(IridiumSBD::USB_POWER_PROFILE);

  // Begin satellite modem operation
  Serial.println(F("Starting modem..."));
  int err;
  err = modem.begin();

  // Check if the modem started correctly
  if (err != ISBD_SUCCESS){
    // If the modem failed to start, disable it and go to sleep
    Serial.print(F("***!!! modem.begin failed with error "));
    Serial.print(err);
    Serial.println(F(" !!!***"));
  }
  else{
    Serial.println(F("successful start of modem"));
  }
}

void loop(){

}
```

- any idea what may be wrong?
- any idea how to fix it?

jerabaul29, 2021-02-12:
This may be related to a "pure custom serial issue", see issue opened here: https://github.com/sparkfun/Arduino_Apollo3/issues/349 .

PaulZC, 2021-08-09:
Hi JR (@jerabaul29 ),

Thank you for your patience!
I am about to release version 2.0 of the AGT firmware / examples - updated and built using v2.1.0 of the Apollo3 core.
If you are going to re-use the examples, please use **v2.1.0** of the core - not v2.1.1. (v2.1.1 contains a new 'feature' which makes I2C communication with the ZOE-M8Q problematic).
As my American colleagues would say, please kick the tyres and let me know what you find.

Very best wishes,
Paul

Closed 2021-08-09.

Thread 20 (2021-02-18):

Adding an I2C sensor - any way to do so in a way that easily turned on / off

jerabaul29, 2021-02-18:
Hi :)

I want to add the BNO080 to an instrument based on this board. As it looks like we cannot at the moment get really low power with the BNO080, I will have to turn it on / off by enabling / cutting power supply to it.

- from the schematics it looks like the Qwiic port is always power on, right (I see no MOSFET controlling power to it)? Or is there a way to turn power on / off on the devices on the Qwiic port?

- another possibility would be to put the BNO on the same power ramp as the GPS, and use a GPS low power mode when it is not in use but the BNO is (the GPS has a low power mode if I remember well? :) ). The challenge it seems is to get access to this power rail. I do not see any obvious place where I could easily solder a couple of wires to get power. Or am I missing something?

- I guess if both previous options are not possible that I will have to just add a separate small PCB with its own MOSFET or similar, right? Or is there another solution I could consider?

jerabaul29, 2021-02-18:
Ahhh, I see a solution: the BNO080 should be happy with everything above 2.4V according to its datasheet Fig. 6.2, right? :) Then I should be able to tap power from the pins of one of the supercapacitors, right? :) Something like:

- putting the iridium modem to sleep
- switching on capacitor charging
- starting to talk to the BNO

Or am I thinking wrongly?

jerabaul29, 2021-02-18:
(of course that would be a hack, but but, good enough for a prototype / proof of concept to me, and we will design a custom board later on if we are allowed to continue in this direction).

jerabaul29, 2021-02-18:
(I would need just to find which is C5 vs C6 I guess to make sure I have the right ground, but I can check that by hand on one of my boards :) If you can tell which one is the one to use, just for double checking, that would be great though :) ).

jerabaul29, 2021-02-18:
Mmmh, no, checked out in more details, that will not work: the datasheet says the voltage on SDA / SCL should not be over Vin. So not possible to power with 2.7V if the logics are at 3.3V I am afraid.

There is one pad under the ATG that I am curious about: the "VIN/3" mini pad in the rectangle around a supercapacitor. I have a hard time figuring out what it is couple to. Is it on one of the MOSFETs?

PaulZC, 2021-02-19:
Hi JR,
Ideally, you need the Qwiic Power Switch but it is out of stock at the moment. [Mouser have 5](https://www.mouser.co.uk/ProductDetail/SparkFun/SPX-16740/?qs=DPoM0jnrROVJN3KjZlloUg%3D%3D).
Correct, the Qwiic power is not switched.
My suggestion would be to hook up the BNO080 to the GPS/MS8607 I2C bus using the breakout pins on the left side of the board. You then need to solder a wire to **3V3SW** to provide switched power. The easiest places to do that would be at Q2:
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
Or at the GNSS power LED resistor R16:
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
VIN/3 let's the Artemis check the VIN power rail.
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
Actually, that's an alternative for you. You could pick up **VIN** power from the 'top' of R24 but you _**must**_ then regulate it to 3.3V before passing it to the BNO080.
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
I hope this gets you going.
Paul

jerabaul29, 2021-02-19:
Many thanks for your kind help :) . I will consider either putting it on the GPS LED, or using an additional (I already use 1 to feed power to the board) external pololu regulator, which can be driven on and off through an activate pin.

Closed 2021-02-19.

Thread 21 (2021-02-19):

charging the GPS backup battery (and keeping it charged)

jerabaul29, 2021-02-19:
@PaulZC I notice that I quite seldom get a "1s hotfix" on the GPS despite the presence of the battery.

I had a look at the schematics. It looks like the only way to charge the battery is to use V_USB, as the diodes would prevent other sources of power to charge it. Is this the right understanding or am I missing something? What is the recommended way to get this small battery fully charged before deployment (and to keep it charged during deployment :) )?

jerabaul29, 2021-02-19:
(would putting a jumper between the 3.3V rail and the + side of the battery help? :) ^^ ).

PaulZC, 2021-02-20:
Hi JR,
Correct, the back-up battery only charges when USB is connected as shown in [this section](https://github.com/sparkfunX/Artemis_Global_Tracker/tree/master/Documentation/Hardware_Overview#zoe-m8q).
If you try different ways of charging the battery, make sure you limit the current appropriately. Connecting directly to 3.3V will release the magic white smoke...
Paul

Closed 2021-02-20.

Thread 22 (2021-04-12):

Examples do not work with any version >v1.2.0

miquelmassot, 2021-04-12:
Since [Arduino_Apollo3](https://github.com/sparkfun/Arduino_Apollo3) got updated to use mbedOS from v2.0.0 the code examples provided do not compile.

PaulZC, 2021-04-12:
Hi Miquel (@miquelmassot ),
Yes, we are aware of this, thank you. This is the same as issues #19 and #18.
We are waiting for issue 2.1.0 of the Apollo3 core to fix these issues.
I will leave this issue open until then as a reminder.
Best wishes,
Paul

a-schneider-fmi, 2021-07-20:
In the mean time, Apollo3 2.1.1 has been released. Compilation works for example 1 but fails for all other examples. When will a compilable tracker firmware be available?

PaulZC, 2021-07-20:
Hi Andreas (@a-schneider-fmi ),

We are working on it! ;-)

We have just released v2 of the OpenLog Artemis firmware which includes the upgrade to v2.1.0 of the core. Upgrading the AGT firmware is on the things-to-do list - but there are other things above it... I can't promise when the upgrade will happen, but it will be sometime over the next month as we have a project coming up which will need the upgrade.

Best wishes,
Paul

razvandragomirescu, 2021-07-29:
I have it all working with the older core but Bluetooth does not work with that - I understand that after v2 BLE will work but the examples will not and I need to make them both work for the particular project I am working on.

PaulZC, 2021-07-30:
Hi @razvandragomirescu / @a-schneider-fmi / @miquelmassot ,

I would like to start a discussion about the BLE functionality on the AGT should behave / perform. Please add your thoughts to Issue #34.

Many thanks,
Paul

PaulZC, 2021-08-09:
Hi @miquelmassot / @a-schneider-fmi / @razvandragomirescu ,

Thank you for your patience!
I am about to release version 2.0 of the AGT firmware / examples - updated and built using v2.1.0 of the Apollo3 core.
If you are going to re-use the examples, please use **v2.1.0** of the core - not v2.1.1. (v2.1.1 contains a new 'feature' which makes I2C communication with the ZOE-M8Q problematic).
I have not added any BLE examples or functionality - just getting the existing 16 examples updated has taken quite a while - but at least you now have a working skeleton on which to add BLE.
As my American colleagues would say, please kick the tyres and let me know what you find.

Very best wishes,
Paul

Closed 2021-08-09.

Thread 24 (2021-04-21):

a bit of user feedback from happy customers :)

jerabaul29, 2021-04-21:
Hi @PaulZC ,

I have been using the global tracker quite a bit (not for balloons, but other applications), and suggesting these to several people around me. I think everybody is very happy about it (we have used something like 20 of them so far, and are waiting for them to get back into stock for buying more). I / we think there is quite a market for this "iridium + gps + MCU + power regulation + available SPI, I2C, and digital pins" configuration, and it is really amazing that you help drive things forward :) . Many people in geosciences are interested when I present what we do with these modules, so that may become a quite big market (I hope it will, as I guess this would drive down module costs and help improve code and libraries support for my use ^^ ).

I have collected a bit of use feedback, if this may be of interest to you. As a note, we are not interested in balloons, so for us smaller and lighter is a nice to have (as we can have smaller enclosures), but not a super high priority. I understand this may differ from user to user though :) . We are mostly interested in 1) ease of use (in particular power supply robustness), 2) power efficiency, 3) possibility to add stuff to the MCU (i.e. many pins and pads available).

But anyways, the main feedback so far:

- we miss a bit the presence of a step up / step down power converter. LDO is nice, but when using some "low peak power" Li cells (which have higher capacity at the cost of peak current), the voltage now and then drops a bit. Adding a step up / step down converter fixes things (and this is what we do), as well as provides more efficiency when feeding from 3xAA batteries. Would be great to have one on the board, as this would be a guarantee that things "just work" with a variety of batteries and fluctuating input voltage, and would take the burden of providing regulated input voltage off the user. I understand such converters have a tiny bit of quiescent current, but I think that we would be willing to pay this price. Also, I wonder if it would be possible to have a bit of electronics (a transistor or two probably) so that one can choose to either 1) feed from the battery directly (possibly through a small LDO for safety) turning off the step up step down converter (this is when the board is sleeping and only the Ambiq MCU, which needs low voltage and power anyways, needs power while sleeping), or 2) power from the step up step down when more power is needed, turning it on from the Ambiq in software when needed. Do you think something like this may be doable, with a capacitor or something like this to ensure smooth transition back and forth between both modes?

- we miss a bit having more pins from the Ambiq MCU being broken out. This is our main issue now. There is quite a bit of space left on the "periphery" of the board, and it would be amazing to "fill it up" with as many digital pins as possible. Adding some digital pin pads on the bottom of the board may be a possibility too :) . We would like both extra SPI / I2C / serial ports being broken out, some general GPIO pins, and maybe also the "high power driving" pins (the ones mentioned in section Pin Drive Strength here: https://learn.sparkfun.com/tutorials/designing-with-the-sparkfun-artemis ).

I was wondering if maybe @adamgarbo  has some feedback of his own too :) .

PaulZC, 2021-04-21:
Hi JR (@jerabaul29 ),
This is really valuable feedback - thank you. Tagging @nseidle so he is aware.
Do you think a MicroMod Global Tracker would be a good solution for you? This would allow you to select whichever processor is best for your needs. Artemis and ESP32 are both supported. It would look very similar to the [MicroMod Asset Tracker](https://www.sparkfun.com/products/17272).
Understood about the buck-boost power circuit - and low quiescent current. We can certainly look at that.
If you think of any more design requirements, please feel free to add them here.
Thanks again,
Paul

jerabaul29, 2021-04-21:
I think a solution like this may be very attractive.

A few more things I can think about (though this is not essential for us at the moment, these may be nice to have later on, and would make the board even more attractive / versatile for us):

- having a SD card reader would be great

- I wonder if having a dedicated EEPROM chip connected to the Artemis (I know it is possible to emulate EEPROM in RAM, but not sure how this survives changing between sketches...) would be a nice addition (and how to make sure it can be switched on off to save power)

- also wonder if it would be possible to add an external RAM chip extension (340kB is a bit short for some of our applications; we would be much better out with 8MB, like https://www.pjrc.com/store/psram.html ). Also wonder how this can be make switchable on off for low power :) .

- regarding IMU etc: I have had a lot of issues with the BNO08x and getting it to work with the Artemis, and I have heard that there are issues with the ICM-20948 too ( @adamgarbo ). I have been experimenting lately with another approach as a consequence: using some "pure accel / gyro / mag measurement" breakouts, and doing the Kalman filtering on the Artemis. For example, I am using this breakout for now https://www.adafruit.com/product/4517 , though I will use this one when I can, as it has higher performance: https://www.adafruit.com/product/4569 . The thing is, it looks like there is a great library for doing the data fusion: https://github.com/adafruit/Adafruit_AHRS . I have been doing some tests, things work beautifully so far (see https://github.com/jerabaul29/Artemis_MbedOS_recipes/blob/main/recipes/recipe_LSM6DS0X_and_LIS3MDL_AHRS/recipe_LSM6DS0X_and_LIS3MDL_AHRS.ino , and in particular:

https://github.com/jerabaul29/Artemis_MbedOS_recipes/blob/9d72a4a785daf1f0ffc25268efb51182703d3490/recipes/recipe_LSM6DS0X_and_LIS3MDL_AHRS/recipe_LSM6DS0X_and_LIS3M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

So I think that, if you want to integrate on the board the "best possible for medium price" equivalent (ie accel, gyro, magnetometer, if possible with "industrial" rating, like https://www.adafruit.com/product/4569 ), that may be a great idea. The advantages I see are: 1) it works well and is reliable 2) the user has full control, while there are libraries for doing all the work, 3) instead of using 15mA for an external chip with its own MCU, we can use a fraction of the Artemis MCU and pay virtually 0 cost in addition to the sensor itself (which is very low power, typically 1mA). Would be curious of what you think @adamgarbo :) . One thing about these 9-dof things: I wonder if they should be put on SPI instead of I2C for speed (from the observation that more of the Artemis is used for I2C communications than running the Kalman filter).

One more point: for me, a few dollars more or less is not a big deal, especially when there is an expensive component such as the Iridium modem. So, adding a few extras (buck-boost, SD, EEPROM, RAM, 9-dof measurements) at the cost of a bit of price increase is very attractive. From my employer the expensive thing is my working hours, so if I can cut on soldering time this is great :) .
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
adamgarbo, 2021-07-06:
Hi @a-schneider-fmi,

Would using batteries that are rated for cold temperatures not be a simpler solution? Heaters consume a significant amount of power.

For example, Energizer Lithium batteries are rated to -40°C (https://data.energizer.com/pdfs/l91.pdf) and Tadiran and Saft also make batteries specifically rated for extreme temperatures.

Cheers,
Adam

a-schneider-fmi, 2021-07-06:
In Arctic winter stratosphere with temperatures around -80°C we had failures with such batteries (I think it was Saft batteries if I recall correctly). After that we put heating to our devices. However, it would be better to regulate the heating with temperature measurements instead of heating all the time. It would be convenient if the tracker's temperature measurement can be used for that.

adamgarbo, 2021-07-06:
Hi Andreas,

Very interesting use case. Would love to see photos of your design. Tadiran does make an extended temperature series of battery suitable to -100°C, but the nominal discharge current is far below what is required of Iridium transmissions.  I hadn't realized your application was so extreme, so it definitely sounds like insulation and heating is the way to go.

Cheers,
Adam

a-schneider-fmi, 2021-07-07:
Hi Adam,
Currently we are in the process of replacing our old tracking system with one based on the AGT. The open source architecture has many advantages, such as easy customization, possibility to implement custom firmware features, open protocols, etc. Our new design is not finalized yet. In a first version we want to connect a custom PCB to the AGT by I2C to operate cutters, heating, etc.
Cheers
Andreas

a-schneider-fmi, 2021-07-08:
A feature that will probably be interesting for a wider range of users would be to support to call a user function when certain temperature values are exceeded, similar to alarms but with a user function instead of messages. We could then use this framework to implement our heating system, but it will be more flexible.

jerabaul29, 2021-09-16:
@PaulZC just FYI, our "AGT-based product" starts to be quite well tested, the components we went for (that could be relevant to consider for an AGT v2, so listing with comments about what we went for why):

- AGT of course :)
- Qwiic Power switch (though this could be avoided with more pins broken out, in particular if some of the high power pins get broken out; but with few pins broken out, this was the easiest way to turn the 9-dof on / off)
- Adafruit high accuracy 9-dof; this works flawlessly in our experience, has really low noise levels, and is much more reliable than the various "IMUs" I got my hand on, and the Adafruit AHRS library for performing Kalman filtering is able to run on the Artemis in real time, so this is in practice all the benefits of an IMU, at the cost of a 9-dof, with higher reliability, and much lower power consumption since the 9-dof is quite power effective, and the Artemis is it too :)  . We are using: https://www.adafruit.com/product/4569
- pololu 3.3V step up step down: https://www.pololu.com/product/2122 this way we do not need to worry too much if the battery voltage under "iridium communication load" drops a bit especially at low temperature; I am combining this with a supercap or two directly in parallel of the battery cells just for being on the safe side: Supercapacitor, 7.5 F, 5.4 V from AVX https://no.farnell.com/avx/scmt32d755srbb0/cap-7-5f-5-4v-20-super-cap-radial/dp/2856935

The main pain point we have left is the lack of pins broken out... So an "all the pins" version of the AGT (possibly with some 9-dof and 3.3V step up step down built in) would be amazing.

jerabaul29, 2021-09-16:
As a side note, the motivation for putting the supercap directly parallel to the battery, and not on the AGT as is planned for now, is that this way the supercap can help other components than "just" the iridium modem, if we get some other components with high transient (actually, in really low temperature, the GPS falls under this "draw quite a bit and likes the help of the supercap" category). The leakage current of the supercap is around 70uA from the datasheet, which is low enough for our purpose.

jerabaul29, 2021-09-17:
Also working on adding a '2 stage memory' to our project: a 4MB FRAM https://www.adafruit.com/product/4719 for being able to write fast / buffer data, and a SD card for being able now and then to write the contents of the FRAM to a larger non volatile memory. Think for us (and possibly everybody who need to log large amounts of data with low latency) this is a good fit :) .

jerabaul29, 2021-09-17:
(note: if the Artemis line of products could be updated to Ambiq 4, the extra FRAM would become in necessary).

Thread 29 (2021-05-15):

tracker suddenly failing; failing component? Failing solder? Other possible cause?

jerabaul29, 2021-05-15:
I have some AGTs doing some tests outside. One of them suddenly stopped to work after a couple of days and to transmit iridium messages.

After some debugging, I have reached the following conclusion:

- The code itself seems to work well; I uploaded the code on another AGT and it works fine
- To be on the safe side, I re-uploaded the code on the failing AGT, in the exact same configuration as the AGT that was working well above; still no success

I investigated in a bit more details the failure then:

- The failure is due to incapability to switch on the Iridium modem; I can actually see it, the 9603 power LED does not turn on
- I did a bit of serial debug analysis, and this got confirmed; the MCU does not manage to talk to the 9603 modem even after the supercap is charged and the driving pin is turned HIGH and everything (and I know this should work, as it works on the other AGT, while not on the failing one)
- I did one more test: shorting the 5V from the USB input into the power rail of the iridium modem (by feeding it on the left pin of the resistor upstream of the 9603N power LED); then the 9603 power LED fires up, and the AGT tracker works again fine...

So I think that there is some possibility that there is some form of hardware failure that prevents providing power to the iridium modem in my case. I see two main hypothesis:

- 1) the digital pin out of the Artemis driving the modem on is dead; I see no reason for this, the AGT was working and then suddenly stopped working, it was in a tight box outside, there was no possibility for shorting / power spike etc.

- 2) Somehow, a solder failed on the board. There are some temperature fluctuations outside of my home (maybe from +20 degrees C middle of day to a couple of - degrees at night these days). Is it possible that a solder somewhere on the PCB failed due to "temperature cycling", and that this broke some connection

Or any other idea what the cause can be?

- if you need to board to investigate I am willing to ship it to you
- we had a couple of inexplained failures during a deployment in the Arctic a few months ago, with AGTs suddenly stopping to work while testing on the deck of our boat; wondering if it could be some similar cause to this one?

Any more ideas / thoughts?

jerabaul29, 2021-05-15:
PS: the failure we had with at least one of the instruments on the boat was failure to talk to the GPS module; not sure what the other failures were.

PaulZC, 2021-05-16:
Hi JR,

If your AGT is inside an insulated box, I wonder if the temperature fluctuations are possibly larger than ~20 degrees? Repeated thermal cycling can certainly cause poor solder joints to weaken and fail.

Please check the Artemis digital pin 22 signal. If wonder if the joint under the Artemis has failed?

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

Unfortunately R14 is hidden by the modem. If you remove the modem, you will be able to probe the left end of R14, just to see if if goes high at the expected time. Or you could carefully scrape the solder resist off a small area of track on the rear of the board and probe there instead.

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

Let me know what you find.

Best wishes,
Paul

jerabaul29, 2021-08-02:
I was a bit busy but got the time to get back to this one today. Strangely, I tried the exact same thing, and it worked this time. Looks like there is some intermittent problem happening.

I think the most likely option is a cracked solder or something like this. I will not use this AGT for real world deployment, will just keep it home for testing, and report if I notice more weirdness.

We could either close or keep open this issue, as you like it best. Would be curious to have one issue of this kind open, so that if other users observer similar issues, they can report it.

PaulZC, 2021-08-02:
Hi JR,
Glad it is working again for you. It could be an intermittent solder joint.
Yes, please leave this issue open so we can see if anyone else has the same issue.
Best wishes,
Paul

jerabaul29, 2021-08-25:
A bit of updating here. I do have one AGT that is a really pain with intermittent issues, probably some bad soldering contacts, and one other that has had an issue now and then but mostly works fine, but I suspect the same. This is out of about 15 AGTs I have been spending time with. I am quite confident this is not a software issue, as some of the AGTs work like clocks.

I am a bit surprised by this relatively high "failure rate", I had not had such issues before. Of course I may just be unlucky, and / or other things (unlucky with a static electricity discharge or similar) may have happened. Still, a bit scaring when I want to use these in mission critical contexts, in an environment where there are quite large temperature fluctuations.

I was looking at the boards, thinking about their design, and wondering about the following. How "sound" / common / good or bad practice is it to have two large area PCBs with many soldering points between them being soldered on top of each other? This is more or less how the Artemis red "nail size" PCB is put on top of the main AGT PCB, right?

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

Just wondering, if this does is a potential point of weakness in the hardware robustness, any way future designs could see the Ambiq MCU and stuff around soldered directly on the main PCB, and / or some way during the manufacturing to make really sure that the nail size PCB gets really reliably soldered, without gas bubbles, weak solders that may crack with temperature fluctuations etc?

What is your opinion on this? I know quite little about hardware and industrial processes during manufacture, but curious to hear your thoughts :) .

tnn77, 2021-12-02:
Dear Sparkfun,

We have purchased several AGTs in the last year or so to work with @jerabaul29 's design.
We have had a couple of faulty QWIIC connectors and wish to report them.

**S/N 203756:**
the QWIIC connector simple came off the board as you can see in the picture. I actually don't know when this happened, but I don't recall treating the AGT in a rough manner. Nevertheless, we wish to use AGTs in Jean's ocean measuring device, usually deployed in harsh conditions, so the solder quality is a bit of a concern.

Note this was purchased a while ago, but did not come in use for months.

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

S/N 203767
Regarding this AGT, we used this straight away and noticed that the QWIIC port did not work. When we used the SDA and SCL pins, it worked. Visually, I cannot see anything wrong.

We'd be grateful if you could advise us to diagnose the problem.

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

Thank you.
Tak

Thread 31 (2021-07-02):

getting the DS18B20 to work with the AGT

jerabaul29, 2021-07-02:
Today I am struggling to get the DS18B20 to work with the Artemis boards. I have managed to get it to work with the RedBoard, and it seems that getting it to work is quite sensitive on the value of the pullup resistor, and that the value to pick depends on the pins. See:

https://github.com/sparkfun/Arduino_Apollo3/issues/409

I am trying to get it to work on the Artemis Global Tracker now. I am not having success so far.

What I am using:

- Artemis Global Tracker, being programmed as an "Artemis module" as usual for this board
- AGT GND to DS18B20 black
- AGT 3.3V to DS18B20 red
- AGT D4 to DS18B20 signal (also tried AGT D35)
- 4.7kOhm pullup between the DS18B20 red and signal

I am using the same kind of sketch I was successful with on the RedBoard (see under). I am not able to detect the DS18B20 (only getting some "No more addresses" prints, i.e. cannot find the thermometer).

Any idea what may cause that?

```
#include <OneWire.h>

// OneWire DS18S20, DS18B20, DS1822 Temperature Example
//
// http://www.pjrc.com/teensy/td_libs_OneWire.html
//
// The DallasTemperature library can do all this work for you!
// https://github.com/milesburton/Arduino-Temperature-Control-Library

OneWire  ds(4);  // on pin 10 (a 4.7K resistor is necessary)

void setup(void) {
  Serial.begin(9600);
}

void loop(void) {
  byte i;
  byte present = 0;
  byte type_s;
  byte data[12];
  byte addr[8];
  float celsius, fahrenheit;

  if ( !ds.search(addr)) {
    Serial.println("No more addresses.");
    Serial.println();
    ds.reset_search();
    delay(250);
    return;
  }

  Serial.print("ROM =");
  for( i = 0; i < 8; i++) {
    Serial.write(' ');
    Serial.print(addr[i], HEX);
  }

  if (OneWire::crc8(addr, 7) != addr[7]) {
      Serial.println("CRC is not valid!");
      return;
  }
  Serial.println();

  // the first ROM byte indicates which chip
  switch (addr[0]) {
    case 0x10:
      Serial.println("  Chip = DS18S20");  // or old DS1820
      type_s = 1;
      break;
    case 0x28:
      Serial.println("  Chip = DS18B20");
      type_s = 0;
      break;
    case 0x22:
      Serial.println("  Chip = DS1822");
      type_s = 0;
      break;
    default:
      Serial.println("Device is not a DS18x20 family device.");
      return;
  }

  ds.reset();
  ds.select(addr);
  ds.write(0x44, 1);        // start conversion, with parasite power on at the end

  delay(1000);     // maybe 750ms is enough, maybe not
  // we might do a ds.depower() here, but the reset will take care of it.

  present = ds.reset();
  ds.select(addr);
  ds.write(0xBE);         // Read Scratchpad

  Serial.print("  Data = ");
  Serial.print(present, HEX);
  Serial.print(" ");
  for ( i = 0; i < 9; i++) {           // we need 9 bytes
    data[i] = ds.read();
    Serial.print(data[i], HEX);
    Serial.print(" ");
  }
  Serial.print(" CRC=");
  Serial.print(OneWire::crc8(data, 8), HEX);
  Serial.println();

  // Convert the data to actual temperature
  // because the result is a 16 bit signed integer, it should
  // be stored to an "int16_t" type, which is always 16 bits
  // even when compiled on a 32 bit processor.
  int16_t raw = (data[1] << 8) | data[0];
  if (type_s) {
    raw = raw << 3; // 9 bit resolution default
    if (data[7] == 0x10) {
      // "count remain" gives full 12 bit resolution
      raw = (raw & 0xFFF0) + 12 - data[6];
    }
  } else {
    byte cfg = (data[4] & 0x60);
    // at lower res, the low bits are undefined, so let's zero them
    if (cfg == 0x00) raw = raw & ~7;  // 9 bit resolution, 93.75 ms
    else if (cfg == 0x20) raw = raw & ~3; // 10 bit res, 187.5 ms
    else if (cfg == 0x40) raw = raw & ~1; // 11 bit res, 375 ms
    //// default is 12 bit resolution, 750 ms conversion time
  }
  celsius = (float)raw / 16.0;
  fahrenheit = celsius * 1.8 + 32.0;
  Serial.print("  Temperature = ");
  Serial.print(celsius);
  Serial.print(" Celsius, ");
  Serial.print(fahrenheit);
  Serial.println(" Fahrenheit");
}
```

jerabaul29, 2021-07-02:
I tried for several hours on this, and in the end I gave up and grabbed a DS18B20 from another manufacturer - and that worked out of the box.

So it seems that some manufacturers sell low quality DS18B20. Weird, I bought the ones that work badly from Sparkfun. The ones from Adafruit seem to work nicely. Closing.

jerabaul29, 2021-07-02:
Actually, some more strange stuff:

- I have 1 DS18B20 sensor that works fine with the Artemis
- I have another DS18B20 that works fine with the Redboard, but no ways to get it to work with the Artems

Are there some pullups / pulldowns of some kind that I may not be aware of? I looked at the schematics but could not find any.

PaulZC, 2021-07-02:
Hi JR,
Please don't raise the same question in two places.
Closing in favour of [this issue](https://github.com/sparkfun/Arduino_Apollo3/issues/409).
Best wishes,
Paul

jerabaul29, 2021-07-02:
Well, actually I got it to work on the Artemis Reboard, but I do not manage to get the exact same sensor to work with the AGT. This is why I opened a new issue here: I wonder if this is AGT specific.

Closed 2021-07-02.

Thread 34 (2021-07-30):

AGT BLE Support - using v2.1 of the Apollo3 core

PaulZC, 2021-07-30:
I would like to use this issue to define how I should implement BLE on the AGT. As current or future users of the AGT, this is your chance to define how you want to be able to interact with the AGT over BLE.

Any new examples I write for the AGT, using v2.1 of the core, will use the [ArduinoBLE](https://www.arduino.cc/en/Reference/ArduinoBLE) library to provide BLE functionality.

The biggest question is: how do you want the features of the AGT to be mapped onto the services and characteristics of BLE?

Or, more simply, what you you want to be able to **do** using BLE on the AGT?

Will you be carrying the AGT with you, paired with your phone or laptop, and want to be able to use it as an Iridium modem for sending and receiving messages? Perhaps with a simple way of copying in or attaching the data from the GNSS and pressure/temperature sensor, but the main focus being free text which you type manually?

Or, do you want to be able to use an App or a Java-enabled web browser page to be able to configure the AGT before you deploy it? Think Example16 but where the configuration is done over BLE instead of - or as well as - using the configuration tool?

Or, the simplest option for me, is just to get the existing examples working with v2.1 of the core and not add any new BLE examples - leaving that up to you?

Without guidance, my plan will be to concentrate on:
- upgrading the examples so they work on v2.1 of the core
- when time permits, add an additional example to which adds _configuration_ via BLE to Example16

and not concentrate on any examples showing how the AGT could used as a phone/laptop accessory.

Over to you!

Best wishes,
Paul

jerabaul29, 2021-08-02:
My personal 2 cents: I am mostly interested in:

- being able to use bluetooth for configuration as you say (I guess setting some simple parameters, getting the parameters to double check them, etc)
- being able to use bluetooth to "check functionality and health". For example, when the AGT is embedded in a large oceanic buoy, and access is a bit inconvenient, would be great to be able to ask for a "heartbeat" that the thing is well and alive just before deployment
- being able to send some data in real time from the AGT to the receiving bluetooth device. For example, sending a few floats (heave, surge, sway, yaw, pitch, roll in my case) at a frequency of 10 Hz. That would be very convenient for a wide variety of "debugging" purposes of the final instrument
- similarly, being able to 1) send quite a bit of magnetometer data, 2) get back some soft and hard iron configuration value, in order to be able to perform fully "sealed calibration" of built-in magnetometer for some instruments based on the AGT. That would be really great, i.e. be able to do a careful magnetometer calibration in the "true, final" configuration including all components and magnetic disturbances

Another possible application would be, if possible (but that would require the possibility to have a "super, super low power mode"), to use the bluetooth as "on / off" switch between a super low power mode (where only bluetooth is available, maybe looking once a minute for a wake up signal or something like this and sleeping otherwise), and the "normal, working mode". Currently I use a reed switch for that (advantage: guarantee that 0 power consumption when turned off; disadvantage: yet a component to source, put in place, and something to test before deployment).

PaulZC, 2021-08-02:
Thanks JR,
A lot of what you are requesting depends on additional hardware and sensors - and is very application-specific. I'd like to concentrate on what you need from the AGT as-is - without extra bells and whistles attached. But I can certainly look at implementing a software switch of some kind to disable BLE functionality just before you deploy.
Please keep the ideas coming.
All the best,
Paul

jerabaul29, 2021-08-02:
I agree with you. Sorry, this may be a bit too specific, and the idea was never that you would implement all of this of course :) (should have been clearer :) ). What would be amazing from my side is if you could provide some building blocks / examples that make it easy for me to implement these points on my specific application.

I guess this would mean:

- data in both directions of the BLU, making sure "reasonable data rates" can be consistently achieved
- a "super low power mode" checking periodically through the BLU if it should wake up to a higher power mode

razvandragomirescu, 2021-08-02:
For our particular use case, we simply need to send and receive binary messages, nothing else. We are not (currently) using the GPS or any sensors on board the AGT. We have these fixed (kiosk-like) terminals that are based on Android (so have BLE on board) and normally communicate back to base using GSM or 3G, but some locations are without terrestrial coverage while others have intermittent coverage (moving boats for instance) or could lose connectivity in case of natural disasters.

We can code our own application on the Arduino side because it may retry sending by itself multiple times or receive and store incoming messages even when the Android terminal is disconnected.

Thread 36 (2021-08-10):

Examples stopped working after update to 2.1.0

razvandragomirescu, 2021-08-10:
The new examples compile fine but fail to start the modem. The output on the serial monitor is

Enabling the supercapacitor charger...
Supercapacitors charged!
Enabling 9603N power...
Starting modem...

It appears to freeze there. I got no errors when compiling or uploading. Any way to debug this?

razvandragomirescu, 2021-08-10:
The old examples still work fine (on the same hardware) with version 1.2.3, so it's not a hardware issue.

PaulZC, 2021-08-10:
Hi @razvandragomirescu ,
Do you see the same behavior on all of the Iridium examples? Do the simple examples like Example7 work?
Best wishes,
Paul

PaulZC, 2021-08-10:
Also, please make sure you have "RedBoard Artemis ATP" selected as the board type. ("Artemis Module" will not work.)

PaulZC, 2021-08-10:
To enable debug messages for the Iridium serial communication, change the ```false``` in this line to ```true```:

https://github.com/sparkfunX/Artemis_Global_Tracker/blob/8094e148241947c6812ac86424d9a6165f34f049/Software/examples/Example7_GetIMEI/Example7_GetIMEI.ino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

PaulZC, 2021-08-10:
Hi @razvandragomirescu ,

If you have time, please do try uploading one of the new binaries onto your board. Details are [here](https://github.com/sparkfunX/Artemis_Global_Tracker/tree/main/binaries). That way we can rule out the way the code is being compiled.

If you run the Example7 binary, you should see:

```
Artemis Global Tracker
Example: Get IMEI

Please check that the Serial Monitor is set to 115200 Baud
and that the line ending is set to Newline.
Then click Send to start the example.

Enabling the supercapacitor charger...
Supercapacitors charged!
Enabling 9603N power...
Starting modem...
IMEI is 3004-------4090.
Putting the 9603N to sleep.
Disabling 9603N power...
Disabling the supercapacitor charger...
Done!
```

Running Example7 with ```DIAGNOSTICS``` set to ```true``` should produce:

```
Artemis Global Tracker
Example: Get IMEI

Please check that the Serial Monitor is set to 115200 Baud
and that the line ending is set to Newline.
Then click Send to start the example.

Enabling the supercapacitor charger...
Supercapacitors charged!
Enabling 9603N power...
Starting modem...
Calling internalBegin
Powering on modem...
>> AT

Waiting for response OK

<< AT

OK
>> ATE1

Waiting for response OK

<< ATE1

OK
>> AT&D0

Waiting for response OK

<< AT&D0

OK
>> AT&K0

Waiting for response OK

<< AT&K0

OK
Ring alerts are enabled.
>> AT+SBDMTA=1

Waiting for response OK

<< AT+SBDMTA=1

OK
>> AT+CGMR

Waiting for response OK

<< AT+CGMR

Call Processor Version: TA16005

Modem DSP Version: 1.7 svn: 2358

DBB Version: 0x0001 (ASIC)

RFA Version: 0x0007 (SRFA2)

NVM Version: KVS

Hardware Version: BOOT07d2/9603NrevDE/04/RAW0c

BOOT Version: TA16005 (rev exported)

OK
Firmware version is TA16005
MSSTM workaround is NOT enforced.
InternalBegin: success!
>> AT+CGSN

Waiting for response OK

<< AT+CGSN

3004-------4090

OK
IMEI is 3004-------4090.
Putting the 9603N to sleep.
Powering off modem...
Disabling 9603N power...
Disabling the supercapacitor charger...
Done!
```

Please also check that the red **9603N POWER** LED turns on when you see the "Enabling 9603N power" appear.

If you want to debug further, you can try probing on the TX1 test point on the rear of the PCB. You should see the serial AT commands being sent to the modem at 19200 Baud (3.3V). The replies - if any - will appear on RX1.

Best wishes,
Paul

PaulZC, 2021-08-11:
Hi @razvandragomirescu ,

Thank you for investigating this.
Just to be clear, have you tried the Example7 binary? And does that freeze at the same place?
(I'm trying to rule out an issue with re-starting Serial1 after the Artemis has been in deep sleep. Example7 does not use deep sleep.)

Thanks again,
Paul

razvandragomirescu, 2021-08-11:
BTW, with DIAGNOSTICS=true, it stops at

Calling internalBegin
Powering on modem...

I never get that "AT" command sent to the modem, it never displays that, it just freezes at "Powering on modem...".

PaulZC, 2021-08-11:
Thanks again for the diagnostics.

Wow, OK. This is a head-scratcher...

Best guess, some badness is happening when the new code tries to enable the modem via the 'sleep' pin. Why? I did have to change the ```gnssON``` and ```gnssOFF``` functions in v2.0 because the power glitch issue I fixed months ago on the GNSS enable pin came back again. I wonder if this issue only appear on some pins on some chips. I will try and send you a new binary to try in the next day or two. (It means hacking the IridiumSBDi2c library as the [control of the 'sleepPin'](https://github.com/sparkfun/SparkFun_IridiumSBD_I2C_Arduino_Library/blob/034ccf34d9fb9f3b10dd9c173518f000d0481ad7/src/IridiumSBD.cpp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) is embedded in there.)

Thank you for your patience.

razvandragomirescu, 2021-08-12:
I've just installed and run the binary for the iridiumSleepTest, result is below:

Artemis Global Tracker
Example: Get IMEI

Please check that the Serial Monitor is set to 115200 Baud
and that the line ending is set to Newline.
Then click Send to start the example.

Enabling the supercapacitor charger...
Supercapacitors charged!
Enabling 9603N power...
Starting modem...
Calling internalBegin
custom configureSleepPin: sleepPin configured
Powering on modem...

Still appears to freeze on "Powering on modem". Would it help if I mailed you the AGT unit I'm testing on (if you can't reproduce it on your devices)?

PaulZC, 2021-08-12:
Hi @razvandragomirescu ,

(Wow - that was fast! I was just typing a message to you but you beat me to it!)

OK. That's very interesting. The code is executing the custom ```configureSleepPin``` because we see the ```custom configureSleepPin: sleepPin configured``` message.

https://github.com/sparkfun/SparkFun_IridiumSBD_I2C_Arduino_Library/blob/4652dc95da1e2f7425a4005bbe88dd29f3889591/src/IridiumSBD.cpp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

Then we see the ```Powering on modem...``` message:

https://github.com/sparkfun/SparkFun_IridiumSBD_I2C_Arduino_Library/blob/4652dc95da1e2f7425a4005bbe88dd29f3889591/src/IridiumSBD.cpp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

But it must be failing in the custom ```setSleepPin``` function - or just after it - because we do not see the ```custom setSleepPin: sleepPin set``` message.

I'm based in the UK. If you return your board to SF in Boulder, it will get to me but it will take a while. If I'm not trying your patience too much, can we try a couple more custom binaries first? I'd like to understand exactly where the code is failing. I'll upload another binary in a few minutes.

Best wishes,
Paul

PaulZC, 2021-08-13:
Hi @razvandragomirescu ,

Thank you for trying the new code. It is clear that the test code is crashing when the tri-state pin is set to an output:

https://github.com/sparkfunX/Artemis_Global_Tracker/blob/df54d12fc1fb02c9f4aba7c07be63f8db4589229/Software/examples/AGT_iridiumSleep_Test/AGT_iridiumSleep_Test.ino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

The crash is actually happening during the 10ms delay after that line.
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
razvandragomirescu, 2021-08-13:
I've just tried to update the bootloader and reuploaded the test, it behaves exactly the same way as before. I've bought my AGT from Distrelec in Europe. Can you email me on the address in my Github profile please if you need details (or give me an address to send them to)? Thank you!

a-schneider-fmi, 2021-08-17:
Since the update to version 2, I experience another issue which may or may not be related: the tracker seems not to wake from deep sleep after 2 messages have been sent. From the configuration tool, I see the following messages:
```
[...]
>>> Message sent! <<<
Clearing the MO buffer.
The number of messages in the MT queue is: 0
Putting the 9603N to sleep.
Getting ready to put the Apollo3 into deep sleep...
Disabling 9603N power...
Disabling the supercapacitor charger...
Powering down the GNSS...
Going into deep sleep until next WAKEINT (60 seconds).
```
And then it hangs. This happens with several TXINT settings (I tried 2 minutes, 5 minutes, 10 minutes).

I have tested example 12 to debug. It seems to work, at least it runs for more than half an hour. Do you have any suggestion how to investigate further?

PaulZC, 2021-08-17:
Hi Andreas (@a-schneider-fmi ),

I don't think this is the same issue... Let's discuss it separately in #38.

Best wishes,
Paul

a-schneider-fmi, 2021-08-17:
I made some more tests with the tracker with different settings, and after some settings change it suddenly works again, even when changing the settings back to what they have been before. I have no idea what is different.

PaulZC, 2021-08-24:
Hi Andreas (@a-schneider-fmi ) & Razvan (@razvandragomirescu ),

I now suspect you are both seeing the same issue.

I confirmed this morning that holding the Serial1 RX pin low can cause the Artemis to hang - but only with v2.1 of the Apollo3 core. Details are here: https://github.com/sparkfun/Arduino_Apollo3/issues/423

When the Iridium modem is powered off - or possibly when it is first powered on - there is a good chance it holds the RX pin low causing the code hang.

I may be able to work around this by changing the code to make sure that Serial1 is only started once the modem is fully powered on. I will of course keep you both informed.

Sincere apologies for the inconvenience,
Paul

razvandragomirescu, 2021-08-24:
@PaulZC should I still return the unit to Sparkfun or is this solvable in software? I haven't shipped mine back yet, I was just about to call FEDEX.

PaulZC, 2021-08-24:
Hi Razvan,

It _may_ be possible to solve this with the AGT software. I'm not certain yet if I can correct this in the AGT code or whether it needs to be corrected within the Apollo3 core. I will try and let you know if a solution in the AGT code is possible as soon as possible. Perhaps you could delay calling FedEx until then?

Very best wishes,
Paul

jerabaul29, 2021-08-24:
Following all these discussions with much interest, many thanks for your efforts making this whole environment better :) .

A small note to @razvandragomirescu : if you do not really NEED the core v2, have you considered using the core v1 for production for now? I am still sticking to the core v1 for my use, the only thing I miss is the bluetooth, all other stuff is working nicely. The core v1 has got really quite robust. I have deployed AGTs in the Arctic in February on drift ice based on the core v1, and my instruments are still working today, 7 months later. I had never had such success with deploying instrumentation in the Arctic before. So IMHO the core v1 is definitely production ready :) .

Still looking forward to a core v2 production ready though, many thanks @PaulZC for all your efforts :) .

PaulZC, 2021-08-25:
Hi @razvandragomirescu / @a-schneider-fmi ,

Good news! I'm 99% confident I have a solution for this. I was having difficulty understanding why Example7 was failing for Razvan, but I do now understand why. I should be able to release updated examples late today / early tomorrow.

Thank you for your patience.

Very best wishes,
Paul

razvandragomirescu, 2021-08-31:
Unit shipped back to Sparkfun earlier today, I hope it helps @PaulZC .

PaulZC, 2021-08-31:
Thank you Razvan. It will take a few days to reach me. I will update you on what I discover as soon as I have the board.
Best wishes,
Paul

PaulZC, 2021-09-24:
Hi Razvan (@razvandragomirescu ),
As we discussed yesterday, commit c6f3dbc does resolve this issue.
Thank you again for all your help.
Closing...!
Very best wishes,
Paul

Closed 2021-09-24.

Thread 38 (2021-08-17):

Example 16 not waking from deep sleep correctly after upgrade to v2.1

PaulZC, 2021-08-17:
Original issue was raised by @a-schneider-fmi in #36:

Since the update to version 2, I experience another issue which may or may not be related: the tracker seems not to wake from deep sleep after 2 messages have been sent. From the configuration tool, I see the following messages:
```
[...]
>>> Message sent! <<<
Clearing the MO buffer.
The number of messages in the MT queue is: 0
Putting the 9603N to sleep.
Getting ready to put the Apollo3 into deep sleep...
Disabling 9603N power...
Disabling the supercapacitor charger...
Powering down the GNSS...
Going into deep sleep until next WAKEINT (60 seconds).
```
And then it hangs. This happens with several TXINT settings (I tried 2 minutes, 5 minutes, 10 minutes).

I have tested example 12 to debug. It seems to work, at least it runs for more than half an hour. Do you have any suggestion how to investigate further?

a-schneider-fmi, 2021-08-17:
I made some more tests with the tracker with different settings, and after some settings change it suddenly works again, even when changing the settings back to what they have been before. I have no idea what is different.

PaulZC, 2021-08-17:
Hi Andreas,

Restoring the Artemis peripherals and pins to full function after deep sleep is a _lot_ more complex in v2.1 than it was with v1.2 of the core. Getting that part of the code right on OpenLog Artemis took a lot of effort.

It will be a question of making sure that the AGT deep sleep and wake code is exactly the same as the OpenLog Artemis code.

Example12 is much simpler and doesn't have to worry about restoring (e.g.) Serial1, agtWire and all the pins and interrupts to full functionality after deep sleep.

I will try and investigate this when I get some 'spare' time. (It is in short supply at the moment! ;-) )

Meanwhile if you discover any more clues, please report them here.

Very best wishes,
Paul

a-schneider-fmi, 2021-08-18:
This morning a made another test with the same configuration that worked yesterday evening (i.e. no changes, just plugged the device to power), and it stopped after the first message.

PaulZC, 2021-08-18:
Hi Andreas,
OK - thank you. I will investigate this as soon as I can.
Very best wishes,
Paul

a-schneider-fmi, 2021-08-20:
To test more, I tried to skip the deep sleep phase by adding the following lines in case zzz, line 2251 (i.e. after the modem is powered down):
```
      // TEST
      Serial.print(F("Delaying WAKEINT ("));
      Serial.print(wake_int);
      Serial.println(F(" seconds)."));
      delay(wake_int*1000);
      loop_step = loop_init;
      break; // TEST
```
Have I missed something? Now it hangs when reading the PHT sensor after sending two messages.
```
Transmitting message...
>>> Message sent! <<<
Clearing the MO buffer.
The number of messages in the MT queue is: 0
Putting the 9603N to sleep.
Getting ready to put the Apollo3 into deep sleep...
Disabling 9603N power...
Disabling the supercapacitor charger...
Delaying WAKEINT (60 seconds).

Artemis Global Tracker
Software Version: 2.0

Ready to accept configuration settings via Serial...

Getting the PHT readings...
*** Could not detect the MS8607 sensor. Trying again... ***
Pressure (mbar): 973
Temperature (C * 10^-2): 1980
Humidity (%RH * 10^-2): 5703
Getting ready to put the Apollo3 into deep sleep...
Disabling 9603N power...
Disabling the supercapacitor charger...
Delaying WAKEINT (60 seconds).

Artemis Global Tracker
Software Version: 2.0

Ready to accept configuration settings via Serial...

Getting the PHT readings...
Pressure (mbar): 973
Temperature (C * 10^-2): 1879
Humidity (%RH * 10^-2): 6014
Getting ready to put the Apollo3 into deep sleep...
Disabling 9603N power...
Disabling the supercapacitor charger...
Delaying WAKEINT (60 seconds).

Artemis Global Tracker
Software Version: 2.0

Ready to accept configuration settings via Serial...

Getting the PHT readings...
Pressure (mbar): 973
Temperature (C * 10^-2): 1784
Humidity (%RH * 10^-2): 6414
Getting ready to put the Apollo3 into deep sleep...
Disabling 9603N power...
Disabling the supercapacitor charger...
Delaying WAKEINT (60 seconds).

Artemis Global Tracker
Software Version: 2.0

Ready to accept configuration settings via Serial...

Getting the PHT readings...
```

PaulZC, 2021-08-20:
Hi Andreas,

Thank you for investigating this.

If you have time, it would be good to understand exactly where your code is hanging. Could you please try adding this line in **many** places in the ```read_pressure``` case statement:

```
Serial.println(F("HERE")); Serial.flush();
```

The ```flush``` is important as it prevents the code from moving on until the ```println``` is complete. That way you can tell that the code hung in the preceding line.

The background to this is that v2.1 of the core does things differently compared to v1.2. The Ambiq Micro low-level calls to the Apollo3 Blue hardware are wrapped up in the Mbed OS functions, and things happen differently. The point at which the pins are configured for I2C / SPI is different for example. Maybe there is a gremlin in making repeated calls to ```agtWire.begin()```. You can follow some of our detective work [here](https://github.com/sparkfun/Arduino_Apollo3/issues/412).

Very best wishes,
Paul

a-schneider-fmi, 2021-08-20:
I have inserted several Serial.println lines. In my tests, it hung around the line
```
barometricSensorOK = barometricSensor.begin(agtWire); // Begin the PHT sensor
```
that is either the println before that line (i.e. after `setAGTWirePullups(1);`) or directly after this line was the last to be actually printed out.

PaulZC, 2021-08-20:
Excellent - thank you Andreas,
If you have time, it would be very interesting to test this in its simplest form. Please see below for the code.
It would also be interesting to see if updating your bootloader makes any difference:
Please try running the Artemis Firmware Upload GUI and click the "Update Bootloader" button
https://github.com/sparkfun/Artemis-Firmware-Upload-GUI
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
PaulZC, 2021-09-06:
Thank you Andreas,
I'm struggling to think why this issue with v2.1 is temperature-dependent. I have ordered a small freezer so I can try to replicate. Maybe the modem takes longer to start when cold and so holds the RX pin low for longer? Very strange!
Thank you again for your support and patience,
Paul

a-schneider-fmi, 2021-09-06:
Maybe it's not directly caused be the low temperature, but the low temperature is correlated to the effect causing it.

PaulZC, 2021-09-06:
Just to document how things are with the board I have here:

Running Example21 at room temperature: the yellow trace is the EXT_PWR power rail for the Iridium modem (5.3V switched by U3 and Q1); the purple trace is the Iridium modem RX1 line (RX(OUT)). From initial power-up: note that the RX1 line is already high - it goes high as soon as the code starts; note also the small glitch on the RX1 line 1.0s after the 5.3V rail goes high [coinciding with the modem.begin](https://github.com/sparkfunX/Artemis_Global_Tracker/blob/ac7347ba55b67a6c8594597e716b2134777239b8/Software/examples/Example21_IridiumSerialAndPowerTest/Example21_Iri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); note also that serial characters are seen on RX1 [0.5s after modem.begin is called](https://github.com/sparkfun/SparkFun_IridiumSBD_I2C_Arduino_Library/blob/5f8ea893907ba39e85d665abedc35ac09eb3567d/src/IridiumSBD.cpp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)

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

On the second and subsequent loop: note that RX1 is low ([disabled](https://github.com/sparkfunX/Artemis_Global_Tracker/blob/ac7347ba55b67a6c8594597e716b2134777239b8/Software/examples/Example21_IridiumSerialAndPowerTest/Example21_Iri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)) until the modem.begin

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

Here the yellow trace is ARTEMIS_D17 (modem ON/!OFF). First loop:

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

Second and subsequent loops:

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

PaulZC, 2021-09-06:
Thinking more about the glitch on RX1 on the first loop. Is the glitch wide enough to cause the Artemis to hang?

Here it is with a shorter timebase: yellow is ARTEMIS_D17, purple is RX1

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

Inconclusive... It is ~500us wide and does not go fully low.

A thought experiment...

The Artemis could hang: IF Serial1 is enabled in v2.1 of the core as soon as code execution starts, and IF the glitch on RX1 corresponds to [>9.5 bit periods](https://github.com/sparkfun/Arduino_Apollo3/issues/423#issuecomment-904375994) at whatever the default baud rate happens to be.

JR (@jerabaul29) reported similar issues in [Apollo3 Issue 349](https://github.com/sparkfun/Arduino_Apollo3/issues/349#issuecomment-778056222)

If the width or depth of the glitch is temperature-dependent, that could explain this issue.

(More to follow shortly.)

jerabaul29, 2021-09-06:
That was interesting...

I am curious of why these issues happen with the core v2 but not the core v1. Following several issues with the core v2 (including the one you linked to), I decided to stick to the core v1 instead, and things work like a charm then...

PaulZC, 2021-09-06:
Hi Andreas (@a-schneider-fmi ),

It is easy to test if the glitch is the cause of this issue, by making sure that the RX1 pin is disabled before calling ```modem.begin``` for the first time.

If I add:

```
am_hal_gpio_pinconfig(PinName(D25), g_AM_HAL_GPIO_DISABLE); // Disable the RX1 pin (until modem.begin)
```

to the setup code in Example21:

```
void setup()
{
  pinMode(LED, OUTPUT); // Make the LED pin an output

  gnssOFF(); // Disable power for the GNSS
  pinMode(geofencePin, INPUT); // Configure the geofence pin as an input

  pinMode(iridiumPwrEN, OUTPUT); // Configure the Iridium Power Pin (connected to the ADM4210 ON pin)
  digitalWrite(iridiumPwrEN, LOW); // Disable Iridium Power (HIGH = enable; LOW = disable)
  pinMode(superCapChgEN, OUTPUT); // Configure the super capacitor charger enable pin (connected to LTC3225 !SHDN)
  digitalWrite(superCapChgEN, LOW); // Disable the super capacitor charger (HIGH = enable; LOW = disable)
  pinMode(iridiumSleep, OUTPUT); // Iridium 9603N On/Off (Sleep) pin
  digitalWrite(iridiumSleep, LOW); // Put the Iridium 9603N to sleep (HIGH = on; LOW = off/sleep)
  pinMode(iridiumRI, INPUT); // Configure the Iridium Ring Indicator as an input
  pinMode(iridiumNA, INPUT); // Configure the Iridium Network Available as an input
  pinMode(superCapPGOOD, INPUT); // Configure the super capacitor charger PGOOD input

  am_hal_gpio_pinconfig(PinName(D25), g_AM_HAL_GPIO_DISABLE); // Disable the RX1 pin (until modem.begin)

  // Start the console serial port
```

then I can guarantee RX1 is disabled (low) the first time loop is executed:

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

The slow rise of RX1 is interesting. It implies that the circuit inside the Iridium modem which drives the RX(OUT) pin has a slow response when ON/!OFF is pulled high. Perhaps while the internal microcontroller
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

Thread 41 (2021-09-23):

additional pins on "v1.2"

jerabaul29, 2021-09-23:
Hi @PaulZC ,

Sorry for "insisting" a bit on this, but we have a real pain problem with getting enough pins available for putting some weather measurement sensors, wind anemometers, etc, on some of our designs. We could of course add an Artemis Nano over I2C to have more pins, but this is more costs, yet a board to put in our design, more programming to do etc.

I was wondering: any hope that you could set up a "v1.2" rather than a v2, that would just be the present v1, but with more pins broken out? Looking at my board, I wonder if there would be any more space for breaking pins (for example, 1 more under the VBus pins, a bunch of them in place of where the "SparkX" mention is the the top side of the board, a couple "North East" from the GPS chip, a bunch at the "North" of the board close to the supercaps. Getting between 5 to 10 extra pins would make a huge difference for us :) .

PaulZC, 2021-09-24:
Hi JR,
Request noted! Thank you for asking nicely. My colleague has managed to squeeze in 8 extra pins around the NW corner (4 West, 4 North), plus one more below VBUS. The design is still being reviewed, we will share the new pin numbers and positions as soon as we can.
Have a great weekend,
Paul

jerabaul29, 2021-09-25:
Yippiii, this is excellent news, many thanks for taking our feedback into account :) . 9 extra pins sounds amazing (you know how users are, "the more the better" :) ).

@jvoermans FYI, this should solve the issues you had, right? :) .

Hope the testing is successful and the next production runs has the extra pins :) . Many thanks again, will be eager to hear about how this goes further and when the boards with extra pins hit the market :) .

jerabaul29, 2021-09-27:
A last point I was thinking about: which pins did you decide to route? Can you provide at least one or two of the "power switch pins" (maybe one high side and one low side?) mentioned in the datasheet "Absolute Maximum Rating"? That would be very convenient to be able to switch on / off some "intermediate" loads, and cut the need for extra switches / transistors / breakouts such as the qwiic switch.

jerabaul29, 2021-09-27:
(for reference: https://cdn.sparkfun.com/assets/d/e/8/b/4/Apollo3_Blue_MCU_Data_Sheet_v0_12_1_rZ9Akgo.pdf#G24.7640541 ).

lewispg228, 2021-09-27:
Hi @jerabaul29 ,
I have been working on the revision to this design. Thanks for all your input on this!

It was pretty tight, but I was able to nudge some stuff and breakout at least one low-side power switch pin (D37) right below VBUS. The other 8 GPIO broken out in the NW corner are the following: AD32, D43, D42, AD31, AD29, AD11, D15, AD12.

Thanks again for your feedback!
Pete

jerabaul29, 2021-09-27:
Many thanks, that sounds excellent, it will make a huge improvement for us :) .

Then looking forward to these boards on the SF online shop :) . Feel free to close this issue, all sounds good to me :) .

jerabaul29, 2021-09-27:
PS: I am ordering a bunch of AGTs together with a colleague, and we got to hear that there are AGTs in production or soon to be. Will these be v1.2 (would be amazing :) ), or v1.1?

lewispg228, 2021-09-29:
Hi @jerabaul29 ,
The current AGT boards are being built in SparkX, and so they are the version, "X10". (this is what I believe you are referring to as "v1.1".

The newer version, that will include the changes discussed here, will be "v10". And they will be red colored PCBs. You can always check the bottom copper for the version number.

Sorry if our versioning system may seem confusing :) Everything from SparkX starts with an "X", and then if/when the product transitions to a SparkFun product (Red PCBs), then the versions start with a "v", and it usually starts with "v10" as it is the first version built by SparkFun.

We have "v10" red PCBs on order, and we are cranking on all the other stuff involved (test jigs/documentation/arduino-libraries/ERP-work/purchasing-parts). Sorry I can't give you a firm date, but I assure you it will be going live ASAP :)

Again, thanks for all your feedback - and ORDERS!

Cheers,
Pete

jerabaul29, 2021-09-29:
That sounds amazing :) No worries at all, this is very clear, makes a lot of sense, and we are looking forward to it :) .

A small tips: really hope that you produce a large chunk of these. As you maybe know, we already have 8 in backorders. We also got 2 "small fundings" in addition, one for around 15kUSD, one for around 20kUSD, and we will use these all for building AGT-based sea ice drifters - so you can do the math, about half the funding goes to buying AGTs, the other half goes to the components around, batteries, etc :) . We hope for some larger fundings for next year.

jerabaul29, 2021-09-29:
PS: I will build a "master PCB" to host the AGTv10, and make it easy to add the components I use, such as the 9dof I use (this one, if you start producing a clone would be amazing: https://www.adafruit.com/product/4569 so that I do not need to order for plenty of different suppliers), pololu step up step down converter 3.3V (same, annoying to order from different sources, having something like https://www.pololu.com/product/2122 it would be amazing), Qwiic Switch, and some extra stuff. If you are able to release a CAD file (ideally KiCAD, that's what we like best :) ) for the AGTv10 so that I can use it as a "shield fingerprint" even if it is before it gets available on the webshop, would be amazing, because then I can order my "master PCBs" asap so that I can start testing as soon as the AGTv10s get available :) .

lewispg228, 2021-11-24:
Hey @jerabaul29 ,
Perhaps this would be a suitable SparkFun option for your 3.3V buck/boost:

https://www.sparkfun.com/products/15208

I know it's a little bit larger, but it is pretty comparable in terms of specs.

Also, maybe one of our 9DOF offerings would work for you. Is there a specific spec/range/rate that you really need from the ISM330DHCX + LIS3MDL combo?

https://www.sparkfun.com/products/15335
https://www.sparkfun.com/products/13284
https://www.sparkfun.com/products/13944

Hope this helps,
Cheers,
Pete

jerabaul29, 2021-11-24:
Hi @lewispg228 ,

Many thanks for your message :) .

A few thoughts:

- I am actually quite dependent on the slightly larger power input range of the pololu (works from 2.7V). It is crazy how much temperatures of -40C can impact batteries, and I am pretty sure that voltage goes down to 2.8-2.9V with the batteries I use at the peak of Iridium transmission. Also, it is actually quite nice to have a fixed 3.3V output when building series of 20 or so instruments, as this avoids the risks of mishaps / mis configuration of buttons etc,  just one less thing that can go wrong... So I think for now I will stick to https://www.pololu.com/product/2122 'unfortunately', but if SF comes with a similar or better design with fixed 3.3V out and input from around 2.7 to 12V, I will happily change to SF for simplifying my supply chain :) .
- similarly for the 9dof, I really want to avoid 'all in 1 IMU solutions', I had far too much headaches with the BNO08x to give these one more chance. About the ICM, some colleagues at another Institute were unfortunately not too impressed with the noise level either. Regarding the 9dof you show, unfortunately these have no built in temperature compensation. This is, together with lower noise, the killer features of the ISM330DHCX + LIS3MDL that I need. For example the ISM330DHCX + LIS3MDL has noise density of 60 to 100 ug/sqrt(Hz), Vs not specified in the datasheet of the LSMDS1. Adafruit did some noise comparisons on the gyros, and the LSMDS1 had about 4 time more noise than the ISM330DHCX https://learn.adafruit.com/adafruit-sensorlab-gyroscope-calibration/comparing-gyroscopes . All in all, the ISM330DHCX is a quite different level of performance. I do need this full level of performance in my application. So if you produce something similar I would go for it rather than Adafruit - simpler sourcing for me - , if you can find some even better performance 9dof that is a nice bonus (I could go to 30 or 40 USD without too much pain I think :) ), but I need something at least as good, if not better, than the ISM330DHCX, and with temperature compensation built it :) .

If you start producing / selling this kind of breakouts some day that would be awesome :) .

lewispg228, 2021-11-24:
Hey @jerabaul29 ,
Thanks for this info! We will definitely look more into the ISM330DHCX + LIS3MDL combo.

I did a little more digging about the buck/boost, and (although I'm not 100% sure yet, without testing) it looks like our board can actually do 2V-16V on the input. We used the TPS63070, and the datasheet clearly states 2-16V. I'm not sure why our documentation shows only 3-16V. It may have been to "play it safe", but I will look into this more next week and do some testing. What kind of current do you usually pull for your system?

Also, for reference, the Pololu board is using a similar model of the IC; it uses the TPS63060, which in it's datasheet, shows 2.5-12V. So that makes sense why they might advertise 2.7V to 11.8V.

https://www.ti.com/lit/ds/symlink/tps63070.pdf
https://www.ti.com/lit/ds/symlink/tps63060.pdf

jerabaul29, 2021-11-24:
Ok, many thanks for the infos :) . Let me know how the tests go :) .

jerabaul29, 2021-11-24:
PS: max 0.75 Amp, likely 0.5 Amp.

jerabaul29, 2022-02-01:
Many thanks for the addition of the extra pins on the new, "red" AGT :) . Closing.

Closed 2022-02-01.

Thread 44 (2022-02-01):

Link to the repo of the new AGT "red" and mention that this is deprecated?

jerabaul29, 2022-02-01:
Would it be possible to i) explain that this was the "prototype" AGT, and that it has been replaced by the "AGT gone red", and ii) link to the repo of the new AGT "red" at https://github.com/sparkfun/SparkFun_Artemis_Global_Tracker , and maybe mark this repo as outdated or something like this? :) . That would be very convenient for avoiding that people get confused :) .

PaulZC, 2022-02-04:
Hi JR,

OK. Done.

To quote Douglas Adams: "So long and thanks for all the fish"!

All the best,
Paul

Closed 2022-02-04.

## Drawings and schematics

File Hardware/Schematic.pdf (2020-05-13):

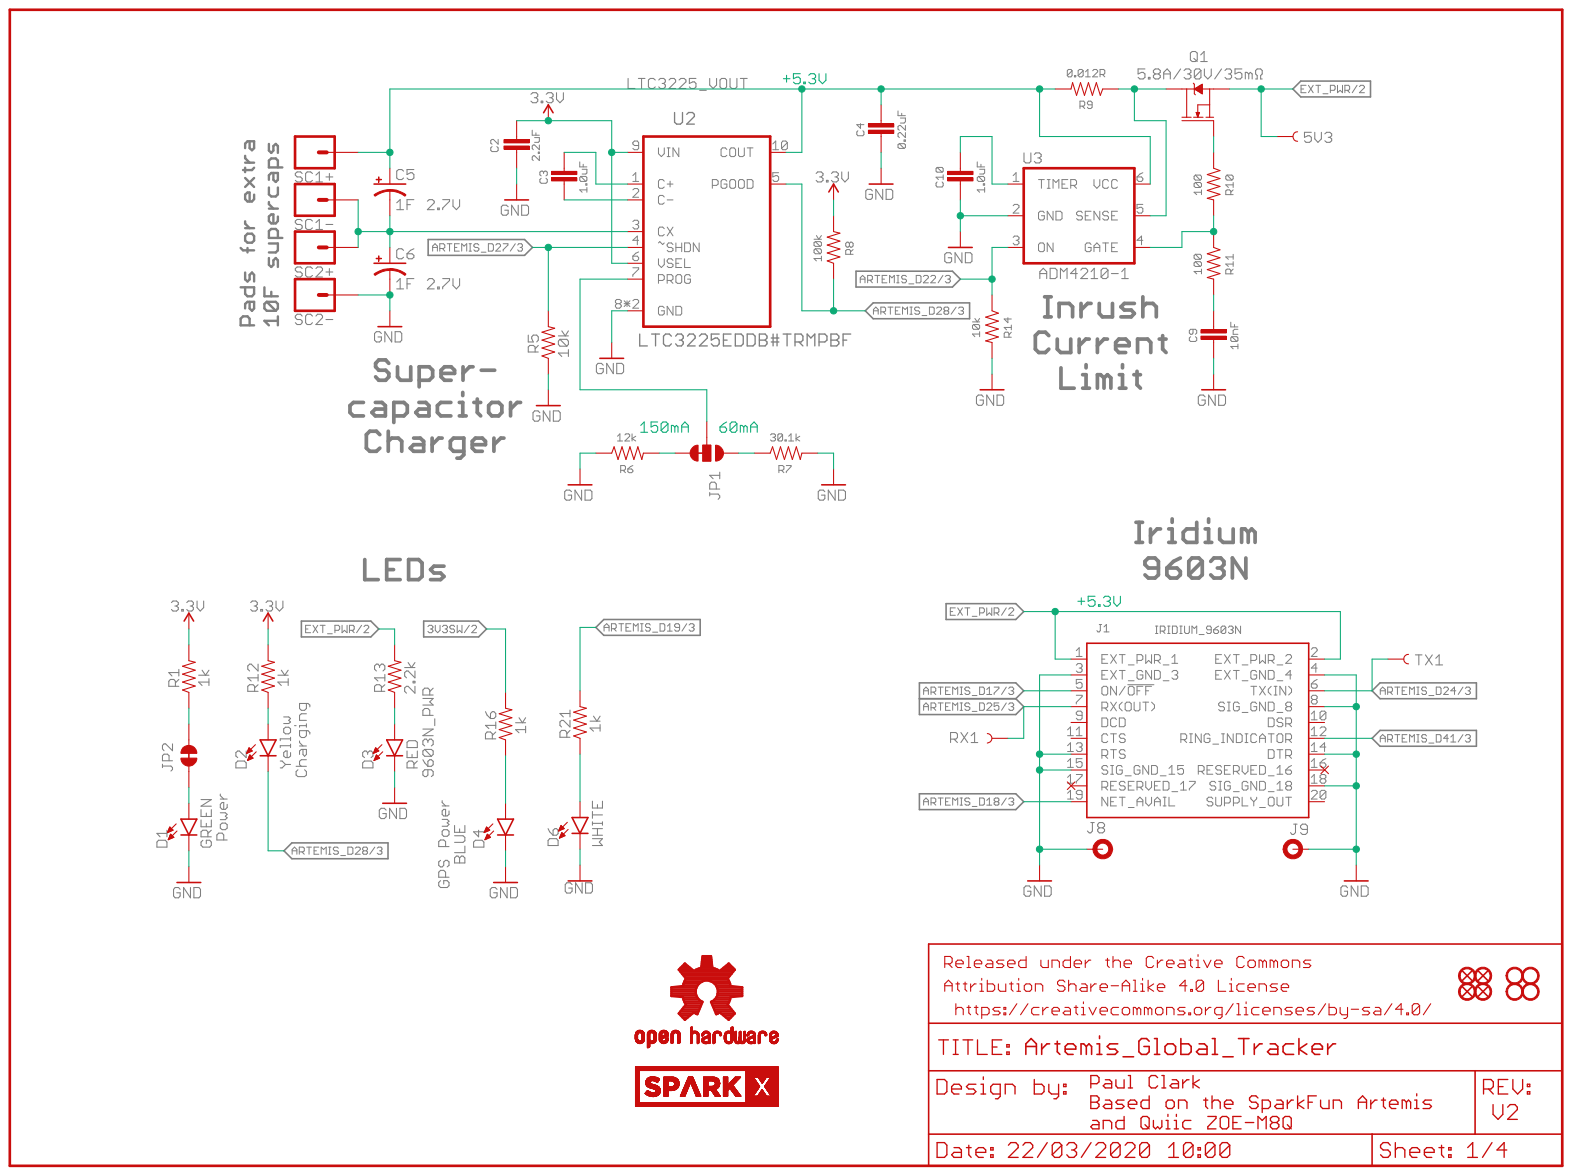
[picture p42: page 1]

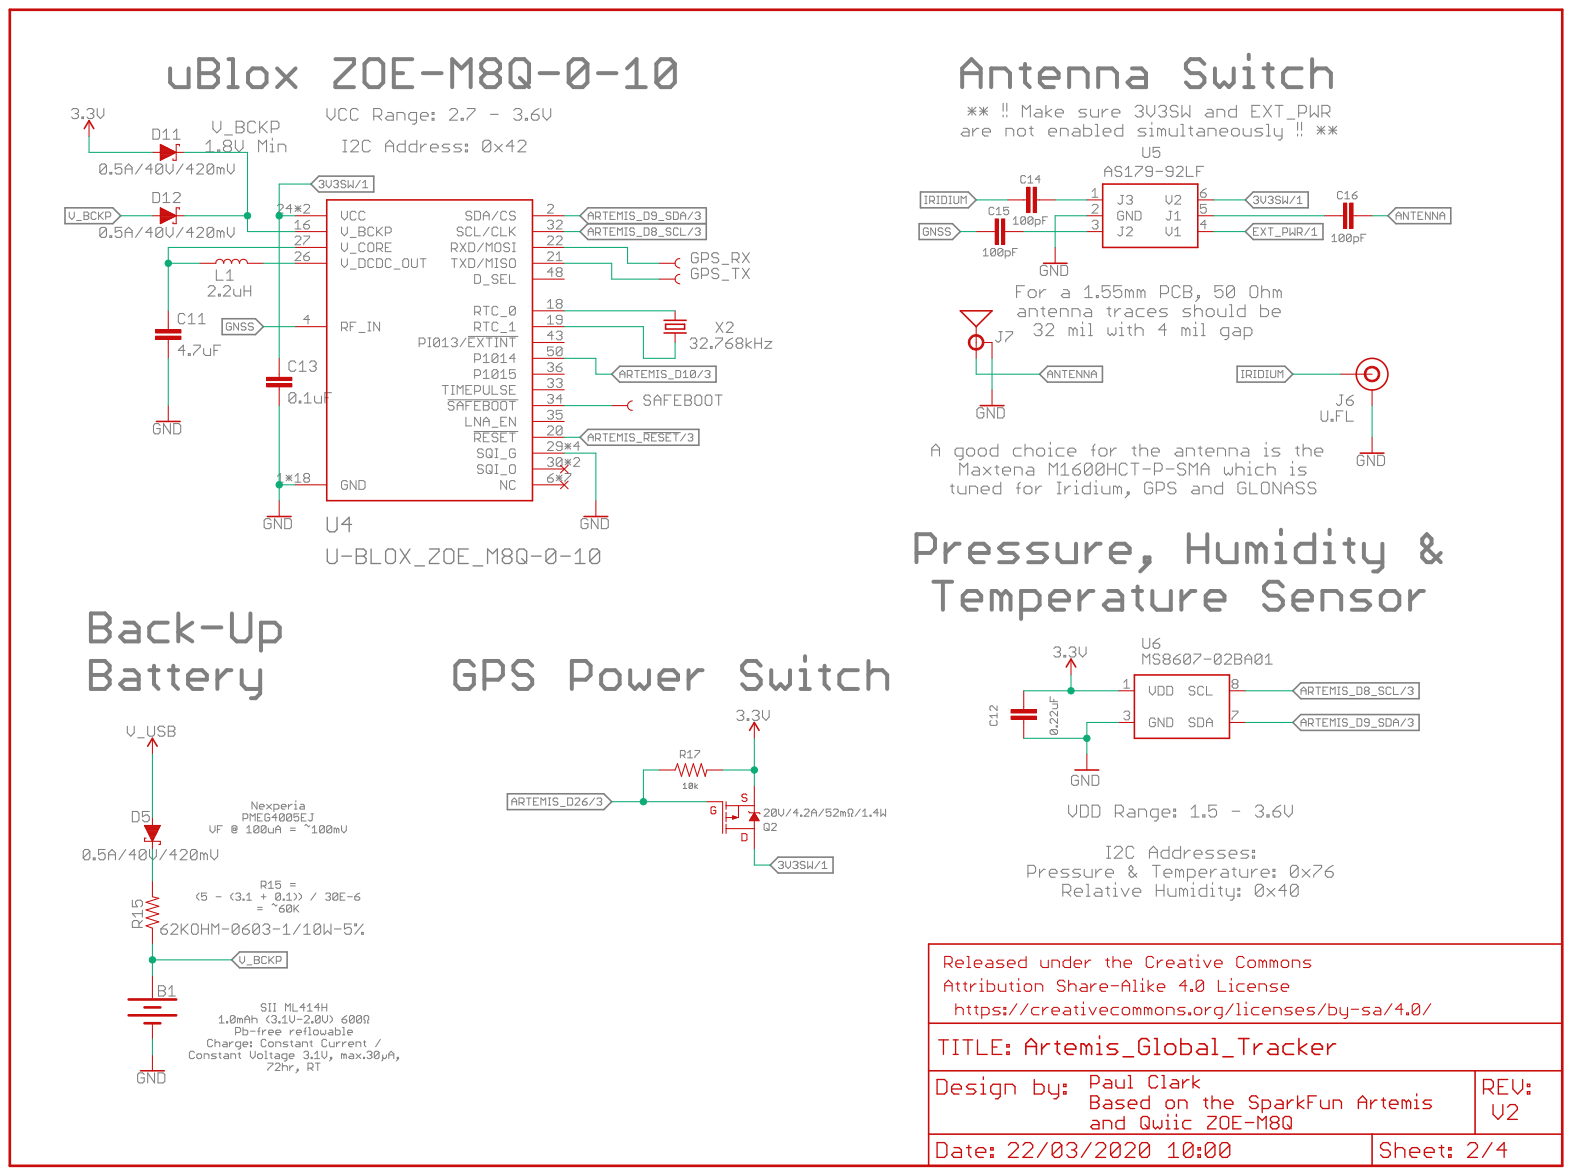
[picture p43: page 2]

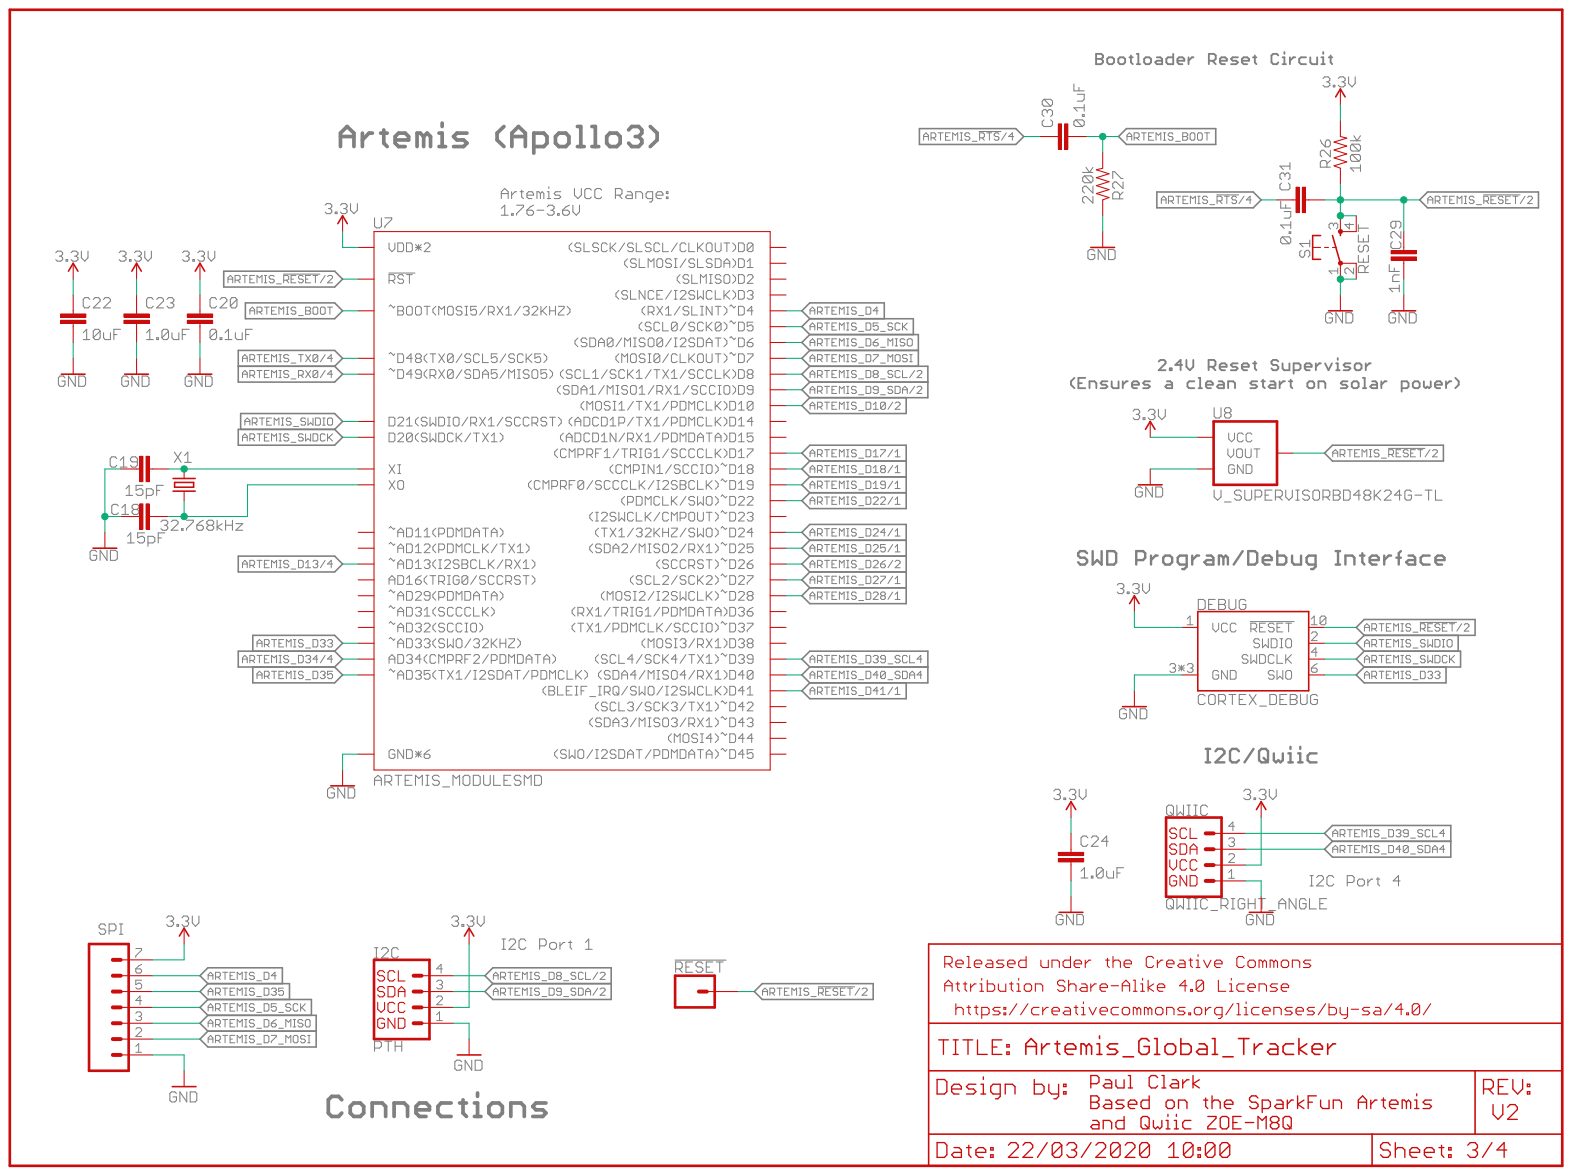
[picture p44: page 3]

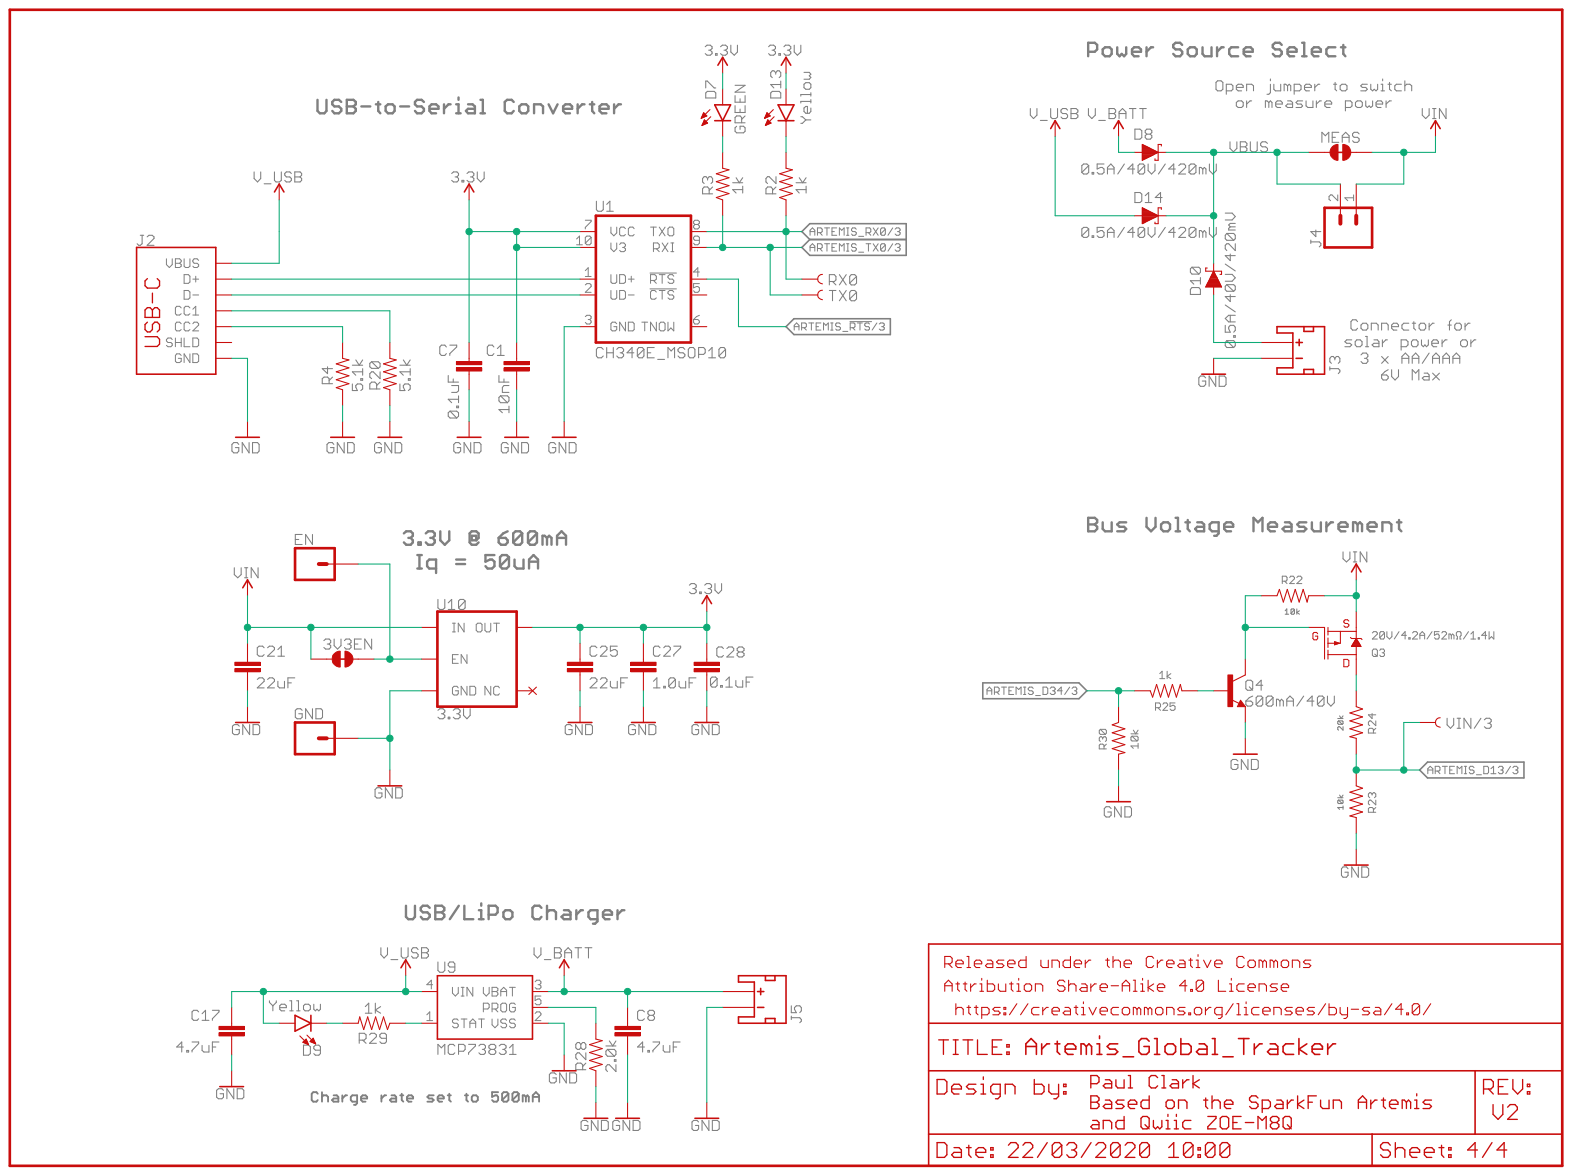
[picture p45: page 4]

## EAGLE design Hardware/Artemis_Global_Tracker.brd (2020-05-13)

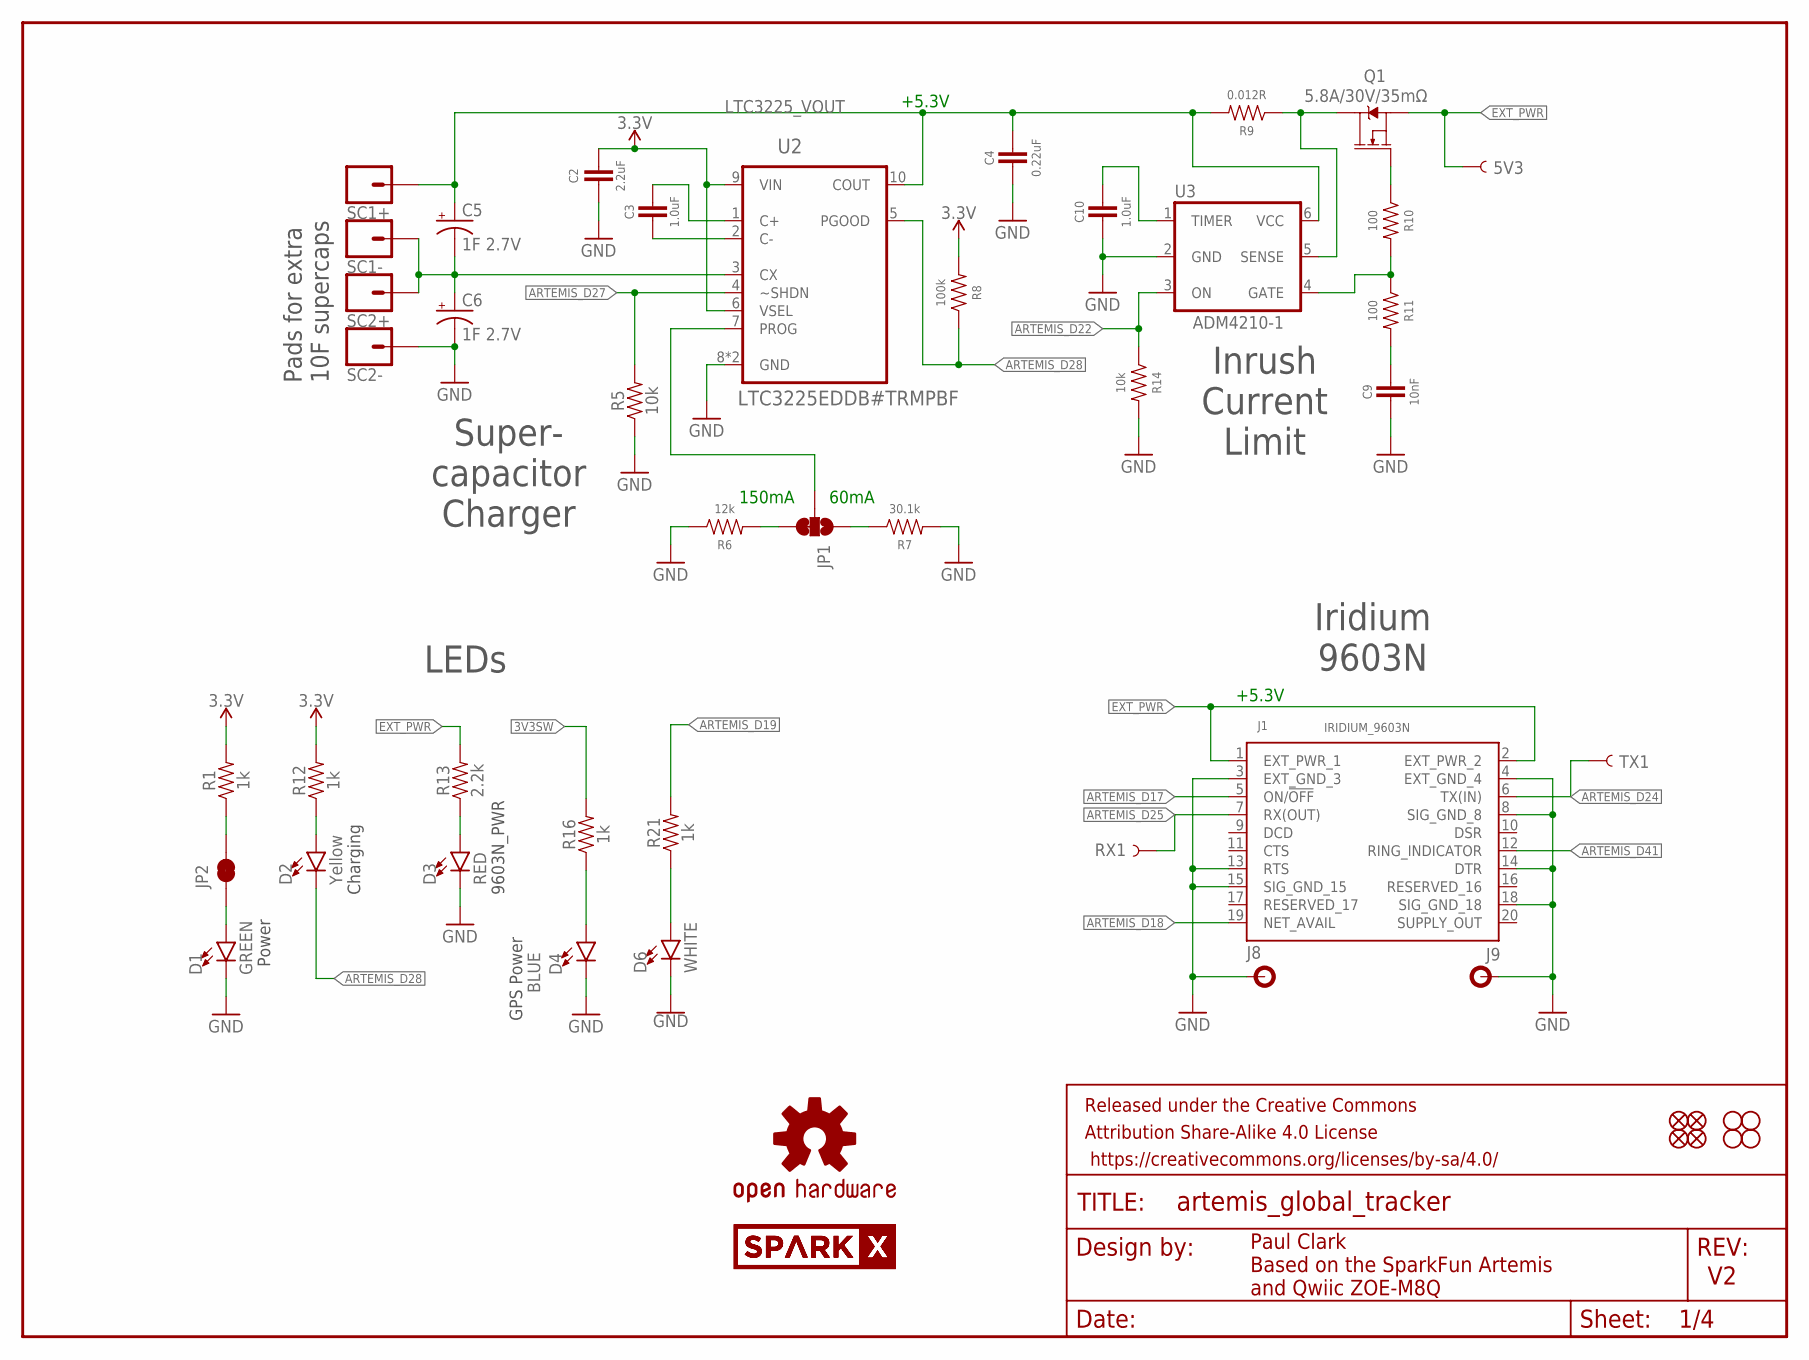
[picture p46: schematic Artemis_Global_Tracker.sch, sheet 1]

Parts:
5V3: TEST-POINT3X5; PAD.03X.05
C2: 2.2uF; 0603
C3, C10: 1.0uF; 0603
C4: 0.22uF; 0603
C5, C6: 1F 2.7V; CPOL-RADIAL-1F-2.7V
C9: 10nF; 0603
D1: GREEN; LED-0603
D2: Yellow; LED-0603
D3: RED; LED-0603
D4: BLUE; LED-0603
D6: WHITE; LED-0603
FRAME1: FRAME-LETTER; CREATIVE_COMMONS
J1: IRIDIUM_9603N
J8, J9: STANDOFFS_M2X0.4_STEEL_6MM; STANDOFF_M2X0.4
JP1: JUMPER-SMT_3_1-NC_TRACE_SILK; SMT-JUMPER_3_1-NC_TRACE_SILK
JP2: JUMPER-SMT_2_NC_TRACE_SILK; SMT-JUMPER_2_NC_TRACE_SILK
JP7, JP8, JP13, JP14: FIDUCIAL1X2; FIDUCIAL-1X2
JP9, JP10, JP11, JP12: STAND-OFF
LOGO4: OSHW-LOGOMINI; OSHW-LOGO-MINI
Q1: 5.8A/30V/35mΩ; SOT23-3
R1, R12, R16, R21: 1k; 0603
R5, R14: 10k; 0603
R6: 12k; 0603
R7: 30.1k; 0603
R8: 100k; 0603
R9: 0.012R; 0603
R10, R11: 100; 0603
R13: 2.2k; 0603
RX1: TEST-POINT3X5; PAD.03X.05
SC1+, SC1-, SC2+, SC2-: CONN_01PTH_NO_SILK_YES_STOP; 1X01_NO_SILK
SPARKX1, SPARKX2: SPARKX-LOGO4; SPARKX-MEDIUM
TX1: TEST-POINT3X5; PAD.03X.05
U2: LTC3225EDDB#TRMPBF; DFN300X200-10L
U3: ADM4210-1; TSOT6

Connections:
3.3V: C2.1, R1.2, R8.2, R12.2, U2.6 (VSEL), U2.9 (VIN); also elsewhere on the board
3V3SW: R16.2; also elsewhere on the board
ARTEMIS_D17: J1.5 (ON/!OFF!); also elsewhere on the board
ARTEMIS_D18: J1.19 (NET_AVAIL); also elsewhere on the board
ARTEMIS_D19: R21.2; also elsewhere on the board
ARTEMIS_D22: R14.1, U3.3 (ON); also elsewhere on the board
ARTEMIS_D24: J1.6 (TX(IN)), TX1.P$1; also elsewhere on the board
ARTEMIS_D25: J1.7 (RX(OUT)), RX1.P$1; also elsewhere on the board
ARTEMIS_D27: R5.2, U2.4 (~SHDN); also elsewhere on the board
ARTEMIS_D28: D2.C, R8.1, U2.5 (PGOOD); also elsewhere on the board
ARTEMIS_D41: J1.12 (RING_INDICATOR); also elsewhere on the board
EXT_PWR: 5V3.P$1, J1.1 (EXT_PWR_1), J1.2 (EXT_PWR_2), Q1.2 (S), R13.2; also elsewhere on the board
GND: C2.2, C4.2, C6.-, C9.2, C10.2, D1.C, D3.C, D4.C, D6.C, J1.3 (EXT_GND_3), J1.4 (EXT_GND_4), J1.8 (SIG_GND_8), J1.13 (RTS), J1.14 (DTR), J1.15 (SIG_GND_15), J1.18 (SIG_GND_18), J8.1, J9.1, R5.1, R6.1, R7.2, R14.2, SC2-.1, U2.8 (GND), U2.11 (GND), U3.2 (GND); also elsewhere on the board
LTC3225_VOUT: C4.1, C5.+, R9.2, SC1+.1, U2.10 (COUT), U3.6 (VCC)
unnamed: C5.-, C6.+, SC1-.1, SC2+.1, U2.3 (CX)
unnamed: JP1.3, R6.2
unnamed: JP2.2, R1.1
unnamed: JP1.1, R7.1
unnamed: D2.A, R12.1
unnamed: D3.A, R13.1
unnamed: Q1.3 (D), R9.1, U3.5 (SENSE)
unnamed: C3.2, U2.2 (C-)
unnamed: C3.1, U2.1 (C+)
unnamed: JP1.2, U2.7 (PROG)
unnamed: Q1.1 (G), R10.1
unnamed: R10.2, R11.1, U3.4 (GATE)
unnamed: C9.1, R11.2
unnamed: C10.1, U3.1 (TIMER)
unnamed: D4.A, R16.1
unnamed: D1.A, JP2.1
unnamed: D6.A, R21.1

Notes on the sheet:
Paul Clark Based on the SparkFun Artemis and Qwiic ZOE-M8Q
Power
+5.3V
150mA
60mA
Pads for extra 10F supercaps
Super- capacitor Charger
Charging
9603N_PWR
Iridium 9603N
LEDs
Inrush Current Limit
GPS Power

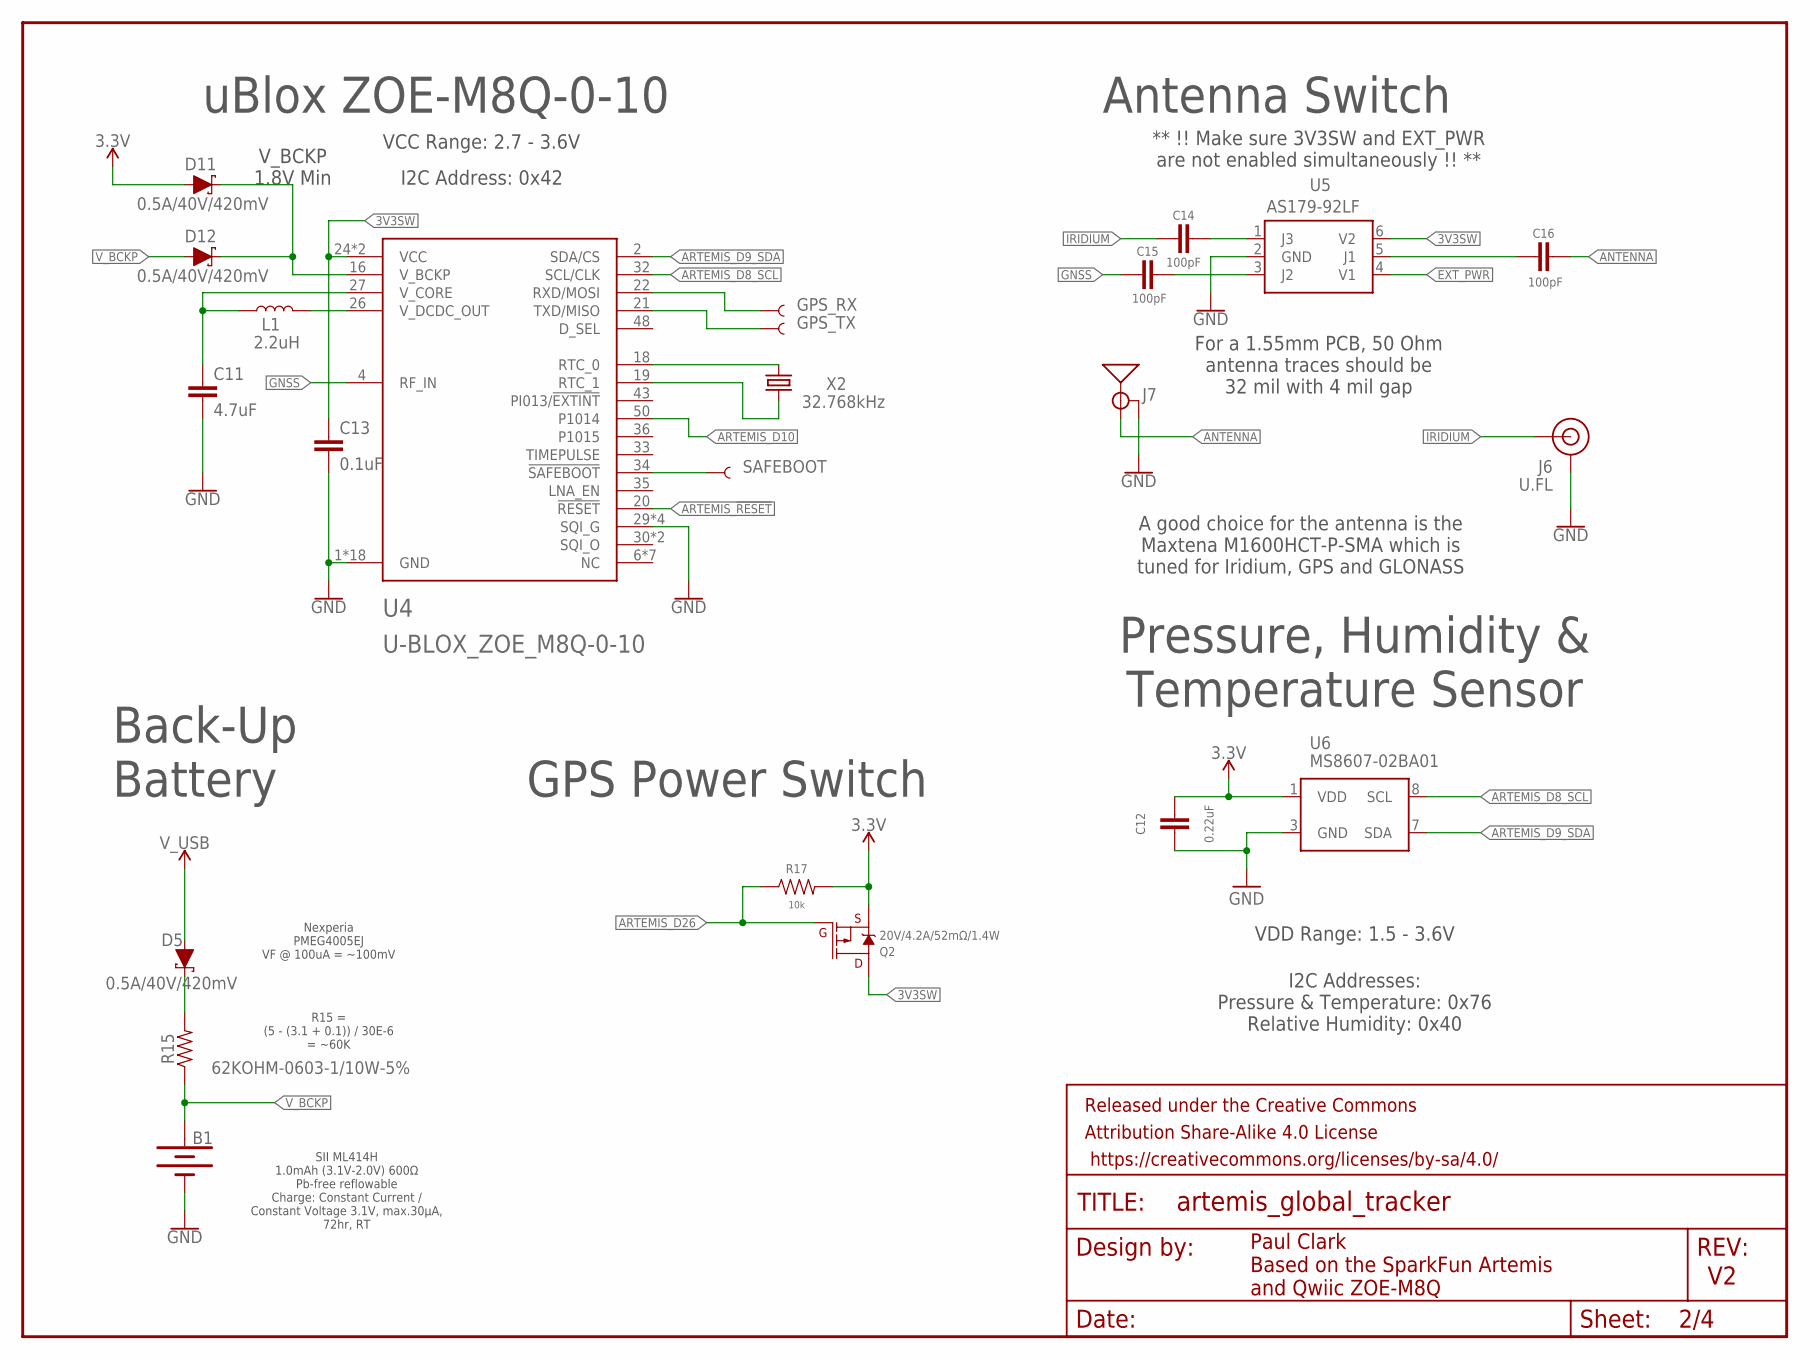
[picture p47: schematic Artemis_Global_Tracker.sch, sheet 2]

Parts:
B1: ML414H_IV01E_BATTERY; ML414H_IV01E
C11: 4.7uF; 0603
C12: 0.22uF; 0603
C13: 0.1uF; 0603
C14, C15, C16: 100pF; 0603
D5, D11, D12: 0.5A/40V/420mV; SOD-323
FRAME2: FRAME-LETTER; CREATIVE_COMMONS
GPS_RX: TEST-POINT3X5; PAD.03X.05
GPS_TX: TEST-POINT3X5; PAD.03X.05
J6: U.FL
J7: ANTENNA-GROUNDEDEDGE_SMA; SMA-EDGE
L1: 2.2uH; 0806
Q2: 20V/4.2A/52mΩ/1.4W; SOT23-3
R15: 62KOHM-0603-1/10W-5%; 0603
R17: 10k; 0603
SAFEBOOT: TEST-POINT3X5; PAD.03X.05
U4: U-BLOX_ZOE_M8Q-0-10; UBLOX_ZOE_M8-0-10
U5: AS179-92LF; SOT65P220X100-6N
U6: MS8607-02BA01
X2: 32.768kHz; CRYSTAL-SMD-3.2X1.5MM

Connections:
3.3V: C12.1, D11.A, Q2.2 (S), R17.2, U6.1 (VDD); also elsewhere on the board
3V3SW: C13.1, Q2.3 (D), U4.24 (VCC), U4.25 (VCC), U5.6 (V2); also elsewhere on the board
ANTENNA: C16.1, J7.SIG (SIGNAL)
ARTEMIS_!RESET: U4.20 (!RESET); also elsewhere on the board
ARTEMIS_D8_SCL: U4.32 (SCL/CLK), U6.8 (SCL); also elsewhere on the board
ARTEMIS_D9_SDA: U4.2 (SDA/CS), U6.7 (SDA); also elsewhere on the board
ARTEMIS_D10: U4.50 (P1014); also elsewhere on the board
ARTEMIS_D26: Q2.1 (G), R17.1; also elsewhere on the board
EXT_PWR: U5.4 (V1); also elsewhere on the board
GND: B1.-, C11.2, C12.2, C13.2, J6.1 (GND), J6.2 (GND), J7.GND@0 (GND), J7.GND@1 (GND), J7.GND@2 (GND), J7.GND@3 (GND), U4.1 (GND), U4.3 (GND), U4.5 (GND), U4.7 (GND), U4.8 (GND), U4.9 (GND), U4.10 (GND), U4.11 (GND), U4.12 (GND), U4.17 (GND), U4.23 (GND), U4.29 (SQI_G), U4.31 (SQI_G), U4.37 (GND), U4.38 (GND), U4.39 (GND), U4.40 (GND), U4.41 (GND), U4.44 (GND), U4.46 (SQI_G), U4.47 (SQI_G), U4.49 (GND), U5.2 (GND), U6.3 (GND); also elsewhere on the board
GNSS: C15.2, U4.4 (RF_IN)
IRIDIUM: C14.2, J6.FEED (SIGNAL)
unnamed: L1.2, U4.26 (V_DCDC_OUT)
unnamed: C11.1, L1.1, U4.27 (V_CORE)
unnamed: U4.18 (RTC_0), X2.P$2 (2)
unnamed: U4.19 (RTC_1), X2.P$1 (1)
unnamed: D5.C, R15.2
unnamed: D11.C, D12.C, U4.16 (V_BCKP)
unnamed: SAFEBOOT.P$1, U4.34 (!SAFEBOOT)
unnamed: GPS_RX.P$1, U4.22 (RXD/MOSI)
unnamed: GPS_TX.P$1, U4.21 (TXD/MISO)
unnamed: C14.1, U5.1 (J3)
unnamed: C15.1, U5.3 (J2)
unnamed: C16.2, U5.5 (J1)
V_BCKP: B1.+, D12.A, R15.1
V_USB: D5.A; also elsewhere on the board

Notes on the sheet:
Paul Clark Based on the SparkFun Artemis and Qwiic ZOE-M8Q
uBlox ZOE-M8Q-0-10
Back-Up Battery
Antenna Switch
SII ML414H 1.0mAh (3.1V-2.0V) 600Ω Pb-free reflowable Charge: Constant Current / Constant Voltage 3.1V, max.30μA, 72hr, RT
VCC Range: 2.7 - 3.6V
I2C Address: 0x42
GPS Power Switch
Pressure, Humidity & Temperature Sensor
VDD Range: 1.5 - 3.6V
I2C Addresses: Pressure & Temperature: 0x76 Relative Humidity: 0x40
** !! Make sure 3V3SW and EXT_PWR are not enabled simultaneously !! **
A good choice for the antenna is the Maxtena M1600HCT-P-SMA which is tuned for Iridium, GPS and GLONASS
For a 1.55mm PCB, 50 Ohm antenna traces should be 32 mil with 4 mil gap
Nexperia PMEG4005EJ VF @ 100uA = ~100mV
R15 = (5 - (3.1 + 0.1)) / 30E-6 = ~60K
V_BCKP 1.8V Min

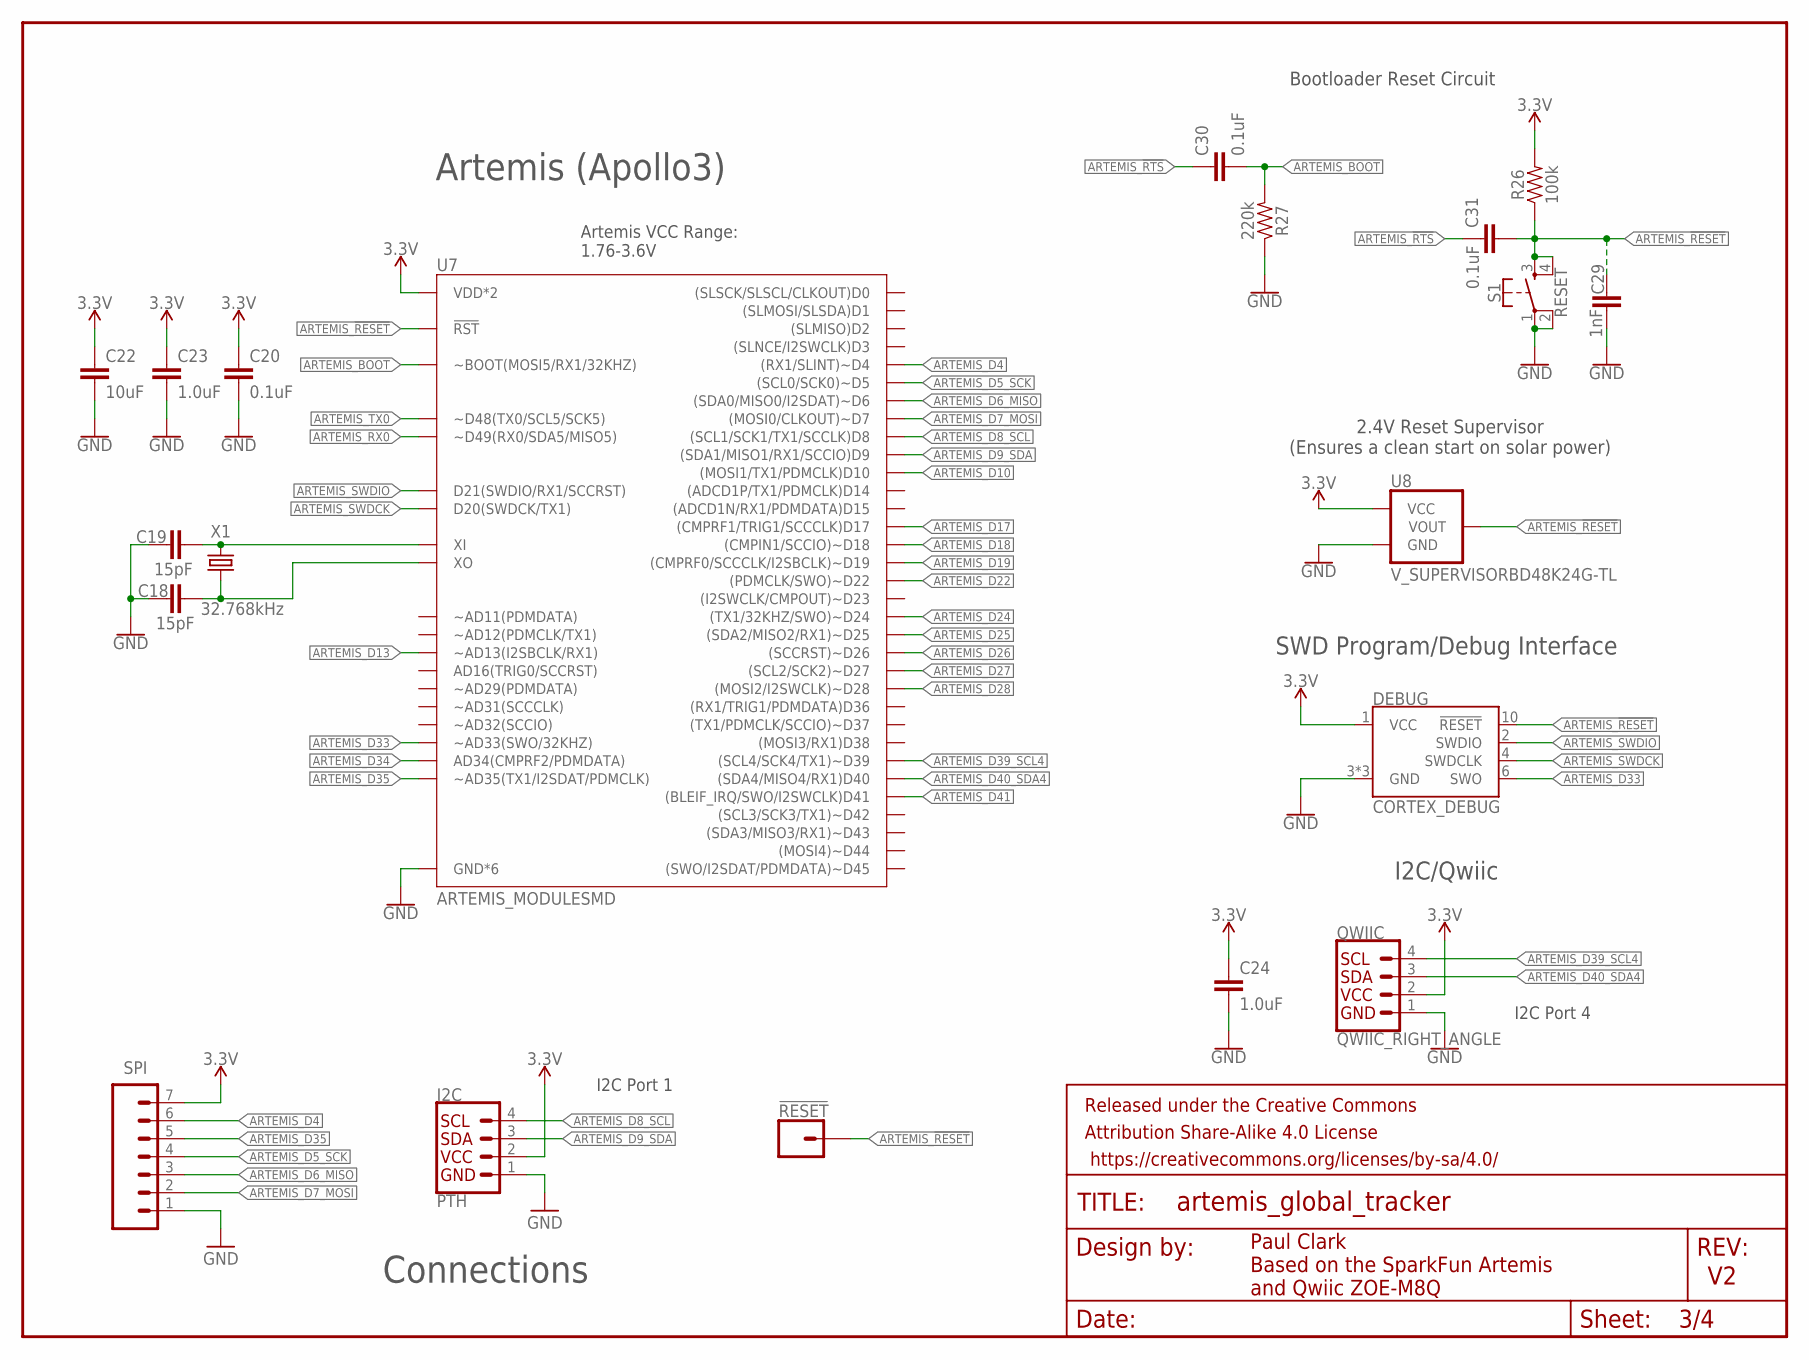
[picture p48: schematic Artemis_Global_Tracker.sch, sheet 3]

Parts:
!RESET: CONN_01PTH_NO_SILK_YES_STOP; 1X01_NO_SILK
C18, C19: 15pF; 0603
C20, C30, C31: 0.1uF; 0603
C22: 10uF; 0603
C23, C24: 1.0uF; 0603
C29: 1nF; 0603
DEBUG: CORTEX_DEBUG; 2X5-PTH-1.27MM-NO_SILK
FRAME3: FRAME-LETTER; CREATIVE_COMMONS
I2C: PTH; 1X04_NO_SILK
QWIIC: QWIIC_RIGHT_ANGLE; JST04_1MM_RA
R26: 100k; 0603
R27: 220k; 0603
S1: RESET; TACTILE_SWITCH_SMD_5.2MM
SPI: CONN_07NO_SILK; 1X07_NO_SILK
U7: ARTEMIS_MODULESMD; ARTEMIS_FP
U8: V_SUPERVISORBD48K24G-TL; SSOP3
X1: 32.768kHz; CRYSTAL-SMD-3.2X1.5MM

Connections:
3.3V: C20.2, C22.1, C23.1, C24.1, DEBUG.1 (VCC), I2C.2, QWIIC.2, R26.2, SPI.7, U7.VDD@36 (VDD*2), U7.VDD@37 (VDD*2), U8.3 (VCC); also elsewhere on the board
ARTEMIS_!RESET: !RESET.1, C29.1, C31.2, DEBUG.10 (!RESET), R26.1, S1.3, S1.4, U7.~RST (!RST), U8.2 (VOUT); also elsewhere on the board
ARTEMIS_!RTS!: C30.1, C31.1; also elsewhere on the board
ARTEMIS_BOOT: C30.2, R27.2, U7.BOOT (~BOOT(MOSI5/RX1/32KHZ))
ARTEMIS_D4: SPI.6, U7.~D4 ((RX1/SLINT)~D4)
ARTEMIS_D5_SCK: SPI.4, U7.~D5 ((SCL0/SCK0)~D5)
ARTEMIS_D6_MISO: SPI.3, U7.~D6 ((SDA0/MISO0/I2SDAT)~D6)
ARTEMIS_D7_MOSI: SPI.2, U7.D7 ((MOSI0/CLKOUT)~D7)
ARTEMIS_D8_SCL: I2C.4, U7.D8 ((SCL1/SCK1/TX1/SCCLK)D8); also elsewhere on the board
ARTEMIS_D9_SDA: I2C.3, U7.D9 ((SDA1/MISO1/RX1/SCCIO)D9); also elsewhere on the board
ARTEMIS_D10: U7.D10 ((MOSI1/TX1/PDMCLK)D10); also elsewhere on the board
ARTEMIS_D13: U7.~AD13 (~AD13(I2SBCLK/RX1)); also elsewhere on the board
ARTEMIS_D17: U7.D17 ((CMPRF1/TRIG1/SCCCLK)D17); also elsewhere on the board
ARTEMIS_D18: U7.~D18 ((CMPIN1/SCCIO)~D18); also elsewhere on the board
ARTEMIS_D19: U7.~D19 ((CMPRF0/SCCCLK/I2SBCLK)~D19); also elsewhere on the board
ARTEMIS_D22: U7.~D22 ((PDMCLK/SWO)~D22); also elsewhere on the board
ARTEMIS_D24: U7.~D24 ((TX1/32KHZ/SWO)~D24); also elsewhere on the board
ARTEMIS_D25: U7.~D25 ((SDA2/MISO2/RX1)~D25); also elsewhere on the board
ARTEMIS_D26: U7.~D26 ((SCCRST)~D26); also elsewhere on the board
ARTEMIS_D27: U7.~D27 ((SCL2/SCK2)~D27); also elsewhere on the board
ARTEMIS_D28: U7.~D28 ((MOSI2/I2SWCLK)~D28); also elsewhere on the board
ARTEMIS_D33: DEBUG.6 (SWO), U7.~AD33/SWO (~AD33(SWO/32KHZ))
ARTEMIS_D34: U7.AD34 (AD34(CMPRF2/PDMDATA)); also elsewhere on the board
ARTEMIS_D35: SPI.5, U7.~AD35 (~AD35(TX1/I2SDAT/PDMCLK))
ARTEMIS_D39_SCL4: QWIIC.4, U7.~D39 ((SCL4/SCK4/TX1)~D39)
ARTEMIS_D40_SDA4: QWIIC.3, U7.D40 ((SDA4/MISO4/RX1)D40)
ARTEMIS_D41: U7.D41 ((BLEIF_IRQ/SWO/I2SWCLK)D41); also elsewhere on the board
ARTEMIS_RX0: U7.RXI-0 (~D49(RX0/SDA5/MISO5)); also elsewhere on the board
ARTEMIS_SWDCK: DEBUG.4 (SWDCLK), U7.SWDCK (D20(SWDCK/TX1))
ARTEMIS_SWDIO: DEBUG.2 (SWDIO), U7.SWDIO (D21(SWDIO/RX1/SCCRST))
ARTEMIS_TX0: U7.TXO-0 (~D48(TX0/SCL5/SCK5)); also elsewhere on the board
GND: C18.1, C19.1, C20.1, C22.2, C23.2, C24.2, C29.2, DEBUG.3 (GND), DEBUG.5 (GND), DEBUG.9 (GND), I2C.1, QWIIC.1, R27.1, S1.1, S1.2, SPI.1, U7.GND@1 (GND*6), U7.GND@22 (GND*6), U7.GND@38 (GND*6), U7.GND@39 (GND*6), U7.GND@47 (GND*6), U7.GND@59 (GND*6), U8.1 (GND); also elsewhere on the board
XTALI: C19.2, U7.XI, X1.P$1 (1)
XTALO: C18.2, U7.XO, X1.P$2 (2)

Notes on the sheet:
Paul Clark Based on the SparkFun Artemis and Qwiic ZOE-M8Q
Artemis (Apollo3)
Artemis VCC Range: 1.76-3.6V
Bootloader Reset Circuit
SWD Program/Debug Interface
I2C/Qwiic
Connections
I2C Port 1
I2C Port 4
2.4V Reset Supervisor (Ensures a clean start on solar power)

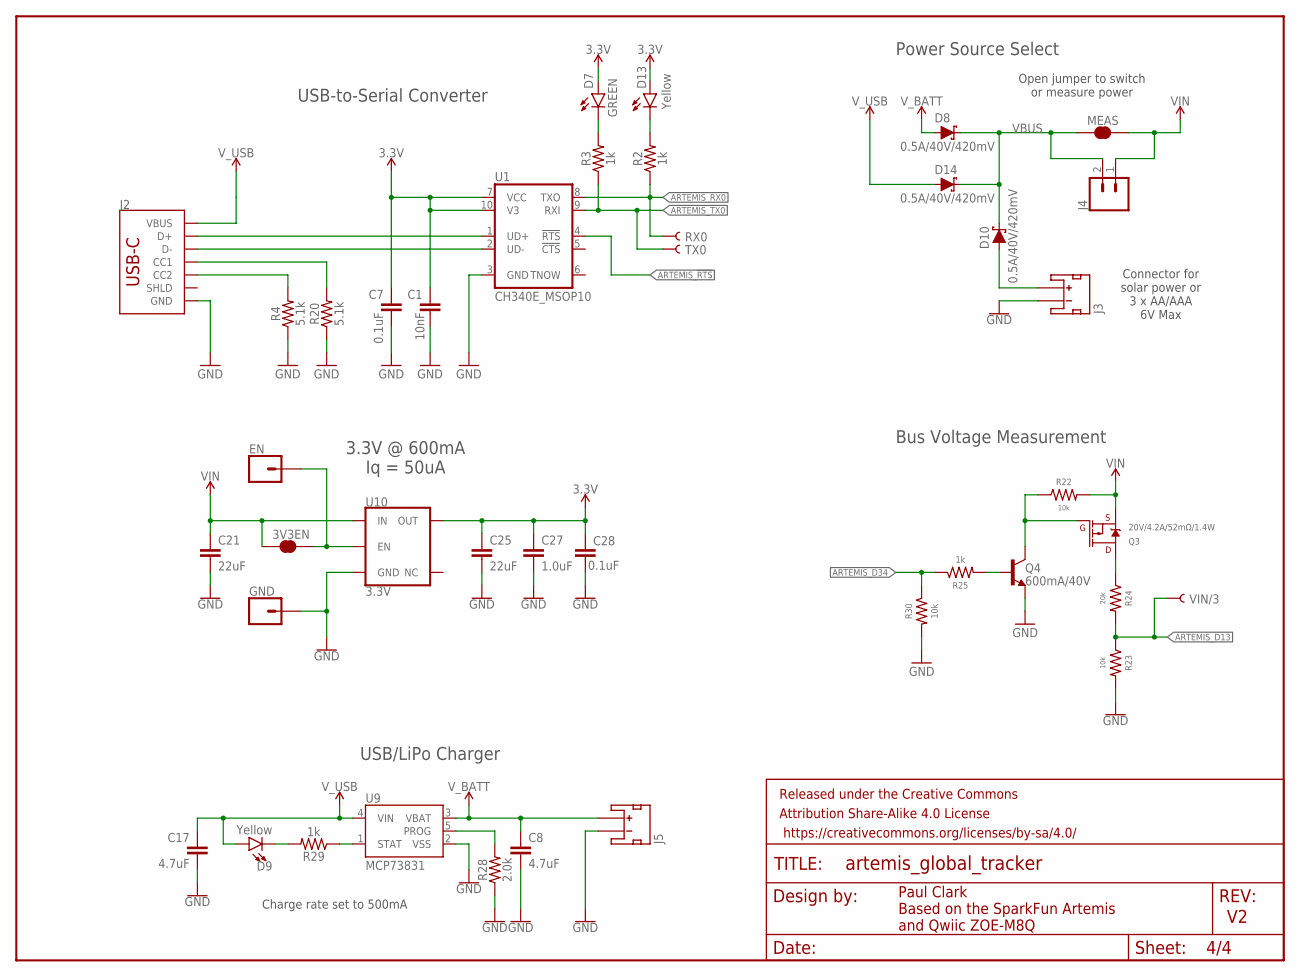
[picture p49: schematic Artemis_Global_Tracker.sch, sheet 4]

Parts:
3V3EN: JUMPER-SMT_2_NC_TRACE_SILK; SMT-JUMPER_2_NC_TRACE_SILK
C1: 10nF; 0603
C7, C28: 0.1uF; 0603
C8, C17: 4.7uF; 0603
C21: 22uF; 0805
C25: 22uF; 0603
C27: 1.0uF; 0603
D7: GREEN; LED-0603
D8, D10, D14: 0.5A/40V/420mV; SOD-323
D9, D13: Yellow; LED-0603
EN: CONN_01PTH_NO_SILK_YES_STOP; 1X01_NO_SILK
FRAME4: FRAME-LETTER; CREATIVE_COMMONS
GND: CONN_01PTH_NO_SILK_YES_STOP; 1X01_NO_SILK
J2: USB-C; USB-C-16P
J3, J5: JST_2MM_MALE; JST-2-SMD
J4: CONN_021X02_NO_SILK; 1X02_NO_SILK
MEAS: JUMPER-SMT_2_NC_TRACE_SILK; SMT-JUMPER_2_NC_TRACE_SILK
Q3: 20V/4.2A/52mΩ/1.4W; SOT23-3
Q4: 600mA/40V; SOT23-3
R2, R3, R25, R29: 1k; 0603
R4, R20: 5.1k; 0603
R22, R23, R30: 10k; 0603
R24: 20k; 0603
R28: 2.0k; 0603
RX0: TEST-POINT3X5; PAD.03X.05
TX0: TEST-POINT3X5; PAD.03X.05
U1: CH340E_MSOP10; MSOP10
U9: MCP73831; SOT23-5
U10: 3.3V; SOT23-5
VIN/3: TEST-POINT3X5; PAD.03X.05

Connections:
3.3V: C1.1, C7.1, C25.1, C27.1, C28.1, D7.A, D13.A, U1.7 (VCC), U1.10 (V3), U10.5 (OUT); also elsewhere on the board
ARTEMIS_!RTS!: U1.4 (!RTS); also elsewhere on the board
ARTEMIS_D13: R23.1, R24.2, VIN/3.P$1; also elsewhere on the board
ARTEMIS_D34: R25.1, R30.1; also elsewhere on the board
ARTEMIS_RX0: R2.1, RX0.P$1, U1.8 (TXO); also elsewhere on the board
ARTEMIS_TX0: R3.1, TX0.P$1, U1.9 (RXI); also elsewhere on the board
CC3: J2.B5 (CC2), R4.2
CC4: J2.A5 (CC1), R20.2
D+2: J2.A6 (D+), J2.B6 (D+), U1.1 (UD+)
D-2: J2.A7 (D-), J2.B7 (D-), U1.2 (UD-)
GND: C1.2, C7.2, C8.2, C17.2, C21.2, C25.2, C27.2, C28.2, GND.1, J2.GND, J2.GND2 (GND), J3.1 (-), J5.1 (-), Q4.2 (E), R4.1, R20.1, R23.2, R28.1, R30.2, U1.3 (GND), U9.2 (VSS), U10.2 (GND); also elsewhere on the board
unnamed: D13.C, R2.2
unnamed: D7.C, R3.2
unnamed: 3V3EN.2, EN.1, U10.3 (EN)
unnamed: Q3.1 (G), Q4.3 (C), R22.1
unnamed: R28.2, U9.5 (PROG)
unnamed: D9.C, R29.2
unnamed: R29.1, U9.1 (STAT)
unnamed: Q3.3 (D), R24.1
unnamed: Q4.1 (B), R25.2
VBUS: D8.C, D10.C, D14.C, J4.2, MEAS.1
VIN: 3V3EN.1, C21.1, J4.1, MEAS.2, Q3.2 (S), R22.2, U10.1 (IN)
V_AAA: D10.A, J3.2 (+)
V_BATT: C8.1, D8.A, J5.2 (+), U9.3 (VBAT)
V_USB: C17.1, D9.A, D14.A, J2.VBUS1 (VBUS), J2.VBUS2 (VBUS), U9.4 (VIN); also elsewhere on the board

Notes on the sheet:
Paul Clark Based on the SparkFun Artemis and Qwiic ZOE-M8Q
3.3V @ 600mA Iq = 50uA
USB/LiPo Charger
Charge rate set to 500mA
Power Source Select
USB-to-Serial Converter
Open jumper to switch or measure power
Connector for solar power or 3 x AA/AAA 6V Max
Bus Voltage Measurement

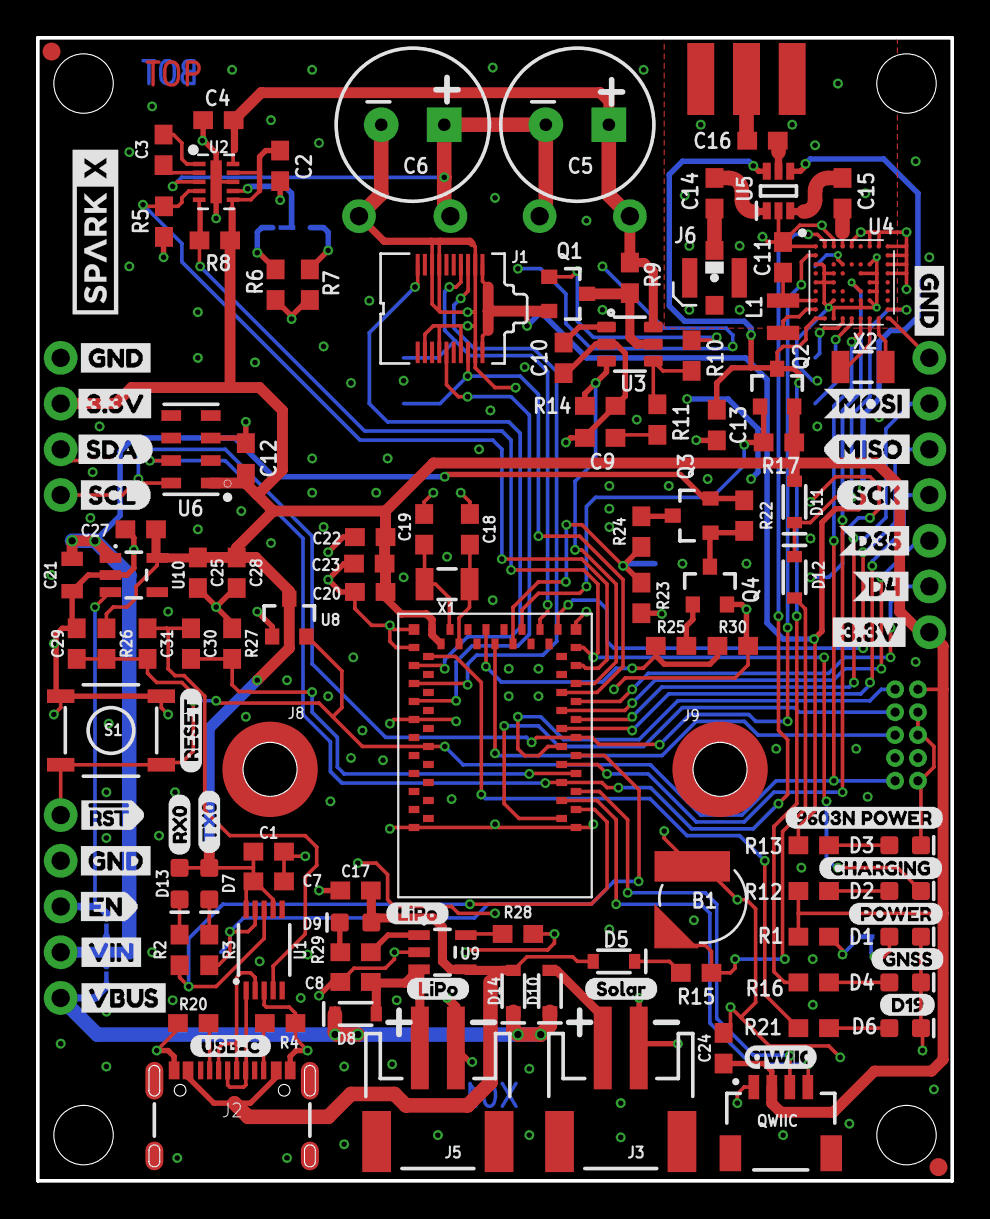
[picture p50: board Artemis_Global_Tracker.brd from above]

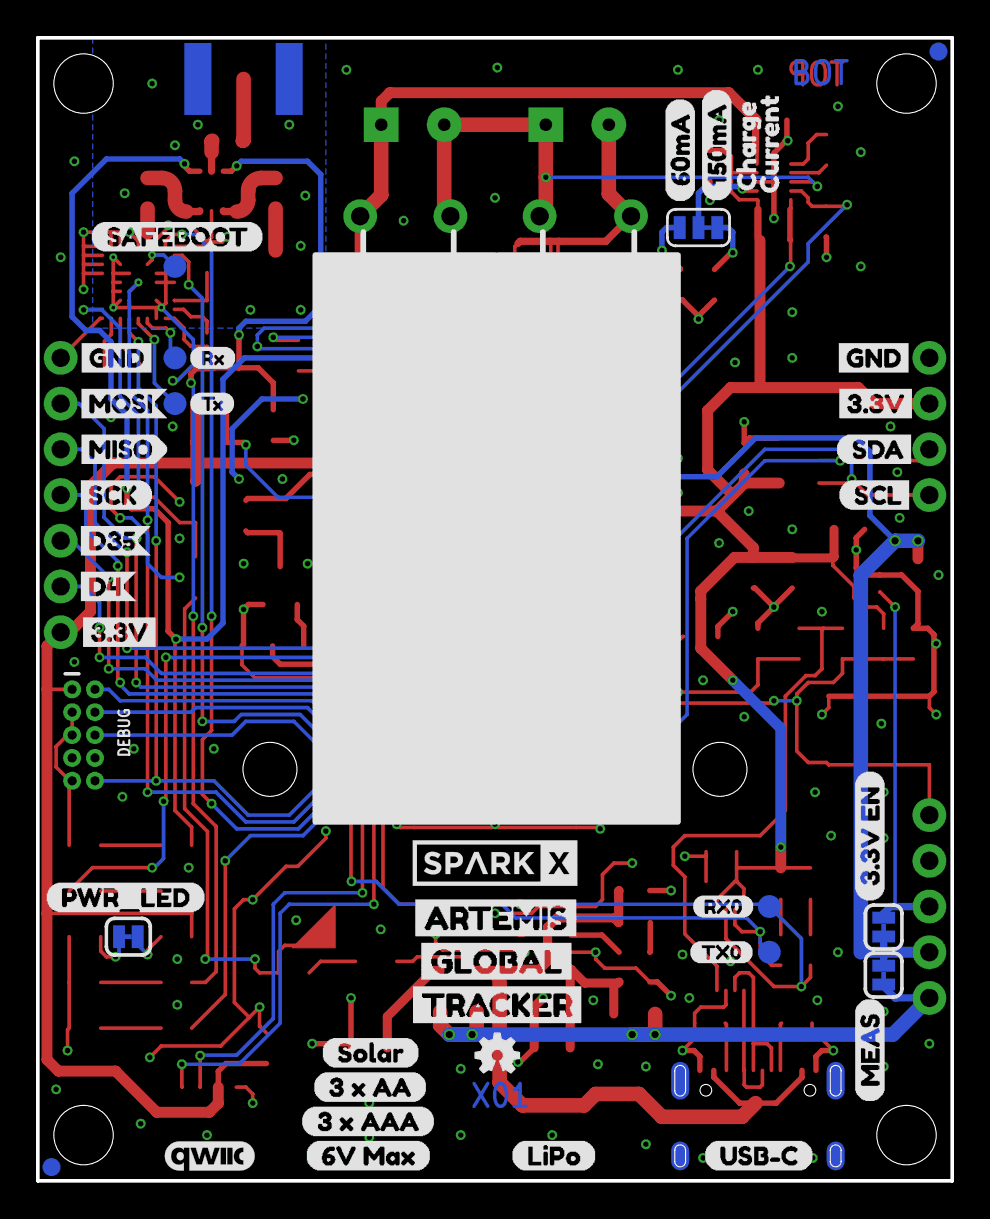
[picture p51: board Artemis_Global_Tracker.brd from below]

Board: 2 copper layers, 50.8 x 63.5 mm, 205 parts (55 on the bottom side), 88 nets.

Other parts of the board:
U$1: 60MA0
U$2: POWER0
U$3, U$12, U$17, U$22: GND1
U$4, U$20, U$21, U$24: 3#3V2
U$5: SCL0
U$6: SDA0
U$7: EN0
U$9: CHARGING0
U$10: 9603N_POWER0
U$11: QWIIC_4MM
U$13: 150MA0
U$14: CHARGE0
U$15: CURRENT0
U$16, U$38: TX00
U$18, U$31: SCK0
U$19: GNSS0
U$23, U$34: RX00
U$25: QWIIC_5MM
U$26: SCL9
U$27: SDA8
U$29, U$64: SOLAR0
U$32: 5#3V0
U$33: RX0
U$35: RX10
U$36: SAFEBOOT0
U$37: TX0
U$39: TX10
U$40: ARTEMIS0
U$41: GLOBAL0
U$42: TRACKER0
U$43: PWR_LED0
U$44: VBUS0
U$45, U$46, U$57: LIPO0
U$47: 3#3V_EN0
U$48: MEAS0
U$49: RESET0
U$50: D190
U$53, U$56: USB#C0
U$58: #RST0
U$59: GND0
U$60: VIN0
U$61: 3_X_AA0
U$62: 3_X_AAA0
U$63: 6V_MAX0
U$65: VIN#30
U$67, U$68: D350
U$69, U$70: MISO0
U$71, U$72: MOSI0
U$73, U$74: D40

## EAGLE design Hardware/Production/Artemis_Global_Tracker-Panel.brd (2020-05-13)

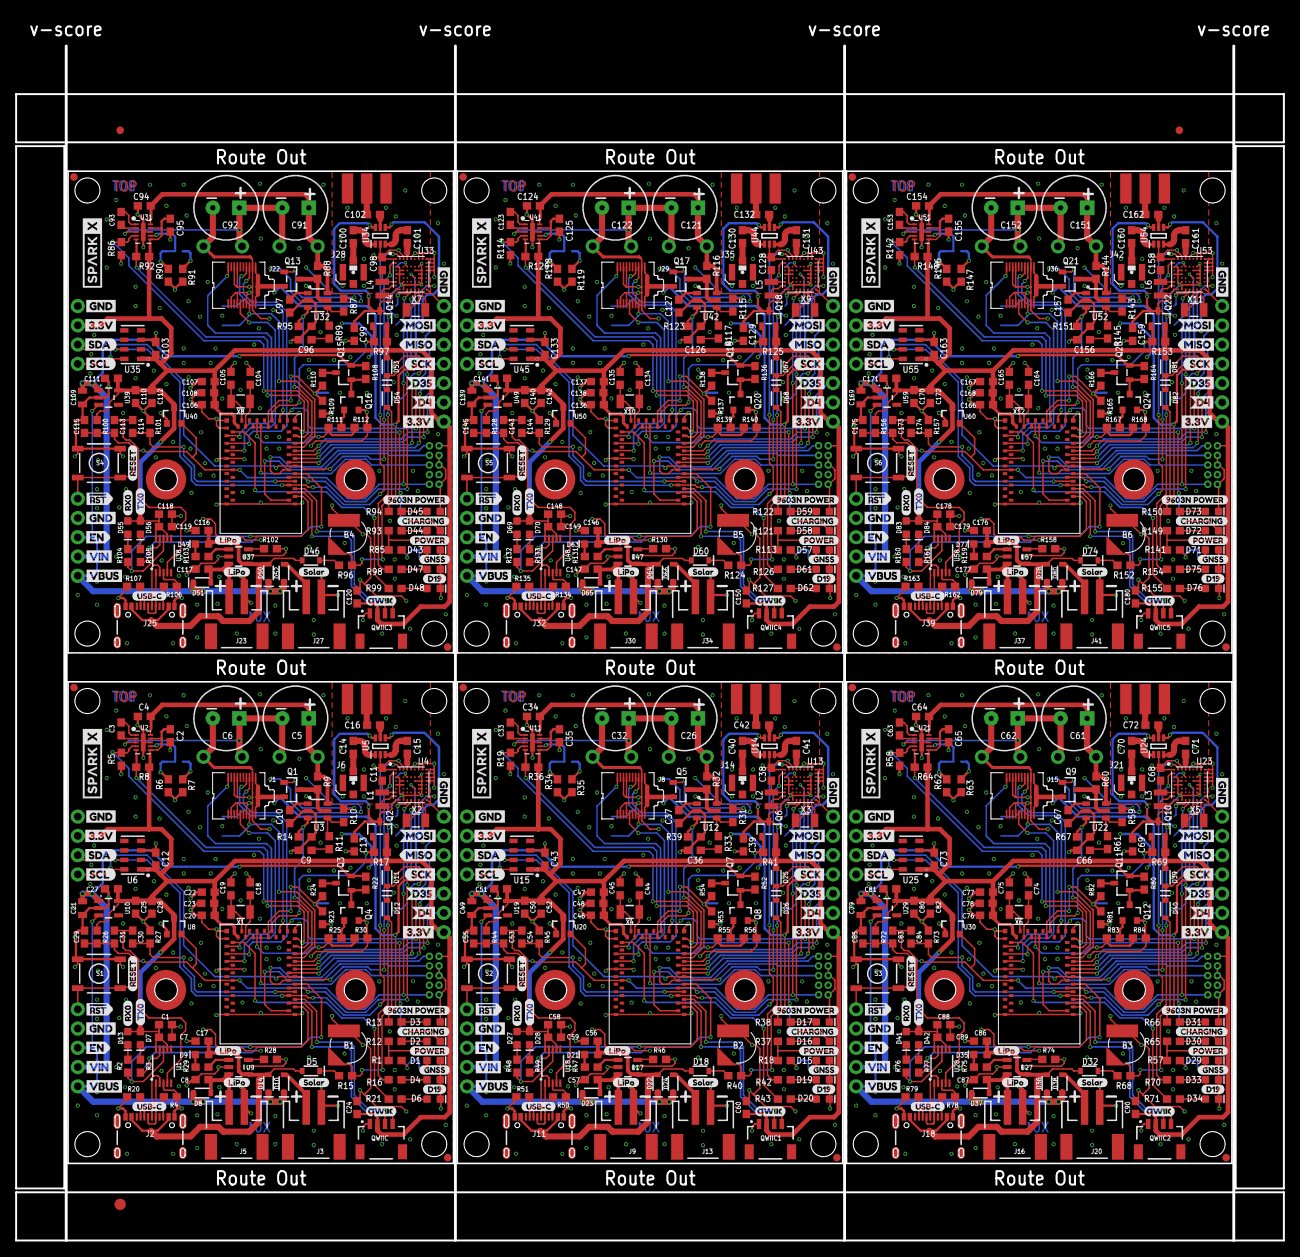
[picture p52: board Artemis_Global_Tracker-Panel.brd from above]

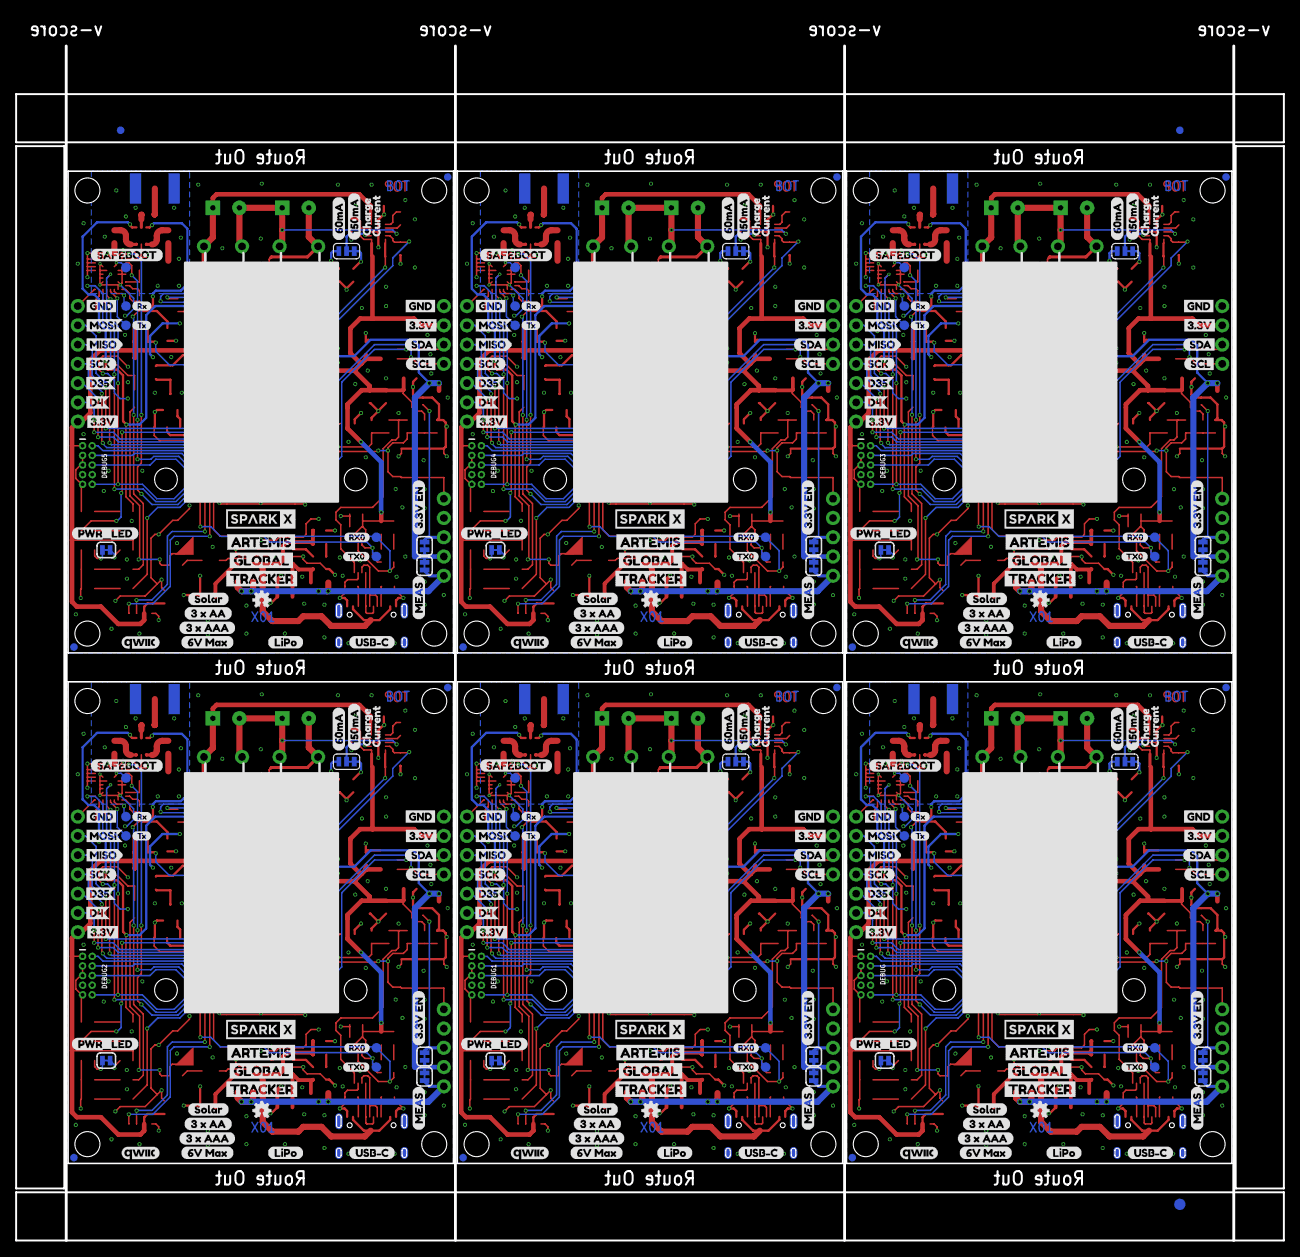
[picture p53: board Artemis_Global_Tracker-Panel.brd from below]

Board: 2 copper layers, 167.1 x 157.5 mm, 1200 parts (333 on the bottom side), 528 nets.

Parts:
3V3EN, 3V3EN1, 3V3EN2, 3V3EN3, 3V3EN4, 3V3EN5: JUMPER-SMT_2_NC_TRACE_SILK; SMT-JUMPER_2_NC_TRACE_SILK
5V1, 5V2, 5V3, 5V4, 5V5, 5V6: TEST-POINT3X5; PAD.03X.05
!RESET, !RESET1, !RESET2, !RESET3, !RESET4, !RESET5: 1X01_NO_SILK
B1, B2, B3, B4, B5, B6: ML414H_IV01E_BATTERY; ML414H_IV01E
C1, C9, C36, C58, C66, C88, C96, C118, C126, C148, C156, C178: 10nF; 0603
C2, C35, C65, C95, C125, C155: 2.2uF; 0603
C3, C10, C23, C24, C27, C33, C37, C48, C51, C60, C63, C67, C78, C81, C90, C93, C97, C108, C111, C120, C123, C127, C138, C141, C150, C153, C157, C168, C171, C180: 1.0uF; 0603
C4, C12, C34, C43, C64, C73, C94, C103, C124, C133, C154, C163: 0.22uF; 0603
C5, C6, C26, C32, C61, C62, C91, C92, C121, C122, C151, C152: 1F 2.7V; CPOL-RADIAL-1F-2.7V
C7, C13, C20, C28, C30, C31, C39, C46, C52, C53, C54, C59, C69, C76, C82, C83, C84, C89, C99, C106, C112, C113, C114, C119, C129, C136, C142, C143, C144, C149, C159, C166, C172, C173, C174, C179: 0.1uF; 0603
C8, C11, C17, C38, C56, C57, C68, C86, C87, C98, C116, C117, C128, C146, C147, C158, C176, C177: 4.7uF; 0603
C14, C15, C16, C40, C41, C42, C70, C71, C72, C100, C101, C102, C130, C131, C132, C160, C161, C162: 100pF; 0603
C18, C19, C44, C45, C74, C75, C104, C105, C134, C135, C164, C165: 15pF; 0603
C21, C49, C79, C109, C139, C169: 22uF; 0805
C22, C47, C77, C107, C137, C167: 10uF; 0603
C25, C50, C80, C110, C140, C170: 22uF; 0603
C29, C55, C85, C115, C145, C175: 1nF; 0603
D1, D7, D15, D28, D29, D42, D43, D56, D57, D70, D71, D84: GREEN; LED-0603
D2, D9, D13, D16, D21, D27, D30, D35, D41, D44, D49, D55, D58, D63, D69, D72, D77, D83: Yellow; LED-0603
D3, D17, D31, D45, D59, D73: RED; LED-0603
D4, D19, D33, D47, D61, D75: BLUE; LED-0603
D5, D8, D10, D11, D12, D14, D18, D22, D23, D24, D25, D26, D32, D36, D37, D38, D39, D40, D46, D50, D51, D52, D53, D54, D60, D64, D65, D66, D67, D68, D74, D78, D79, D80, D81, D82: 0.5A/40V/420mV; SOD-323
D6, D20, D34, D48, D62, D76: WHITE; LED-0603
DEBUG, DEBUG1, DEBUG2, DEBUG3, DEBUG4, DEBUG5: CORTEX_DEBUG; 2X5-PTH-1.27MM-NO_SILK
E$1, E$2, E$3, E$4: FIDUCIAL-1X2
E$5, E$6: FIDUCIAL-1.5X3
EN, EN1, EN2, EN3, EN4, EN5: 1X01_NO_SILK
GND, GND1, GND2, GND3, GND4, GND5: 1X01_NO_SILK
GPS_RX, GPS_RX1, GPS_RX2, GPS_RX3, GPS_RX4, GPS_RX5: TEST-POINT3X5; PAD.03X.05
GPS_TX, GPS_TX1, GPS_TX2, GPS_TX3, GPS_TX4, GPS_TX5: TEST-POINT3X5; PAD.03X.05
I2C, I2C1, I2C2, I2C3, I2C4, I2C5: PTH; 1X04_NO_SILK
J1, J8, J15, J22, J29, J36: IRIDIUM_9603N
J2, J11, J18, J25, J32, J39: USB-C; USB-C-16P
J3, J5, J9, J13, J16, J20, J23, J27, J30, J34, J37, J41: JST-2-SMD
J4, J10, J17, J24, J31, J38: 1X02_NO_SILK
J6, J14, J21, J28, J35, J42: U.FL
J7, J12, J19, J26, J33, J40: ANTENNA-GROUNDEDEDGE_SMA; SMA-EDGE
JP1, JP15, JP25, JP35, JP45, JP55: JUMPER-SMT_3_1-NC_TRACE_SILK; SMT-JUMPER_3_1-NC_TRACE_SILK
JP2, JP16, JP26, JP36, JP46, JP56: JUMPER-SMT_2_NC_TRACE_SILK; SMT-JUMPER_2_NC_TRACE_SILK
JP3, JP4, JP5, JP6, JP7, JP8, JP13, JP14, JP21, JP22, JP23, JP24, JP31, JP32, JP33, JP34, JP41, JP42, JP43, JP44, JP51, JP52, JP53, JP54: FIDUCIAL1X2; FIDUCIAL-1X2
JP9, JP10, JP11, JP12, JP17, JP18, JP19, JP20, JP27, JP28, JP29, JP30, JP37, JP38, JP39, JP40, JP47, JP48, JP49, JP50, JP57, JP58, JP59, JP60: STAND-OFF
L1, L2, L3, L4, L5, L6: 2.2uH; 0806
LOGO1, LOGO2, LOGO3, LOGO4, LOGO5, LOGO6: OSHW-LOGOMINI; OSHW-LOGO-MINI
MEAS, MEAS1, MEAS2, MEAS3, MEAS4, MEAS5: JUMPER-SMT_2_NC_TRACE_SILK; SMT-JUMPER_2_NC_TRACE_SILK
Q1, Q5, Q9, Q13, Q17, Q21: DMG3414U-7; SOT23-R
Q2, Q3, Q6, Q7, Q10, Q11, Q14, Q15, Q18, Q19, Q22, Q23: DMG3415U-7; SOT23-R
Q4, Q8, Q12, Q16, Q20, Q24: 600mA/40V; SOT23-3
QWIIC, QWIIC1, QWIIC2, QWIIC3, QWIIC4, QWIIC5: QWIIC_RIGHT_ANGLE; JST04_1MM_RA
R1, R2, R3, R12, R16, R18, R21, R25, R29, R37, R42, R43, R47, R48, R49, R55, R57, R65, R70, R71, R75, R76, R77, R83, R85, R93, R98, R99, R103, R104, R105, R111, R113, R121, R126, R127, R131, R132, R133, R139, R141, R149, R154, R155, R159, R160, R161, R167: 1k; 0603
R4, R20, R50, R51, R78, R79, R106, R107, R134, R135, R162, R163: 5.1k; 0603
R5, R14, R17, R19, R22, R23, R30, R39, R41, R52, R53, R56, R58, R67, R69, R80, R81, R84, R86, R95, R97, R108, R109, R112, R114, R123, R125, R136, R137, R140, R142, R151, R153, R164, R165, R168: 10k; 0603
R6, R34, R62, R90, R118, R146: 12k; 0603
R7, R35, R63, R91, R119, R147: 30.1k; 0603
R8, R26, R36, R44, R64, R72, R92, R100, R120, R128, R148, R156: 100k; 0603
R9, R32, R60, R88, R116, R144: 0.012R; 0603
R10, R11, R31, R33, R59, R61, R87, R89, R115, R117, R143, R145: 100; 0603
R13, R38, R66, R94, R122, R150: 2.2k; 0603
R15, R40, R68, R96, R124, R152: 62KOHM-0603-1/10W-5%; 0603
R24, R54, R82, R110, R138, R166: 20k; 0603
R27, R45, R73, R101, R129, R157: 220k; 0603
R28, R46, R74, R102, R130, R158: 2.0k; 0603
RX0, RX1, RX2, RX3, RX4, RX5, RX6, RX7, RX8, RX9, RX10, RX11: TEST-POINT3X5; PAD.03X.05
S1, S2, S3, S4, S5, S6: RESET; TACTILE_SWITCH_SMD_5.2MM
SAFEBOOT, SAFEBOOT1, SAFEBOOT2, SAFEBOOT3, SAFEBOOT4, SAFEBOOT5: TEST-POINT3X5; PAD.03X.05
SC1+, SC1+1, SC1+2, SC1+3, SC1+4, SC1+5, SC1-, SC1-1, SC1-2, SC1-3, SC1-4, SC1-5, SC2+, SC2+1, SC2+2, SC2+3, SC2+4, SC2+5, SC2-, SC2-1, SC2-2, SC2-3, SC2-4, SC2-5: 1X01_NO_SILK
SPARKX1, SPARKX2, SPARKX3, SPARKX4, SPARKX5, SPARKX6, SPARKX7, SPARKX8, SPARKX9, SPARKX10, SPARKX11, SPARKX12: SPARKX-LOGO4; SPARKX-MEDIUM
SPI, SPI1, SPI2, SPI3, SPI4, SPI5: 1X07_NO_SILK
TX0, TX1, TX2, TX3, TX4, TX5, TX6, TX7, TX8, TX9, TX10, TX11: TEST-POINT3X5; PAD.03X.05
U1, U18, U28, U38, U48, U58: CH340E_MSOP10; MSOP10
U2, U11, U21, U31, U41, U51: LTC3225EDDB#TRMPBF; DFN300X200-10L
U3, U12, U22, U32, U42, U52: ADM4210-1; TSOT6
U4, U13, U23, U33, U43, U53: UBLOX_ZOE_M8-0-10
U5, U14, U24, U34, U44, U54: AS179-92LF; SOT65P220X100-6N
U6, U15, U25, U35, U45, U55: MS8607-02BA01
U7, U16, U26, U36, U46, U56: ARTEMIS_MODULESMD; ARTEMIS_FP
U8, U20, U30, U40, U50, U60: V_SUPERVISORBD48K24G-TL; SSOP3
U9, U17, U27, U37, U47, U57: MCP73831; SOT23-5
U10, U19, U29, U39, U49, U59: 3.3V; SOT23-5
U$1, U$76, U$142, U$208, U$274, U$340: 60MA0
U$2, U$55, U$139, U$205, U$271, U$337: POWER0
U$3, U$12, U$17, U$22, U$28, U$52, U$80, U$81, U$134, U$137, U$146, U$147, U$200, U$203, U$212, U$213, U$266, U$269, U$278, U$279, U$332, U$335, U$344, U$345: GND1
U$4, U$8, U$20, U$21, U$24, U$54, U$82, U$83, U$133, U$138, U$148, U$149, U$199, U$204, U$214, U$215, U$265, U$270, U$280, U$281, U$331, U$336, U$346, U$347: 3#3V2
U$5, U$84, U$150, U$216, U$282, U$348: SCL0
U$6, U$85, U$151, U$217, U$283, U$349: SDA0
U$7, U$121, U$187, U$253, U$319, U$385: EN0
U$9, U$66, U$140, U$206, U$272, U$338: CHARGING0
U$10, U$75, U$141, U$207, U$273, U$339: 9603N_POWER0
U$11, U$131, U$197, U$263, U$329, U$395: QWIIC_4MM
U$13, U$77, U$143, U$209, U$275, U$341: 150MA0
U$14, U$78, U$144, U$210, U$276, U$342: CHARGE0
U$15, U$79, U$145, U$211, U$277, U$343: CURRENT0
U$16, U$38, U$95, U$113, U$161, U$179, U$227, U$245, U$293, U$311, U$359, U$377: TX00
U$18, U$31, U$86, U$87, U$152, U$153, U$218, U$219, U$284, U$285, U$350, U$351: SCK0
U$19, U$88, U$154, U$220, U$286, U$352: GNSS0
U$23, U$34, U$91, U$114, U$157, U$180, U$223, U$246, U$289, U$312, U$355, U$378: RX00
U$25, U$132, U$198, U$264, U$330, U$396: QWIIC_5MM
U$26, U$30, U$135, U$201, U$267, U$333: SCL9
U$27, U$51, U$136, U$202, U$268, U$334: SDA8
U$29, U$64, U$111, U$115, U$177, U$181, U$243, U$247, U$309, U$313, U$375, U$379: SOLAR0
U$32, U$89, U$155, U$221, U$287, U$353: 5#3V0
U$33, U$90, U$156, U$222, U$288, U$354: RX0
U$35, U$92, U$158, U$224, U$290, U$356: RX10
U$36, U$93, U$159, U$225, U$291, U$357: SAFEBOOT0
U$37, U$94, U$160, U$226, U$292, U$358: TX0
U$39, U$96, U$162, U$228, U$294, U$360: TX10
U$40, U$97, U$163, U$229, U$295, U$361: ARTEMIS0
U$41, U$98, U$164, U$230, U$296, U$362: GLOBAL0
U$42, U$99, U$165, U$231, U$297, U$363: TRACKER0
U$43, U$100, U$166, U$232, U$298, U$364: PWR_LED0
U$44, U$101, U$167, U$233, U$299, U$365: VBUS0
U$45, U$46, U$57, U$105, U$116, U$117, U$171, U$182, U$183, U$237, U$248, U$249, U$303, U$314, U$315, U$369, U$380, U$381: LIPO0
U$47, U$103, U$169, U$235, U$301, U$367: 3#3V_EN0
U$48, U$102, U$168, U$234, U$300, U$366: MEAS0
U$49, U$118, U$184, U$250, U$316, U$382: RESET0
U$50, U$104, U$170, U$236, U$302, U$368: D190
U$53, U$56, U$119, U$120, U$185, U$186, U$251, U$252, U$317, U$318, U$383, U$384: USB#C0
U$58, U$122, U$188, U$254, U$320, U$386: #RST0
U$59, U$106, U$172, U$238, U$304, U$370: GND0
U$60, U$107, U$173, U$239, U$305, U$371: VIN0
U$61, U$108, U$174, U$240, U$306, U$372: 3_X_AA0
U$62, U$109, U$175, U$241, U$307, U$373: 3_X_AAA0
U$63, U$110, U$176, U$242, U$308, U$374: 6V_MAX0
U$65, U$112, U$178, U$244, U$310, U$376: VIN#30
U$67, U$68, U$123, U$124, U$189, U$190, U$255, U$256, U$321, U$322, U$387, U$388: D350
U$69, U$70, U$125, U$126, U$191, U$192, U$257, U$258, U$323, U$324, U$389, U$390: MISO0
U$71, U$72, U$127, U$128, U$193, U$194, U$259, U$260, U$325, U$326, U$391, U$392: MOSI0
U$73, U$74, U$129, U$130, U$195, U$196, U$261, U$262, U$327, U$328, U$393, U$394: D40
VIN/1, VIN/2, VIN/3, VIN/4, VIN/5, VIN/6: TEST-POINT3X5; PAD.03X.05
X1, X2, X3, X4, X5, X6, X7, X8, X9, X10, X11, X12: 32.768kHz; CRYSTAL-SMD-3.2X1.5MM

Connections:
3.3V: C1.1, C2.1, C7.1, C12.1, C20.2, C22.1, C23.1, C24.1, C25.1, C27.1, C28.1, D7.A, D11.A, D13.A, DEBUG.1, I2C.2, Q2.2, QWIIC.2, R1.2, R8.2, R12.2, R17.2, R26.2, SPI.7, U1.7, U1.10, U2.6, U2.9, U6.1, U7.VDD@36, U7.VDD@37, U8.3, U10.5
3.3V1: C35.1, C43.1, C46.2, C47.1, C48.1, C50.1, C51.1, C52.1, C58.1, C59.1, C60.1, D25.A, D27.A, D28.A, DEBUG1.1, I2C1.2, Q6.2, QWIIC1.2, R18.2, R36.2, R37.2, R41.2, R44.2, SPI1.7, U11.6, U11.9, U15.1, U16.VDD@36, U16.VDD@37, U18.7, U18.10, U19.5, U20.3
3.3V2: C65.1, C73.1, C76.2, C77.1, C78.1, C80.1, C81.1, C82.1, C88.1, C89.1, C90.1, D39.A, D41.A, D42.A, DEBUG2.1, I2C2.2, Q10.2, QWIIC2.2, R57.2, R64.2, R65.2, R69.2, R72.2, SPI2.7, U21.6, U21.9, U25.1, U26.VDD@36, U26.VDD@37, U28.7, U28.10, U29.5, U30.3
3.3V3: C95.1, C103.1, C106.2, C107.1, C108.1, C110.1, C111.1, C112.1, C118.1, C119.1, C120.1, D53.A, D55.A, D56.A, DEBUG3.1, I2C3.2, Q14.2, QWIIC3.2, R85.2, R92.2, R93.2, R97.2, R100.2, SPI3.7, U31.6, U31.9, U35.1, U36.VDD@36, U36.VDD@37, U38.7, U38.10, U39.5, U40.3
3.3V4: C125.1, C133.1, C136.2, C137.1, C138.1, C140.1, C141.1, C142.1, C148.1, C149.1, C150.1, D67.A, D69.A, D70.A, DEBUG4.1, I2C4.2, Q18.2, QWIIC4.2, R113.2, R120.2, R121.2, R125.2, R128.2, SPI4.7, U41.6, U41.9, U45.1, U46.VDD@36, U46.VDD@37, U48.7, U48.10, U49.5, U50.3
3.3V5: C155.1, C163.1, C166.2, C167.1, C168.1, C170.1, C171.1, C172.1, C178.1, C179.1, C180.1, D81.A, D83.A, D84.A, DEBUG5.1, I2C5.2, Q22.2, QWIIC5.2, R141.2, R148.2, R149.2, R153.2, R156.2, SPI5.7, U51.6, U51.9, U55.1, U56.VDD@36, U56.VDD@37, U58.7, U58.10, U59.5, U60.3
3V3SW: C13.1, Q2.3, R16.2, U4.24, U4.25, U5.6
3V3SW1: C39.1, Q6.3, R42.2, U13.24, U13.25, U14.6
3V3SW2: C69.1, Q10.3, R70.2, U23.24, U23.25, U24.6
3V3SW3: C99.1, Q14.3, R98.2, U33.24, U33.25, U34.6
3V3SW4: C129.1, Q18.3, R126.2, U43.24, U43.25, U44.6
3V3SW5: C159.1, Q22.3, R154.2, U53.24, U53.25, U54.6
ANTENNA: C16.1, J7.SIG
ANTENNA1: C42.1, J12.SIG
ANTENNA2: C72.1, J19.SIG
ANTENNA3: C102.1, J26.SIG
ANTENNA4: C132.1, J33.SIG
ANTENNA5: C162.1, J40.SIG
ARTEMIS_!RESET: !RESET.1, C29.1, C31.2, DEBUG.10, R26.1, S1.3, S1.4, U4.20, U7.~RST, U8.2
ARTEMIS_!RESET1: !RESET1.1, C53.2, C55.1, DEBUG1.10, R44.1, S2.3, S2.4, U13.20, U16.~RST, U20.2
ARTEMIS_!RESET2: !RESET2.1, C83.2, C85.1, DEBUG2.10, R72.1, S3.3, S3.4, U23.20, U26.~RST, U30.2
ARTEMIS_!RESET3: !RESET3.1, C113.2, C115.1, DEBUG3.10, R100.1, S4.3, S4.4, U33.20, U36.~RST, U40.2
ARTEMIS_!RESET4: !RESET4.1, C143.2, C145.1, DEBUG4.10, R128.1, S5.3, S5.4, U43.20, U46.~RST, U50.2
ARTEMIS_!RESET5: !RESET5.1, C173.2, C175.1, DEBUG5.10, R156.1, S6.3, S6.4, U53.20, U56.~RST, U60.2
ARTEMIS_!RTS!: C30.1, C31.1, U1.4
ARTEMIS_!RTS!1: C53.1, C54.1, U18.4
ARTEMIS_!RTS!2: C83.1, C84.1, U28.4
ARTEMIS_!RTS!3: C113.1, C114.1, U38.4
ARTEMIS_!RTS!4: C143.1, C144.1, U48.4
ARTEMIS_!RTS!5: C173.1, C174.1, U58.4
ARTEMIS_BOOT: C30.2, R27.2, U7.BOOT
ARTEMIS_BOOT1: C54.2, R45.2, U16.BOOT
ARTEMIS_BOOT2: C84.2, R73.2, U26.BOOT
ARTEMIS_BOOT3: C114.2, R101.2, U36.BOOT
ARTEMIS_BOOT4: C144.2, R129.2, U46.BOOT
ARTEMIS_BOOT5: C174.2, R157.2, U56.BOOT
ARTEMIS_D1: DEBUG1.6, U16.~AD33/SWO
ARTEMIS_D2: SPI1.5, U16.~AD35
ARTEMIS_D3: R53.1, R54.2, U16.~AD13, VIN/1.P$1
ARTEMIS_D4: SPI.6, U7.~D4
ARTEMIS_D5: R43.2, U16.~D19
ARTEMIS_D5_SCK: SPI.4, U7.~D5
ARTEMIS_D5_SCK1: SPI1.4, U16.~D5
ARTEMIS_D5_SCK2: SPI2.4, U26.~D5
ARTEMIS_D5_SCK3: SPI3.4, U36.~D5
ARTEMIS_D5_SCK4: SPI4.4, U46.~D5
ARTEMIS_D5_SCK5: SPI5.4, U56.~D5
ARTEMIS_D6: J8.19, U16.~D18
ARTEMIS_D6_MISO: SPI.3, U7.~D6
ARTEMIS_D6_MISO1: SPI1.3, U16.~D6
ARTEMIS_D6_MISO2: SPI2.3, U26.~D6
ARTEMIS_D6_MISO3: SPI3.3, U36.~D6
ARTEMIS_D6_MISO4: SPI4.3, U46.~D6
ARTEMIS_D6_MISO5: SPI5.3, U56.~D6
ARTEMIS_D7: J8.7, RX3.P$1, U16.~D25
ARTEMIS_D7_MOSI: SPI.2, U7.D7
ARTEMIS_D7_MOSI1: SPI1.2, U16.D7
ARTEMIS_D7_MOSI2: SPI2.2, U26.D7
ARTEMIS_D7_MOSI3: SPI3.2, U36.D7
ARTEMIS_D7_MOSI4: SPI4.2, U46.D7
ARTEMIS_D7_MOSI5: SPI5.2, U56.D7
ARTEMIS_D8: R19.2, U11.4, U16.~D27
ARTEMIS_D8_SCL: I2C.4, U4.32, U6.8, U7.D8
ARTEMIS_D8_SCL1: I2C1.4, U13.32, U15.8, U16.D8
ARTEMIS_D8_SCL2: I2C2.4, U23.32, U25.8, U26.D8
ARTEMIS_D8_SCL3: I2C3.4, U33.32, U35.8, U36.D8
ARTEMIS_D8_SCL4: I2C4.4, U43.32, U45.8, U46.D8
ARTEMIS_D8_SCL5: I2C5.4, U53.32, U55.8, U56.D8
ARTEMIS_D9: SPI1.6, U16.~D4
ARTEMIS_D9_SDA: I2C.3, U4.2, U6.7, U7.D9
ARTEMIS_D9_SDA1: I2C1.3, U13.2, U15.7, U16.D9
ARTEMIS_D9_SDA2: I2C2.3, U23.2, U25.7, U26.D9
ARTEMIS_D9_SDA3: I2C3.3, U33.2, U35.7, U36.D9
ARTEMIS_D9_SDA4: I2C4.3, U43.2, U45.7, U46.D9
ARTEMIS_D9_SDA5: I2C5.3, U53.2, U55.7, U56.D9
ARTEMIS_D10: U4.50, U7.D10
ARTEMIS_D11: U13.50, U16.D10
ARTEMIS_D12: J8.5, U16.D17
ARTEMIS_D13: R23.1, R24.2, U7.~AD13, VIN/3.P$1
ARTEMIS_D14: R39.1, U12.3, U16.~D22
ARTEMIS_D15: J8.6, TX3.P$1, U16.~D24
ARTEMIS_D16: Q6.1, R41.1, U16.~D26
ARTEMIS_D17: J1.5, U7.D17
ARTEMIS_D18: J1.19, U7.~D18
ARTEMIS_D19: R21.2, U7.~D19
ARTEMIS_D20: D16.C, R36.1, U11.5, U16.~D28
ARTEMIS_D21: J8.12, U16.D41
ARTEMIS_D22: R14.1, U3.3, U7.~D22
ARTEMIS_D23: R55.1, R56.1, U16.AD34
ARTEMIS_D24: J1.6, TX1.P$1, U7.~D24
ARTEMIS_D25: J1.7, RX1.P$1, U7.~D25
ARTEMIS_D26: Q2.1, R17.1, U7.~D26
ARTEMIS_D27: R5.2, U2.4, U7.~D27
ARTEMIS_D28: D2.C, R8.1, U2.5, U7.~D28
ARTEMIS_D29: DEBUG2.6, U26.~AD33/SWO
ARTEMIS_D30: SPI2.5, U26.~AD35
ARTEMIS_D31: R81.1, R82.2, U26.~AD13, VIN/2.P$1
ARTEMIS_D32: R71.2, U26.~D19
ARTEMIS_D33: DEBUG.6, U7.~AD33/SWO
ARTEMIS_D34: R25.1, R30.1, U7.AD34
ARTEMIS_D35: SPI.5, U7.~AD35
ARTEMIS_D36: J15.19, U26.~D18
ARTEMIS_D37: J15.7, RX5.P$1, U26.~D25
ARTEMIS_D38: R58.2, U21.4, U26.~D27
ARTEMIS_D39: SPI2.6, U26.~D4
ARTEMIS_D39_SCL1: QWIIC1.4, U16.~D39
ARTEMIS_D39_SCL2: QWIIC2.4, U26.~D39
ARTEMIS_D39_SCL3: QWIIC3.4, U36.~D39
ARTEMIS_D39_SCL4: QWIIC.4, U7.~D39
ARTEMIS_D39_SCL5: QWIIC4.4, U46.~D39
ARTEMIS_D39_SCL6: QWIIC5.4, U56.~D39
ARTEMIS_D40: U23.50, U26.D10
ARTEMIS_D40_SDA1: QWIIC1.3, U16.D40
ARTEMIS_D40_SDA2: QWIIC2.3, U26.D40
ARTEMIS_D40_SDA3: QWIIC3.3, U36.D40
ARTEMIS_D40_SDA4: QWIIC.3, U7.D40
ARTEMIS_D40_SDA5: QWIIC4.3, U46.D40
ARTEMIS_D40_SDA6: QWIIC5.3, U56.D40
ARTEMIS_D41: J1.12, U7.D41
ARTEMIS_D42: J15.5, U26.D17
ARTEMIS_D43: R67.1, U22.3, U26.~D22
ARTEMIS_D44: J15.6, TX5.P$1, U26.~D24
ARTEMIS_D45: Q10.1, R69.1, U26.~D26
ARTEMIS_D46: D30.C, R64.1, U21.5, U26.~D28
ARTEMIS_D47: J15.12, U26.D41
ARTEMIS_D48: R83.1, R84.1, U26.AD34
ARTEMIS_D49: DEBUG3.6, U36.~AD33/SWO
ARTEMIS_D50: SPI3.5, U36.~AD35
ARTEMIS_D51: R109.1, R110.2, U36.~AD13, VIN/4.P$1
ARTEMIS_D52: R99.2, U36.~D19
ARTEMIS_D53: J22.19, U36.~D18
ARTEMIS_D54: J22.7, RX7.P$1, U36.~D25
ARTEMIS_D55: R86.2, U31.4, U36.~D27
ARTEMIS_D56: SPI3.6, U36.~D4
ARTEMIS_D57: U33.50, U36.D10
ARTEMIS_D58: J22.5, U36.D17
ARTEMIS_D59: R95.1, U32.3, U36.~D22
ARTEMIS_D60: J22.6, TX7.P$1, U36.~D24
ARTEMIS_D61: Q14.1, R97.1, U36.~D26
ARTEMIS_D62: D44.C, R92.1, U31.5, U36.~D28
ARTEMIS_D63: J22.12, U36.D41
ARTEMIS_D64: R111.1, R112.1, U36.AD34
ARTEMIS_D65: DEBUG4.6, U46.~AD33/SWO
ARTEMIS_D66: SPI4.5, U46.~AD35
ARTEMIS_D67: R137.1, R138.2, U46.~AD13, VIN/5.P$1
ARTEMIS_D68: R127.2, U46.~D19
ARTEMIS_D69: J29.19, U46.~D18
ARTEMIS_D70: J29.7, RX9.P$1, U46.~D25
ARTEMIS_D71: R114.2, U41.4, U46.~D27
ARTEMIS_D72: SPI4.6, U46.~D4
ARTEMIS_D73: U43.50, U46.D10
ARTEMIS_D74: J29.5, U46.D17
ARTEMIS_D75: R123.1, U42.3, U46.~D22
ARTEMIS_D76: J29.6, TX9.P$1, U46.~D24
ARTEMIS_D77: Q18.1, R125.1, U46.~D26
ARTEMIS_D78: D58.C, R120.1, U41.5, U46.~D28
ARTEMIS_D79: J29.12, U46.D41
ARTEMIS_D80: R139.1, R140.1, U46.AD34
ARTEMIS_D81: DEBUG5.6, U56.~AD33/SWO
ARTEMIS_D82: SPI5.5, U56.~AD35
ARTEMIS_D83: R165.1, R166.2, U56.~AD13, VIN/6.P$1
ARTEMIS_D84: R155.2, U56.~D19
ARTEMIS_D85: J36.19, U56.~D18
ARTEMIS_D86: J36.7, RX11.P$1, U56.~D25
ARTEMIS_D87: R142.2, U51.4, U56.~D27
ARTEMIS_D88: SPI5.6, U56.~D4
ARTEMIS_D89: U53.50, U56.D10
ARTEMIS_D90: J36.5, U56.D17
ARTEMIS_D91: R151.1, U52.3, U56.~D22
ARTEMIS_D92: J36.6, TX11.P$1, U56.~D24
ARTEMIS_D93: Q22.1, R153.1, U56.~D26
ARTEMIS_D94: D72.C, R148.1, U51.5, U56.~D28
ARTEMIS_D95: J36.12, U56.D41
ARTEMIS_D96: R167.1, R168.1, U56.AD34
ARTEMIS_RX0: R2.1, RX0.P$1, U1.8, U7.RXI-0
ARTEMIS_RX1: R48.1, RX2.P$1, U16.RXI-0, U18.8
ARTEMIS_RX2: R76.1, RX4.P$1, U26.RXI-0, U28.8
ARTEMIS_RX3: R104.1, RX6.P$1, U36.RXI-0, U38.8
ARTEMIS_RX4: R132.1, RX8.P$1, U46.RXI-0, U48.8
ARTEMIS_RX5: R160.1, RX10.P$1, U56.RXI-0, U58.8
ARTEMIS_SWDCK: DEBUG.4, U7.SWDCK
ARTEMIS_SWDCK1: DEBUG1.4, U16.SWDCK
ARTEMIS_SWDCK2: DEBUG2.4, U26.SWDCK
ARTEMIS_SWDCK3: DEBUG3.4, U36.SWDCK
ARTEMIS_SWDCK4: DEBUG4.4, U46.SWDCK
ARTEMIS_SWDCK5: DEBUG5.4, U56.SWDCK
ARTEMIS_SWDIO: DEBUG.2, U7.SWDIO
ARTEMIS_SWDIO1: DEBUG1.2, U16.SWDIO
ARTEMIS_SWDIO2: DEBUG2.2, U26.SWDIO
ARTEMIS_SWDIO3: DEBUG3.2, U36.SWDIO
ARTEMIS_SWDIO4: DEBUG4.2, U46.SWDIO
ARTEMIS_SWDIO5: DEBUG5.2, U56.SWDIO
ARTEMIS_TX0: R3.1, TX0.P$1, U1.9, U7.TXO-0
ARTEMIS_TX1: R49.1, TX2.P$1, U16.TXO-0, U18.9
ARTEMIS_TX2: R77.1, TX4.P$1, U26.TXO-0, U28.9
ARTEMIS_TX3: R105.1, TX6.P$1, U36.TXO-0, U38.9
ARTEMIS_TX4: R133.1, TX8.P$1, U46.TXO-0, U48.9
ARTEMIS_TX5: R161.1, TX10.P$1, U56.TXO-0, U58.9
CC1: J11.B5, R50.2
CC2: J11.A5, R51.2
CC3: J2.B5, R4.2
CC4: J2.A5, R20.2
CC5: J18.B5, R78.2
CC6: J18.A5, R79.2
CC7: J25.B5, R106.2
CC8: J25.A5, R107.2
CC9: J32.B5, R134.2
CC10: J32.A5, R135.2
CC11: J39.B5, R162.2
CC12: J39.A5, R163.2
D+1: J11.A6, J11.B6, U18.1
D+2: J2.A6, J2.B6, U1.1
D+3: J18.A6, J18.B6, U28.1
D+4: J25.A6, J25.B6, U38.1
D+5: J32.A6, J32.B6, U48.1
D+6: J39.A6, J39.B6, U58.1
D-1: J11.A7, J11.B7, U18.2
D-2: J2.A7, J2.B7, U1.2
D-3: J18.A7, J18.B7, U28.2
D-4: J25.A7, J25.B7, U38.2
D-5: J32.A7, J32.B7, U48.2
D-6: J39.A7, J39.B7, U58.2
EXT_PWR: 5V3.P$1, J1.1, J1.2, Q1.2, R13.2, U5.4
EXT_PWR1: 5V1.P$1, J8.1, J8.2, Q5.2, R38.2, U14.4
EXT_PWR2: 5V2.P$1, J15.1, J15.2, Q9.2, R66.2, U24.4
EXT_PWR3: 5V4.P$1, J22.1, J22.2, Q13.2, R94.2, U34.4
EXT_PWR4: 5V5.P$1, J29.1, J29.2, Q17.2, R122.2, U44.4
EXT_PWR5: 5V6.P$1, J36.1, J36.2, Q21.2, R150.2, U54.4
GND: B1.-, C1.2, C2.2, C4.2, C6.-, C7.2, C8.2, C9.2, C10.2, C11.2, C12.2, C13.2, C17.2, C18.1, C19.1, C20.1, C21.2, C22.2, C23.2, C24.2, C25.2, C27.2, C28.2, C29.2, D1.C, D3.C, D4.C, D6.C, DEBUG.3, DEBUG.5, DEBUG.9, GND.1, I2C.1, J1.3, J1.4, J1.8, J1.13, J1.14, J1.15, J1.18, J1.HOLE1, J1.HOLE2, J2.GND, J2.GND2, J3.1, J5.1, J6.1, J6.2, J7.GND@0, J7.GND@1, J7.GND@2, J7.GND@3, Q4.2, QWIIC.1, R4.1, R5.1, R6.1, R7.2, R14.2, R20.1, R23.2, R27.1, R28.1, R30.2, S1.1, S1.2, SC2-.1, SPI.1, U1.3, U2.8, U2.11, U3.2, U4.1, U4.3, U4.5, U4.7, U4.8, U4.9, U4.10, U4.11, U4.12, U4.17, U4.23, U4.29, U4.31, U4.37, U4.38, U4.39, U4.40, U4.41, U4.44, U4.46, U4.47, U4.49, U5.2, U6.3, U7.GND@1, U7.GND@22, U7.GND@38, U7.GND@39, U7.GND@47, U7.GND@59, U8.1, U9.2, U10.2
GND1: B2.-, C32.-, C34.2, C35.2, C36.2, C37.2, C38.2, C39.2, C43.2, C44.1, C45.1, C46.1, C47.2, C48.2, C49.2, C50.2, C51.2, C52.2, C55.2, C56.2, C57.2, C58.2, C59.2, C60.2, D15.C, D17.C, D19.C, D20.C, DEBUG1.3, DEBUG1.5, DEBUG1.9, GND1.1, I2C1.1, J8.3, J8.4, J8.8, J8.13, J8.14, J8.15, J8.18, J8.HOLE1, J8.HOLE2, J9.1, J11.GND, J11.GND2, J12.GND@0, J12.GND@1, J12.GND@2, J12.GND@3, J13.1, J14.1, J14.2, Q8.2, QWIIC1.1, R19.1, R34.1, R35.2, R39.2, R45.1, R46.1, R50.1, R51.1, R53.2, R56.2, S2.1, S2.2, SC2-1.1, SPI1.1, U11.8, U11.11, U12.2, U13.1, U13.3, U13.5, U13.7, U13.8, U13.9, U13.10, U13.11, U13.12, U13.17, U13.23, U13.29, U13.31, U13.37, U13.38, U13.39, U13.40, U13.41, U13.44, U13.46, U13.47, U13.49, U14.2, U15.3, U16.GND@1, U16.GND@22, U16.GND@38, U16.GND@39, U16.GND@47, U16.GND@59, U17.2, U18.3, U19.2, U20.1
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

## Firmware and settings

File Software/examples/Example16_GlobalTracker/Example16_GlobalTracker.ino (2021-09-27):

/*
  Artemis Global Tracker
  
  Written by Paul Clark (PaulZC)
  September 7th 2021

  ** Updated for v2.1.0 of the Apollo3 core / Artemis board package **
  ** (At the time of writing, v2.1.1 of the core conatins a feature which makes communication with the u-blox GNSS problematic. Be sure to use v2.1.0) **

  ** Set the Board to "RedBoard Artemis ATP" **
  ** (The Artemis Module does not have a Wire port defined, which prevents the GNSS library from compiling) **

  This example builds on the BetterTracker example. Many settings are stored in EEPROM (Flash) and can be configured
  via the USB port (Serial Monitor) or via an Iridium binary message sent from Rock7 Operations.

  Messages can be sent automatically when:
  the tracker leaves or enters a geofenced area;
  pressure, humidity or temperature limits are exceeded;
  the battery voltage is low.

  Messages can be sent in text format (human-readable) or binary format (to save messages credits).

  You can configure which message fields are included in the message so you only send the data you need.
  You can find a Python3 PyQt5 configuration tool at:
  https://github.com/sparkfun/Artemis_Global_Tracker/tree/master/Tools

  You can trigger user-defined functions and include readings from additional sensors:
  https://github.com/sparkfun/Artemis_Global_Tracker/tree/master/Documentation/GlobalTracker_FAQs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
  https://github.com/sparkfun/Artemis_Global_Tracker/tree/master/Documentation/GlobalTracker_FAQs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

  You can have the Iridium 9603N monitor the ring channel continuously for new Mobile Terminated messages
  but this will increase the current draw considerably. This is not recommended for battery-powered
  applications. You will also need to increase WAKEINT, setting it to the same interval as both ALARMINT
  and TXINT.
  
  Likewise, if you want to enable geofence alarm messages, you will also need to increase WAKEINT.
  Set it to the same interval as ALARMINT.
  
  You will need to install version 3.0.5 of the Iridium SBD I2C library
  before this example will run successfully:
  https://github.com/sparkfun/SparkFun_IridiumSBD_I2C_Arduino_Library
  (Available through the Arduino Library Manager: search for IridiumSBDi2c)
  
  You will also need to install the Qwiic_PHT_MS8607_Library:
  https://github.com/sparkfun/SparkFun_PHT_MS8607_Arduino_Library
  (Available through the Arduino Library Manager: search for SparkFun MS8607)
  
  You will need to install the SparkFun u-blox library before this example will run successfully:
  https://github.com/sparkfun/SparkFun_u-blox_GNSS_Arduino_Library
  (Available through the Arduino Library Manager: search for SparkFun u-blox GNSS)
  
  Basic information on how to install an Arduino library is available here:
  https://learn.sparkfun.com/tutorials/installing-an-arduino-library
  
  SparkFun labored with love to create this code. Feel like supporting open source hardware?
  Buy a board from SparkFun!

  Version history:
  August 25th 2021
    Added a fix for https://github.com/sparkfun/Arduino_Apollo3/issues/423
  August 7th 2021
    Updated for v2.1 of the Apollo3 core
  December 15th, 2020:
    Adding the deep sleep code from OpenLog Artemis.
    Keep RAM powered up during sleep to prevent corruption above 64K.
    Restore busVoltagePin (Analog in) after deep sleep.
  June 7th, 2020:
    Original release

*/

// Artemis Global Tracker pin definitions
#define spiCS1              4  // D4 can be used as an SPI chip select or as a general purpose IO pin
#define geofencePin         10 // Input for the ZOE-M8Q's PIO14 (geofence) pin
#define busVoltagePin       13 // Bus voltage divided by 3 (Analog in)
#define iridiumSleep        17 // Iridium 9603N ON/OFF (sleep) pin: pull high to enable the 9603N
#define iridiumNA           18 // Input for the Iridium 9603N Network Available
#define LED                 19 // White LED
#define iridiumPwrEN        22 // ADM4210 ON: pull high to enable power for the Iridium 9603N
#define gnssEN              26 // GNSS Enable: pull low to enable power for the GNSS (via Q2)
#define superCapChgEN       27 // LTC3225 super capacitor charger: pull high to enable the super capacitor charger
#define superCapPGOOD       28 // Input for the LTC3225 super capacitor charger PGOOD signal
#define busVoltageMonEN     34 // Bus voltage monitor enable: pull high to enable bus voltage monitoring (via Q4 and Q3)
#define spiCS2              35 // D35 can be used as an SPI chip select or as a general purpose IO pin
#define iridiumRI           41 // Input for the Iridium 9603N Ring Indicator
// Make sure you do not have gnssEN and iridiumPwrEN enabled at the same time!
// If you do, bad things might happen to the AS179 RF switch!

// Include the u-blox library first so the message fields know about the dynModel enum
#include "SparkFun_u-blox_GNSS_Arduino_Library.h" //http://librarymanager/All#SparkFun_u-blox_GNSS
SFE_UBLOX_GNSS myGPS;

#include "Tracker_Message_Fields.h" // Include the message field and storage definitions
trackerSettings myTrackerSettings; // Create storage for the tracker settings in RAM

//#define noTX // Uncomment this line to disable the Iridium SBD transmit if you want to test the code without using message credits
//#define skipGNSS // Uncomment this line to skip getting a GNSS fix (only valid if noTX is defined too)

#include "RTC.h" //Include RTC library included with the Arduino_Apollo3 core

#include <EEPROM.h> // Needed for EEPROM storage on the Artemis

// We use Serial1 to communicate with the Iridium modem. Serial1 on the ATP uses pin 24 for TX and 25 for RX. AGT uses the same pins.

#include <IridiumSBD.h> //http://librarymanager/All#IridiumSBDI2C
#define DIAGNOSTICS false // Change this to true to see IridiumSBD diagnostics
// Declare the IridiumSBD object (including the sleep (ON/OFF) and Ring Indicator pins)
IridiumSBD modem(Serial1, iridiumSleep, iridiumRI);

#include <Wire.h> // Needed for I2C
const byte PIN_AGTWIRE_SCL = 8;
const byte PIN_AGTWIRE_SDA = 9;
TwoWire agtWire(PIN_AGTWIRE_SDA, PIN_AGTWIRE_SCL); //Create an I2C port using pads 8 (SCL) and 9 (SDA)

#include <SparkFun_PHT_MS8607_Arduino_Library.h> //http://librarymanager/All#SparkFun_MS8607
MS8607 barometricSensor; //Create an instance of the MS8607 object

// iterationCounter is incremented each time a transmission is attempted.
// It helps keep track of whether messages are being sent successfully.
// It also indicates if the tracker has been reset (the count will go back to zero).
long iterationCounter = 0;

// Use these to keep a count of the seconds from the rtc
volatile unsigned long seconds_since_last_wake = 0;
volatile unsigned long seconds_since_last_alarmtx = 0;
volatile unsigned long seconds_since_last_tx = 0;

// This flag indicates an interval alarm has occurred
volatile bool interval_alarm = false;

// This flag indicates the geofence pin has changed state
volatile bool geofence_alarm = false;

// Volatile copy of the WAKEINT (wake up interval)
volatile uint32_t wake_int;

// More global variables
bool PGOOD = false; // Flag to indicate if LTC3225 PGOOD is HIGH
int err; // Error value returned by IridiumSBD.begin
bool firstTime = true; // Flag to indicate if this is the first time around the loop (so we go right round the loop and not just check the PHT)
int delayCount; // General-purpose delay count used by non-blocking delays
bool alarmState = false; // Use this to keep track of whether we are in an alarm state
uint8_t alarmType = 0; // Field to save which alarm has been set off
bool dynamicModelSet = false; // Flag to indicate if the ZOE-M8Q dynamic model has been set
bool geofencesSet = false; // Flag to indicate if the ZOE-M8Q geofences been set

// geofence_alarm will be set to true by the ISR
// but we only want to send geofence alarm messages every ALARMINT
// so let's use sendGeofenceAlarm to record if a geofence alarm message should be sent
// as geofence_alarm may have been cleared by then
bool sendGeofenceAlarm = false;

uint8_t tracker_serial_rx_buffer[1024]; // Define tracker_serial_rx_buffer which will store the incoming serial configuration data
size_t tracker_serial_rx_buffer_size; // The size of the buffer
unsigned long rx_start; // Used by check_for_serial_data: holds the value of millis after a fresh start
unsigned long last_rx; // Used by check_for_serial_data: holds the value of millis for the last time a byte was received
bool data_seen; // Used by check_for_serial_data: is set to true once byte(s) have been seen after a fresh start

uint8_t mt_buffer[(MTLIM + 1)]; // Buffer to store a Mobile Terminated SBD message (with space for a final NULL)
size_t mtBufferSize; // Size of MT buffer

bool _printDebug = false; // Flag to show if message field debug printing is enabled
Stream *_debugSerial; //The stream to send debug messages to (if enabled)

// Timeout after this many _minutes_ when waiting for a 3D GNSS fix
// (UL = unsigned long)
#define GNSS_timeout 5UL

// Timeout after this many _minutes_ when waiting for the super capacitors to charge
// 1 min should be OK for 1F capacitors at 150mA.
// Charging 10F capacitors at 60mA can take a long time! Could be as much as 10 mins.
#define CHG_timeout 2UL

// Top up the super capacitors for this many _seconds_ to make sure they are fully charged.
// 10 seconds should be OK for 1F capacitors at 150mA.
// Increase the value for 10F capacitors.
#define TOPUP_timeout 10UL

// Loop Steps - these are used by the switch/case in the main loop
// This structure makes it easy to go from any of the steps directly to zzz when (e.g.) the batteries are low
typedef enum {
  loop_init = 0, // Send the welcome message, check the battery voltage
  read_pressure, // Read the pressure and temperature from the MS8607
  start_GPS,     // Enable the ZOE-M8Q, check the battery voltage
  read_GPS,      // Wait for up to GNSS_timeout minutes for a valid 3D fix, check the battery voltage
  start_LTC3225, // Enable the LTC3225 super capacitor charger and wait for up to CHG_timeout minutes for PGOOD to go high
  wait_LTC3225,  // Wait TOPUP_timeout seconds to make sure the capacitors are fully charged
  start_9603,    // Power on the 9603N, send the message, check the battery voltage
  sleep_9603,    // Put the 9603N to sleep
  zzz,           // Turn everything off and put the processor into deep sleep
  wakeUp,        // Wake from deep sleep, restore the processor clock speed
  wait_for_ring, // Keep the 9603N powered up and wait for a ring indication
  configureMe    // Configure the tracker settings via USB Serial
} loop_steps;
volatile loop_steps loop_step = loop_init; // Make sure loop_step is set to loop_init
volatile loop_steps last_loop_step = loop_init; // Go back to this loop_step after doing a configure

// RTC alarm Interrupt Service Routine
// Clear the interrupt flag and increment the seconds_since_last_...
// If WAKEINT has been reached, set the interval_alarm flag and reset seconds_since_last_wake
// (Always keep ISRs as short as possible, don't do anything clever in them,
//  and always use volatile variables if the main loop needs to access them too.)
extern "C" void am_rtc_isr(void)
{
  // Clear the RTC alarm interrupt
  rtc.clearInterrupt();

  // Increment seconds_since_last_...
  seconds_since_last_wake = seconds_since_last_wake + 1;
  seconds_since_last_alarmtx = seconds_since_last_alarmtx + 1;
  seconds_since_last_tx = seconds_since_last_tx + 1;

  // Check if interval_alarm should be set
  if (seconds_since_last_wake >= wake_int)
  {
    interval_alarm = true;
    seconds_since_last_wake = 0;
  }
}

// geofencePin Interrupt Service Routine
// (Always keep ISRs as short as possible, don't do anything clever in them,
//  and always use volatile variables if the main loop needs to access them too.)
void geofenceISR(void)
{
  geofence_alarm = true; // Set the flag
}

void gnssON(void) // Enable power for the GNSS
{
  am_hal_gpio_pincfg_t pinCfg = g_AM_HAL_GPIO_OUTPUT; // Begin by making the gnssEN pin an open-drain output
  pinCfg.eGPOutcfg = AM_HAL_GPIO_PIN_OUTCFG_OPENDRAIN;
  pin_config(PinName(gnssEN), pinCfg);
  delay(1);
  
  digitalWrite(gnssEN, LOW); // Enable GNSS power (HIGH = disable; LOW = enable)
}

void gnssOFF(void) // Disable power for the GNSS
{
  am_hal_gpio_pincfg_t pinCfg = g_AM_HAL_GPIO_OUTPUT; // Begin by making the gnssEN pin an open-drain output
  pinCfg.eGPOutcfg = AM_HAL_GPIO_PIN_OUTCFG_OPENDRAIN;
  pin_config(PinName(gnssEN), pinCfg);
  delay(1);
  
  digitalWrite(gnssEN, HIGH); // Disable GNSS power (HIGH = disable; LOW = enable)
}

// Overwrite the IridiumSBD beginSerialPort function - a fix for https://github.com/sparkfun/Arduino_Apollo3/issues/423
void IridiumSBD::beginSerialPort() // Start the serial port connected to the satellite modem
{
  diagprint(F("custom IridiumSBD::beginSerialPort\r\n"));
  
  // Configure the standard ATP pins for UART1 TX and RX - endSerialPort may have disabled the RX pin
  
  am_hal_gpio_pincfg_t pinConfigTx = g_AM_BSP_GPIO_COM_UART_TX;
  pinConfigTx.uFuncSel = AM_HAL_PIN_24_UART1TX;
  pin_config(D24, pinConfigTx);
  
  am_hal_gpio_pincfg_t pinConfigRx = g_AM_BSP_GPIO_COM_UART_RX;
  pinConfigRx.uFuncSel = AM_HAL_PIN_25_UART1RX;
  pinConfigRx.ePullup = AM_HAL_GPIO_PIN_PULLUP_WEAK; // Put a weak pull-up on the Rx pin
  pin_config(D25, pinConfigRx);
  
  Serial1.begin(19200);
}

// Overwrite the IridiumSBD endSerialPort function - a fix for https://github.com/sparkfun/Arduino_Apollo3/issues/423
void IridiumSBD::endSerialPort()
{
  diagprint(F("custom IridiumSBD::endSerialPort\r\n"));
  
  // Disable the Serial1 RX pin to avoid the code hang
  am_hal_gpio_pinconfig(PinName(D25), g_AM_HAL_GPIO_DISABLE);
}
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
void loop()
{
  // loop is one large switch/case that controls the sequencing of the code
  switch (loop_step) {

    // ************************************************************************************************
    // Initialise things
    case loop_init:
    {
      // Start the console serial port and send the welcome message
      Serial.begin(115200);
      Serial.println();
      Serial.println();
      Serial.println(F("Artemis Global Tracker"));
      Serial.print(F("Software Version: "));
      Serial.print((DEF_SWVER & 0xf0) >> 4); // DEF_SWVER is defined in Tracker_Message_Fields.h
      Serial.print(F("."));
      Serial.println(DEF_SWVER & 0x0f);
      Serial.println();
      Serial.println();

      //enableDebugging(Serial); // Uncomment this line to enable extra debug messages to Serial

      if (_printDebug == true)
      {
        // If debugging is enabled: print the tracker EEPROM contents as text
        Serial.println(F("EEPROM contents (remember that data is little endian!):"));
        displayEEPROMcontents();
        Serial.println();
      }

      // Print the tracker settings from RAM as text - if debugging is enabled
      printTrackerSettings(&myTrackerSettings);

      // Make sure the serial Rx buffer is empty - keep reading characters until available is false
      while (Serial.available() > 0)
      {
        Serial.read(); // Read a single character from the buffer and discard it
      }

      // Print the configuration message
      Serial.println(F("Ready to accept configuration settings via Serial..."));
      Serial.println();
      Serial.println();

      // Setup the IridiumSBD
      modem.setPowerProfile(IridiumSBD::USB_POWER_PROFILE); // Change power profile to "low current"

      loop_step = read_pressure; // Move on, check the PHT readings (in case we need to send an alarm message)
    }
    break; // End of case loop_init

    // ************************************************************************************************
    // Read the pressure and temperature from the MS8607
    case read_pressure:
    {
      Serial.println(F("Getting the PHT readings..."));

      agtWire.begin(); // Set up the I2C pins
      agtWire.setClock(100000); // Use 100kHz for best performance
      setAGTWirePullups(1); // MS8607 needs pull-ups

      bool barometricSensorOK;
      barometricSensorOK = barometricSensor.begin(agtWire); // Begin the PHT sensor
      if (barometricSensorOK == false)
      {
        // Send a warning message if we were unable to connect to the MS8607:
        Serial.println(F("*** Could not detect the MS8607 sensor. Trying again... ***"));
        barometricSensorOK = barometricSensor.begin(agtWire); // Re-begin the PHT sensor
        if (barometricSensorOK == false)
        {
          // Send a warning message if we were unable to connect to the MS8607:
          Serial.println(F("*** MS8607 sensor not detected at default I2C address ***"));
        }
      }

      if (barometricSensorOK == false) // If the sensor is not OK
      {
        // Set the pressure and temperature to default values
        myTrackerSettings.PRESS.the_data = DEF_PRESS;
        myTrackerSettings.TEMP.the_data = DEF_TEMP;
        myTrackerSettings.HUMID.the_data = DEF_HUMID;
      }
      else // The sensor is OK so let's read and print the PHT values
      {
        myTrackerSettings.PRESS.the_data = (uint16_t)(barometricSensor.getPressure()); // mbar
        myTrackerSettings.TEMP.the_data = (int16_t)(barometricSensor.getTemperature() * 100.0); // Convert to °C * 10^-2
        myTrackerSettings.HUMID.the_data = (uint16_t)(barometricSensor.getHumidity() * 100.0); // Convert to %RH * 10^-2

        Serial.print(F("Pressure (mbar): "));
        Serial.println(myTrackerSettings.PRESS.the_data);
        Serial.print(F("Temperature (C * 10^-2): "));
        Serial.println(myTrackerSettings.TEMP.the_data);
        Serial.print(F("Humidity (%RH * 10^-2): "));
        Serial.println(myTrackerSettings.HUMID.the_data);
      }

      alarmState = false; // Clear the alarm state
      alarmType = 0; // Clear the alarm type

      // Check if a PHT alarm has occurred
      if ( (myTrackerSettings.PRESS.the_data != DEF_PRESS) && // If measurement is valid
           (myTrackerSettings.PRESS.the_data > myTrackerSettings.HIPRESS.the_data) ) // Check if HIPRESS has been exceeded
      {
        alarmType |= ALARM_HIPRESS;
        if ((myTrackerSettings.FLAGS1 & FLAGS1_HIPRESS) == FLAGS1_HIPRESS) // If the HIPRESS alarm is enabled
        {
          alarmState = true;
          Serial.println(F("*** HIPRESS Alarm! ***"));
        }
      }
      if ( (myTrackerSettings.PRESS.the_data != DEF_PRESS) && // If measurement is valid
           (myTrackerSettings.PRESS.the_data < myTrackerSettings.LOPRESS.the_data) ) // Check if LOPRESS has been exceeded
      {
        alarmType |= ALARM_LOPRESS;
        if ((myTrackerSettings.FLAGS1 & FLAGS1_LOPRESS) == FLAGS1_LOPRESS) // If the LOPRESS alarm is enabled
        {
          alarmState = true;
          Serial.println(F("*** LOPRESS Alarm! ***"));
        }
      }
      if ( (myTrackerSettings.TEMP.the_data != DEF_TEMP) && // If measurement is valid
           (myTrackerSettings.TEMP.the_data > myTrackerSettings.HITEMP.the_data) ) // Check if HITEMP has been exceeded
      {
        alarmType |= ALARM_HITEMP;
        if ((myTrackerSettings.FLAGS1 & FLAGS1_HITEMP) == FLAGS1_HITEMP) // If the HITEMP alarm is enabled
        {
          alarmState = true;
          Serial.println(F("*** HITEMP Alarm! ***"));
        }
      }
      if ( (myTrackerSettings.TEMP.the_data != DEF_TEMP) && // If measurement is valid
           (myTrackerSettings.TEMP.the_data < myTrackerSettings.LOTEMP.the_data) ) // Check if LOTEMP has been exceeded
      {
        alarmType |= ALARM_LOTEMP;
        if ((myTrackerSettings.FLAGS1 & FLAGS1_LOTEMP) == FLAGS1_LOTEMP) // If the LOTEMP alarm is enabled
        {
          alarmState = true;
          Serial.println(F("*** LOTEMP Alarm! ***"));
        }
      }
      if ( (myTrackerSettings.HUMID.the_data != DEF_HUMID) && // If measurement is valid
           (myTrackerSettings.HUMID.the_data > myTrackerSettings.HIHUMID.the_data) ) // Check if HIHUMID has been exceeded
      {
        alarmType |= ALARM_HIHUMID;
        if ((myTrackerSettings.FLAGS1 & FLAGS1_HIHUMID) == FLAGS1_HIHUMID) // If the HIHUMID alarm is enabled
        {
          alarmState = true;
          Serial.println(F("*** HIHUMID Alarm! ***"));
        }
      }
      if ( (myTrackerSettings.HUMID.the_data != DEF_HUMID) && // If measurement is valid
           (myTrackerSettings.HUMID.the_data < myTrackerSettings.LOHUMID.the_data) ) // Check if LOHUMID has been exceeded
      {
        alarmType |= ALARM_LOHUMID;
        if ((myTrackerSettings.FLAGS1 & FLAGS1_LOHUMID) == FLAGS1_LOHUMID) // If the LOHUMID alarm is enabled
        {
          alarmState = true;
          Serial.println(F("*** LOHUMID Alarm! ***"));
        }
      }
      // Check battery voltage
      // If voltage is lower than LOWBATT, send an alarm message
      get_vbat(); // Get the battery (bus) voltage
      if (myTrackerSettings.BATTV.the_data < myTrackerSettings.LOWBATT.the_data) {
        alarmType |= ALARM_LOBATT;
        Serial.print(F("*** LOWBATT: "));
        Serial.print((((float)myTrackerSettings.BATTV.the_data)/100.0),2);
        Serial.println(F("V ***"));
        if ((myTrackerSettings.FLAGS2 & FLAGS2_LOWBATT) == FLAGS2_LOWBATT) // If the LOWBATT alarm is enabled
        {
          alarmState = true;
          Serial.println(F("*** LOWBATT Alarm! ***"));
        }
      }
      // If an alarm has fired, execute alarm user function
      if (alarmType) {
        ALARM_FUNC(alarmType); // Execute alarm user function
      }

      loop_step = start_GPS; // Get ready to move on and start the GPS

      // Send a message:
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

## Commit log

2020-05-13 Copying over PaulZC/Artemis_Global_Tracker
    [Artemis_Global_Tracker-Panel.GBL, Artemis_Global_Tracker-Panel.GBO, Artemis_Global_Tracker-Panel.GBP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]
2020-05-19 Added the bus voltage correction factor
    [Example14_SimpleTracker.ino, Example15_BetterTracker.ino, Example17_ProductionTest.ino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]
2020-07-22 Added Example18: Production Test Part Deux
    Example 18 check that the ZOE can obtain a 3D fix and that the Iridium modem can read satellite time. The AGT can be powered from a LiPo cell for this test. The white LED indicates success / failure.
    [Example18_ProductionTestPart2.ino]
2020-12-15 Corrections for deep sleep - to prevent RAM corruption
    [Example12_TestLowPower.ino, Example15_BetterTracker.ino, Example16_GlobalTracker.ino]
2021-07-07 Bugfix in binary message contruction in example 16
    [Example16_GlobalTracker.ino]
2021-08-25 v2.1: update the examples to correct issue 423 in the Apollo3 core
    https://github.com/sparkfun/Arduino_Apollo3/issues/423
    [Example10_BasicSend.ino, Example11_Ring.ino, Example14_SimpleTracker.ino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]
2021-09-04 Bugfix regarding negative temperature measurements
    [Example16_GlobalTracker.ino]
2021-09-07 Adding modem.endSerialPort to the Iridium examples setup - to resolve #38 and hopefully #36 too
    [Example10_BasicSend.ino, Example11_Ring.ino, Example14_SimpleTracker.ino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]

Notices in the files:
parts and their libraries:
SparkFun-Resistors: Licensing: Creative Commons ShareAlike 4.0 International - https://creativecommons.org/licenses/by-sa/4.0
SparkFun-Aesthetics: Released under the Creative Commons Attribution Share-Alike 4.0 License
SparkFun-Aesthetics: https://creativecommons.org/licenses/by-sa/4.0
